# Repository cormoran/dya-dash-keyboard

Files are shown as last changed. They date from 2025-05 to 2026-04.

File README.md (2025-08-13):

#  DYA Dash Split Keyboard

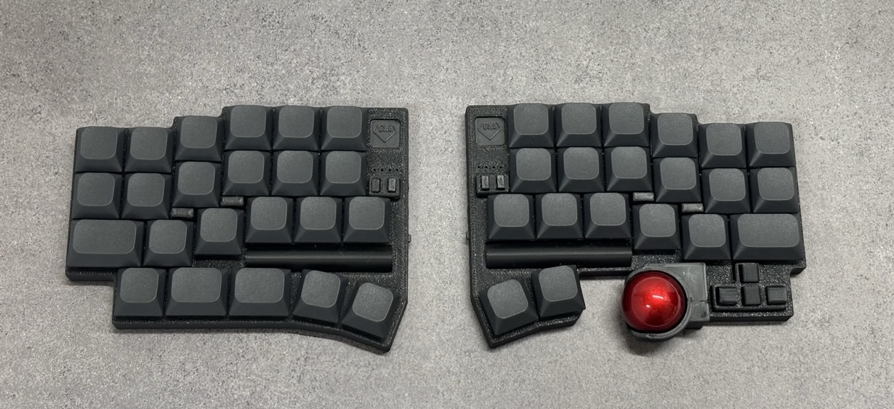
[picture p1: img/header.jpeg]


## Features

- Controller: XIAO NRF52840
- Firmware: ZMK
- Switch: Kailh Choc v2, hotswappable (2pin)
- AAA battery (1.2V NiMH or 1.5V)
- Touch sensor buttons ([See movie how it works](https://x.com/cormoran707/status/1916127921720463540))
- PMW3610 low power trackball sensor
- LED x 4 x 2 for BLE profile, battery level indication ([See movie how it works](https://youtu.be/y6X2OnoMX-M))
- Hardware capability for below features (Not tested yet)
  - Dual trackball support
  - Wired connection

## Build Guide

- [V2.0 ビルドガイド](./hardware/dya-dash/build-guide/v2/BuildGuide.md)
- [V1.0 (試作) ビルドガイド](./hardware/dya-dash/build-guide/v1/BuildGuide.md)

## Firmware

Firmware is available in https://github.com/cormoran/zmk-keyboard-dya-dash.

You can download pre-built binaries in [the release page](https://github.com/cormoran/zmk-keyboard-dya-dash/releases).

The firmware supports keymapping update with [ZMK studio](https://zmk.studio/).

## Gallery

### Schematic

Left side schematic

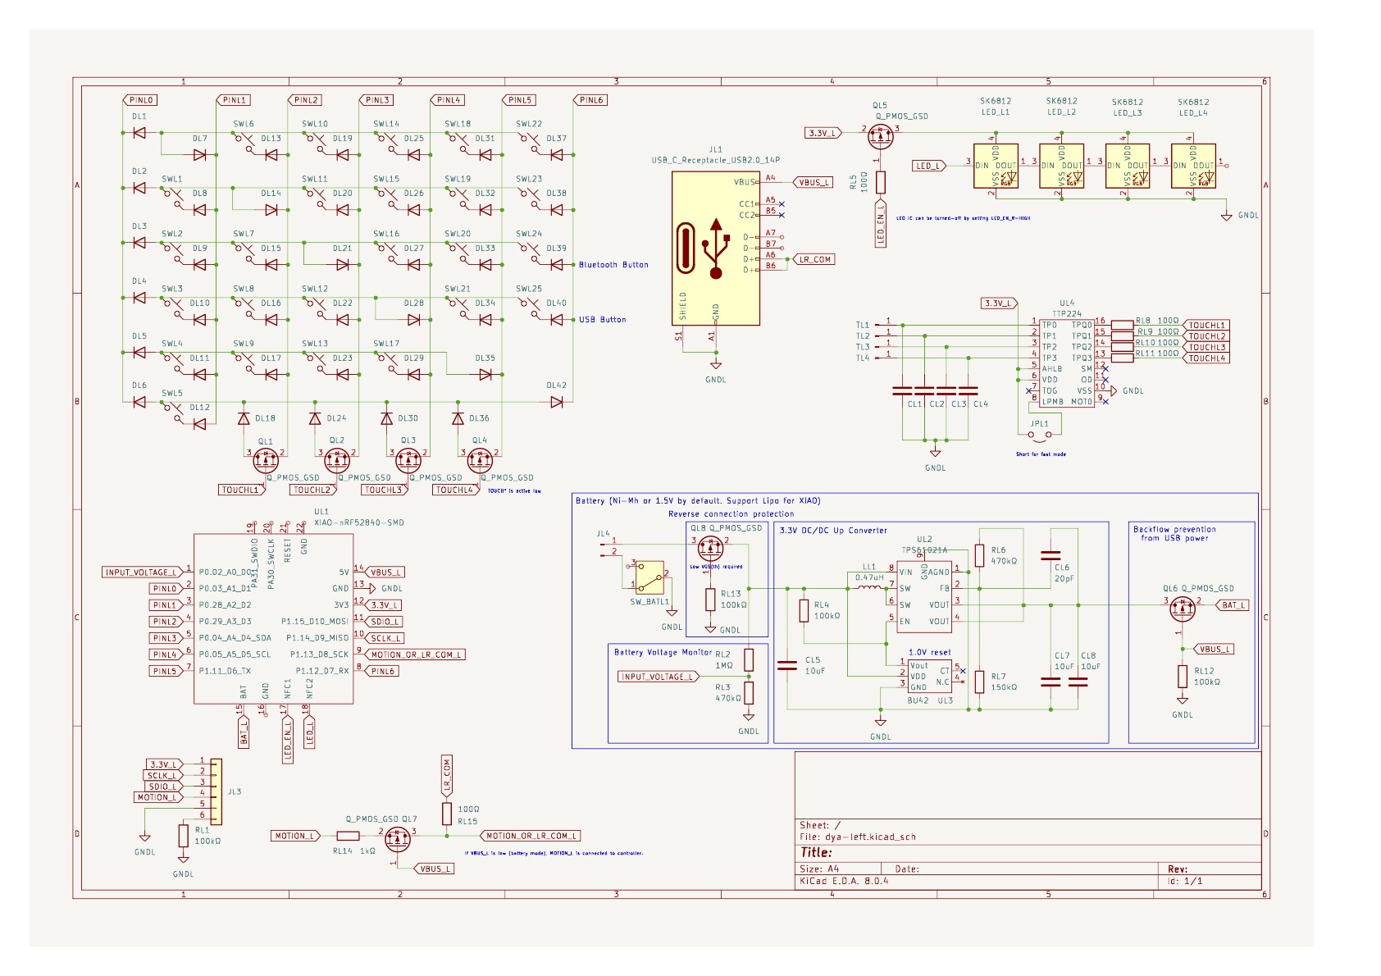
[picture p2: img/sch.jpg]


### Double trackball supported

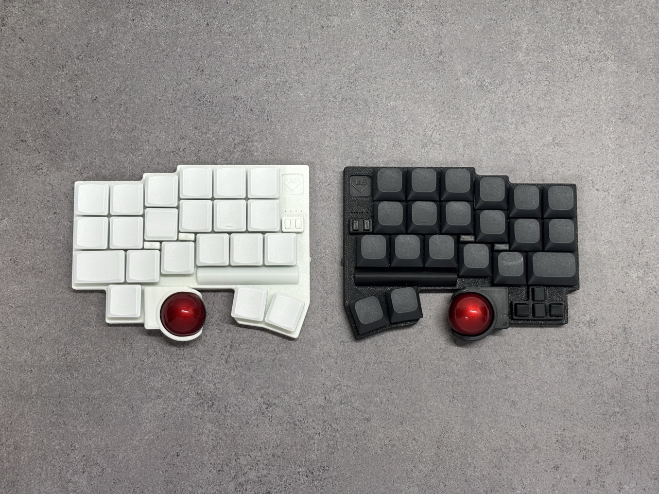
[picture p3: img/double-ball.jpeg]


### Colors

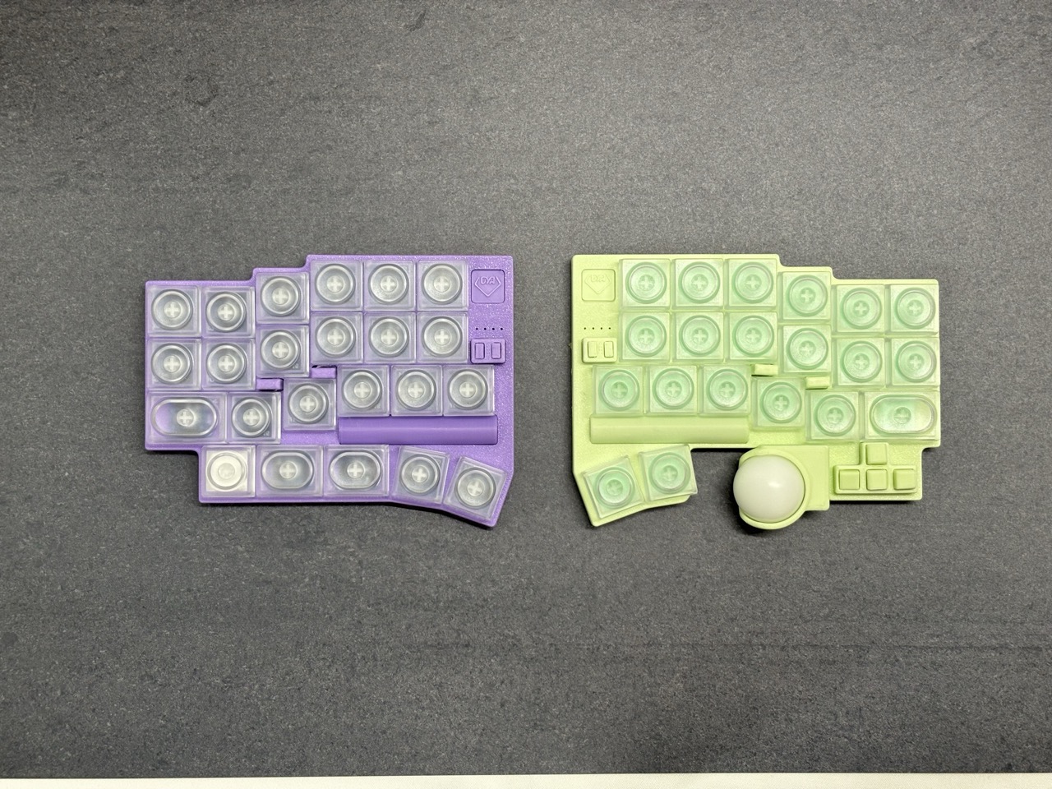
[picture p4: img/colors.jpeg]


### Bottom

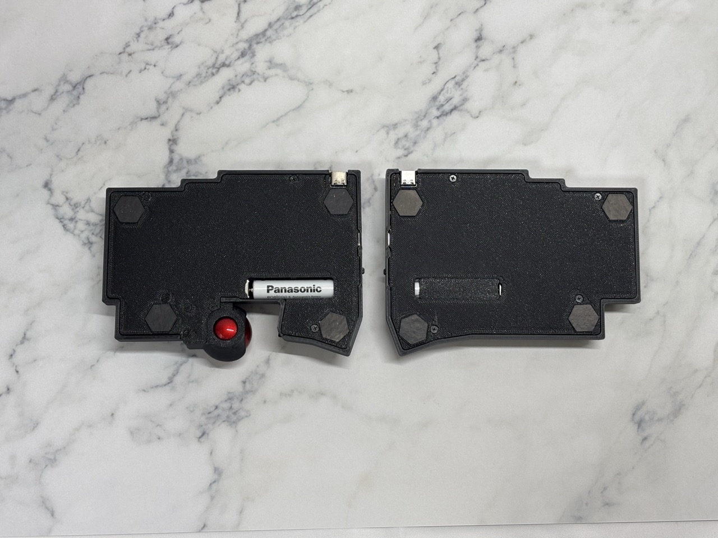
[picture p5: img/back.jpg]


### LED indicators

4x2 LEDs indicates battery level, connected BLE/USB profiles and active layers depending on the setting.
The schematic and firmware driver is optimized for battery usage. LED modules consume power only when required.

> [!NOTE]
> The picture is old version's one

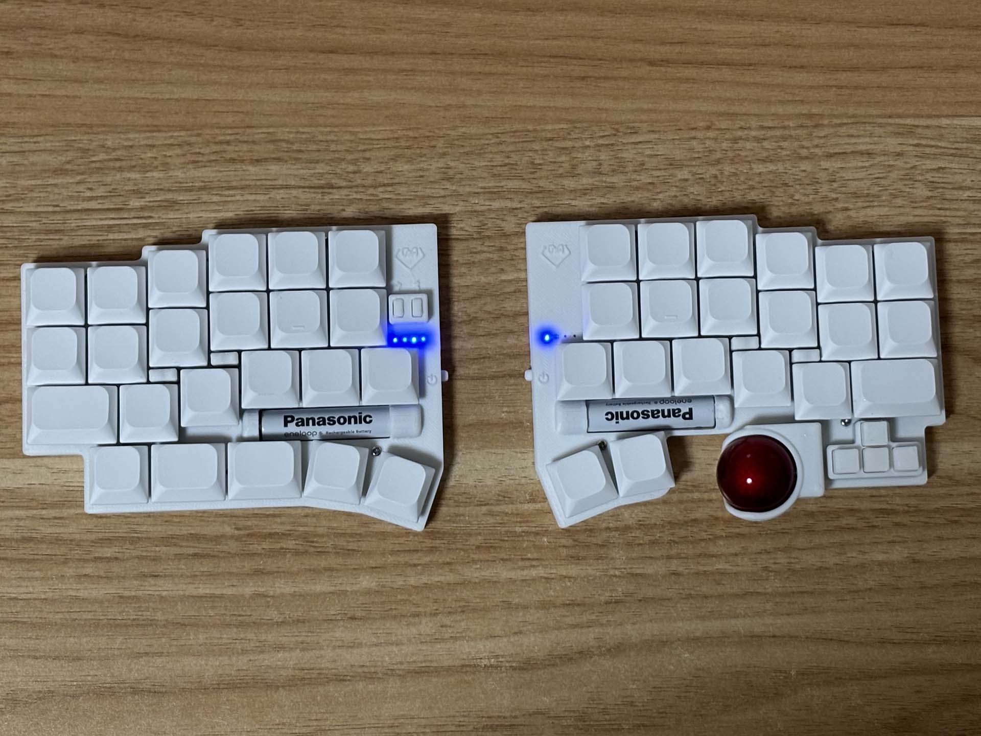
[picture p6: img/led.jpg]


## Shop

Now on sale in https://cormoran707.booth.pm/

## License

- Firmware (./firmware): MIT. See detail in each git submodule.
- DYA logo  (./img/dya.svg): All rights reserved.
- Other keyboard pictures under ./img: CC BY
- Hardware
  - kicad library (./hardware/kicad_library/\*) and sch (\*.kicad_sch): MIT
  - PCB (\*.kicad_pcb): CC BY-NC
  - Case data (\*.stl): CC BY

完全なコピー品が販売された場合に対応できるように PCB 設計を流用して販売することは禁止していますが、回路設計を真似たり似たような設計のキーボードを作ることを牽制したりする意図はありません。

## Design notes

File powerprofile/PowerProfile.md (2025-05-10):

# DYA Dash Power Profiling

- Tool: https://www.nordicsemi.jp/tools/ppk2/
- Battery: [Panasonic eneloop AAA(単４)](https://panasonic.jp/battery/feature/eneloop.html) 1.2V 800mAh boosted to 3.3V

## Setup

- Normal status: LED module can be ON if LED is used. Otherwise OFF. BLE is ON.
- Idle status: LED module is OFF, BLE is ON.
- Deep sleep: all power off except for GPIO interrupt and PMW3610.

No key press. No trackball movement in below data.
Power consumption increases more when key pressed or trackball is moving.
Profiling analysis for daily usage is coming soon...

## Peripheral

Idle status consumes 1.05mA in avg.

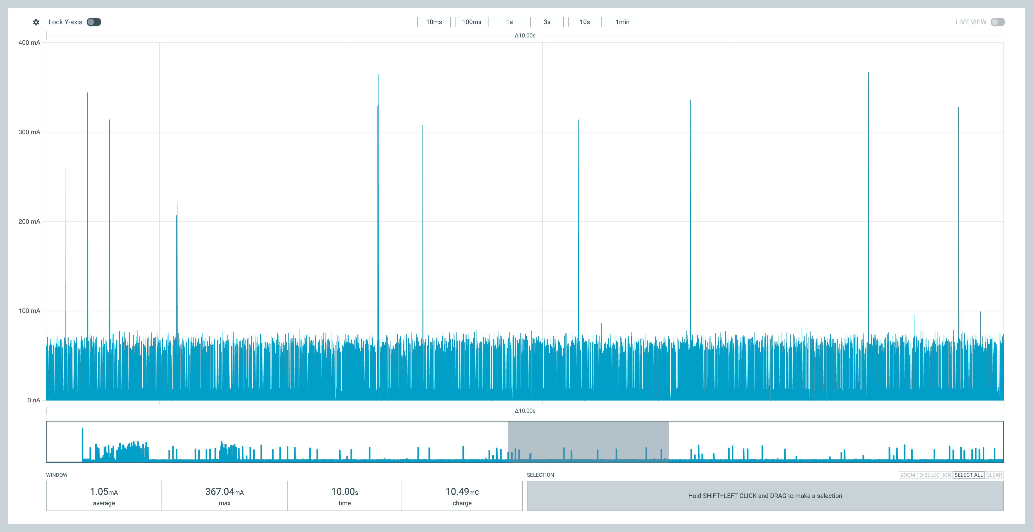
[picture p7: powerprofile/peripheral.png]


## Central

Normal status with LED module OFF consumes 3.81mA in avg.

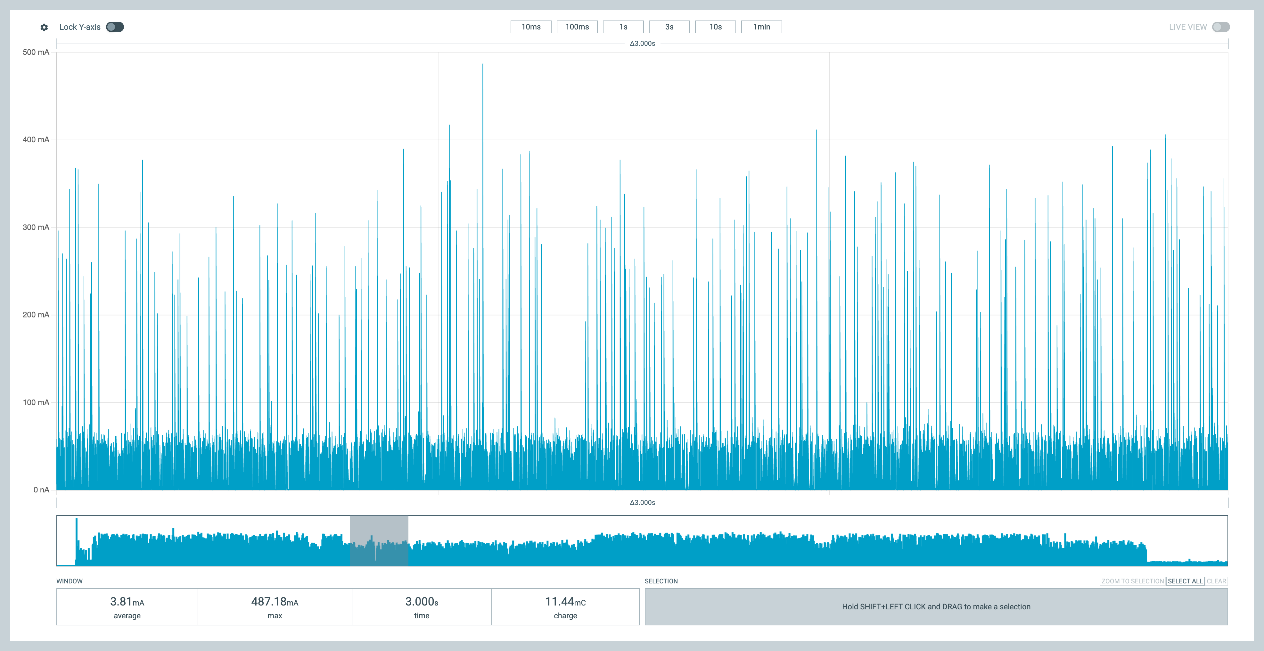
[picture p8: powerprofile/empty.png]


Normal status with LED module ON (RGB=black(0,0,0)) consumes 8.40mA in avg.
The increase is likely due to RGB LED module's embedded chip.

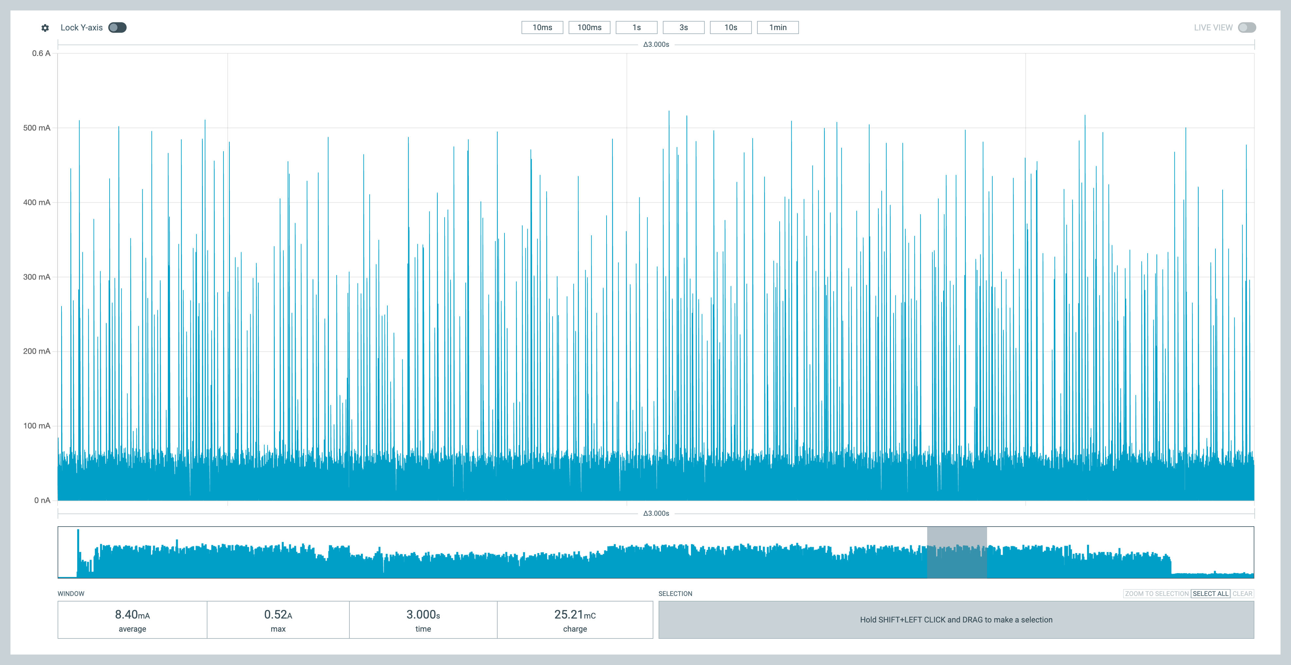
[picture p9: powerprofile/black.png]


Normal status with Red LED ON (Brightness is adjusted to very small) consumes 15.07mA.

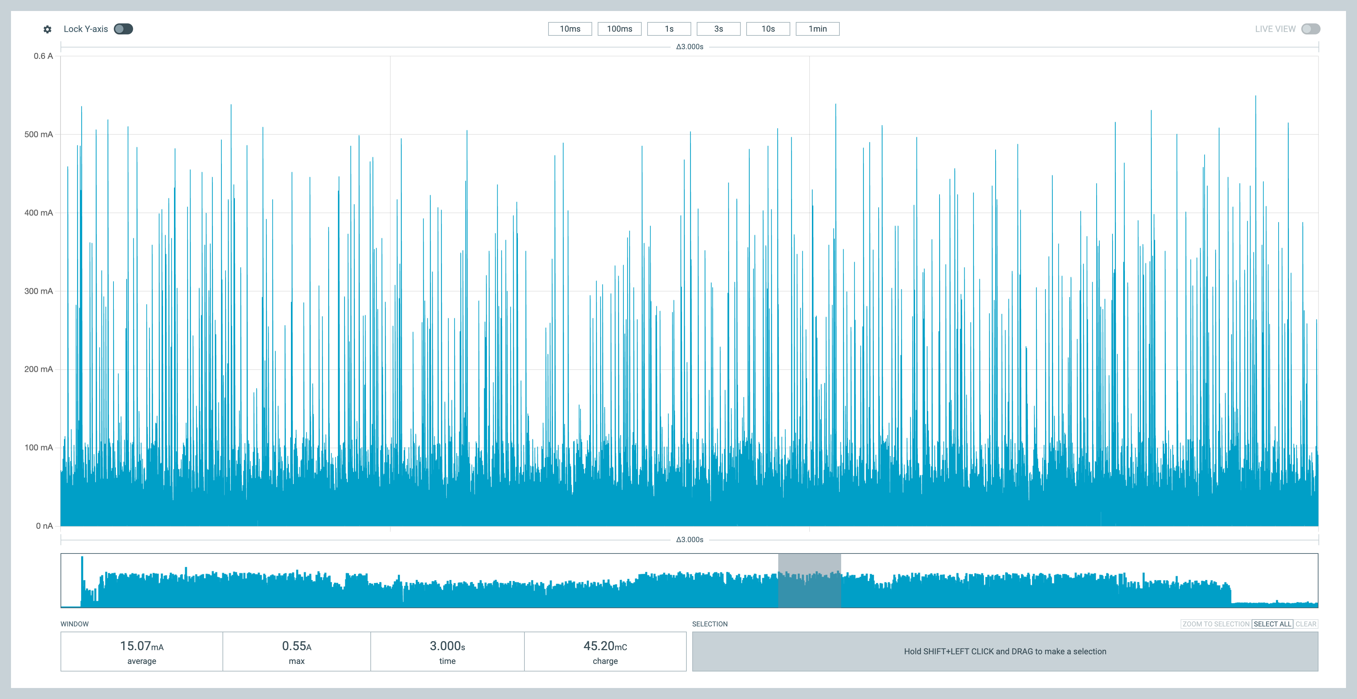
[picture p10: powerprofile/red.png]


Deep sleep mode consumes 270uA.

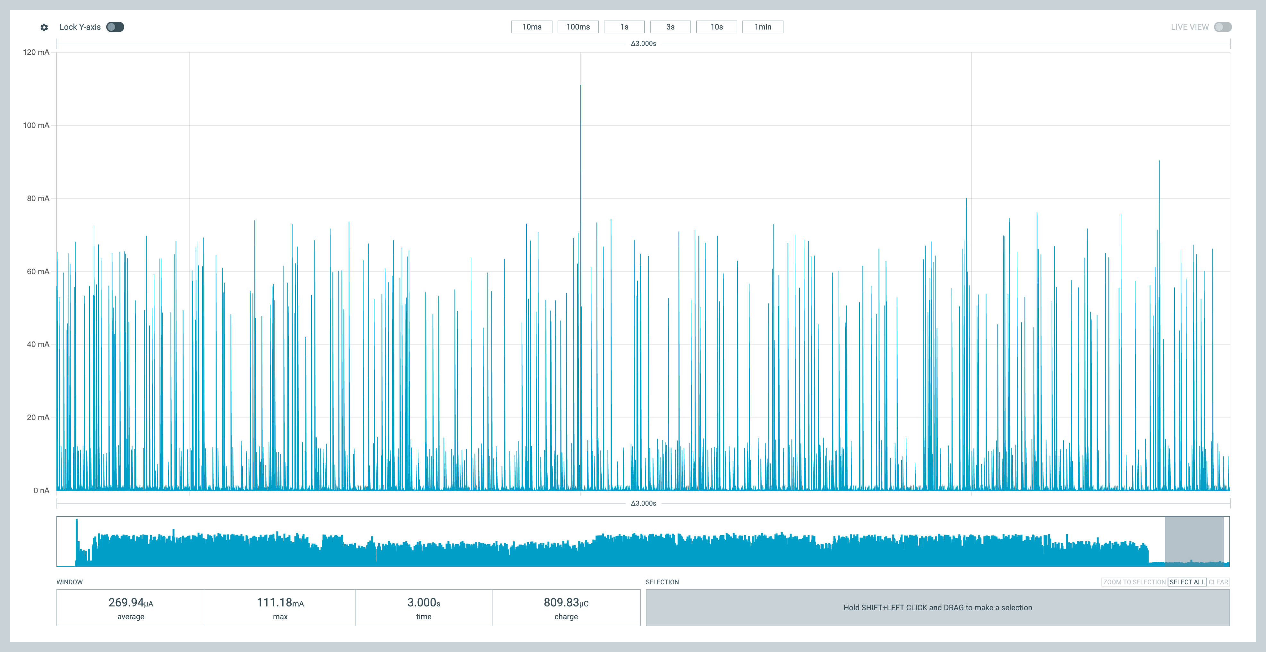
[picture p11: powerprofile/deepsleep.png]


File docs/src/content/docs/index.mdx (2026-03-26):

---
title: DYA Dash
template: splash
hero:
  title: |
    DYA Logo
    DYA Dash
  tagline: 電池で動く分割型トラックボール付きキーボード
  image:
    file: ../../assets/header.jpeg
    alt: DYA Dash キーボード
  actions:
    - text: ビルドガイド(V3)
      link: /dya-dash-keyboard/build-guide/v3/
      icon: right-arrow
      variant: primary
    - text: 設計データ
      link: https://github.com/cormoran/dya-dash-keyboard
      icon: github
      variant: secondary
    - text: ビルドキットを購入
      link: https://cormoran707.booth.pm/items/6913095
      icon: information
      variant: minimal
---

import { Card, CardGrid } from "@astrojs/starlight/components";

## 特徴

<CardGrid>
  <Card title="無線左右分割キーボード">
    自由な手の位置でタイピングできます。

    裏側にはマグネットが付いており、持ち運びを考えた設計になっています。

  </Card>
  <Card title="25mm トラックボール内蔵">
    マウスを持ち替えることなく、カーソル操作が可能です。

    外出先でもトラックボールを使った快適な操作ができます。

  </Card>
  <Card title="タッチセンサー搭載">
    トラックボールのスクロールモード切り替えなどに使えるタッチセンサーを左右に4つ(V2 までは2つ)ずつ搭載しています。
  </Card>
  <Card title="電池駆動" >
    左右はそれぞれ単４電池１本ずつで動作します。

    リチウムポリマーバッテリーと比べて発火の心配が低く、安心して使用できます。

  </Card>
  <Card title="配列">
    Column Staggered 配列の美しさと使い慣れた Row Staggered 配列の特徴を兼ね備えています。

    Column Staggered 配列が合わない方でも違和感が少なく使えるように設計されています。

  </Card>
  <Card title="自由なカスタマイズ">
    ZMKファームウェアを使っておりソースコードも公開しているので、キーマップやマクロ、細かな振る舞いを自由にカスタマイズできます。
  </Card>
</CardGrid>

## 写真

import doubleBall from "../../assets/double-ball.jpeg";
import colors from "../../assets/colors.jpeg";
import back from "../../assets/back.jpg";
import led from "../../assets/led.jpg";

<CardGrid>

<Card>
  
</Card>

<Card>
  
</Card>

<Card>
  
</Card>

<Card>
  
</Card>

</CardGrid>

## バージョン情報

V3, rev3 という表記の揺れがありますが、V と rev は両方同じものを指しています。紛らわしくてすみません。

- **V3** (2026/03) - 現在の最新版。マイコンを XIAO nRF52840 Plus 変更、内部構造を大幅に変更。後方互換性なし。
- **V2** (2025/06) - 正式販売版（V1.1 と命名しても良かった）
- **V1** (2025/05) - 試作版

## サポート

- **販売・サポート**: [Booth](https://cormoran707.booth.pm)
- **技術情報・ソースコード**: [GitHub](https://github.com/cormoran/dya-dash-keyboard)
- **最新情報**: X [@cormoran707](https://twitter.com/cormoran707)

---

_このドキュメントサイトは半分 AI に作ってもらいました。_

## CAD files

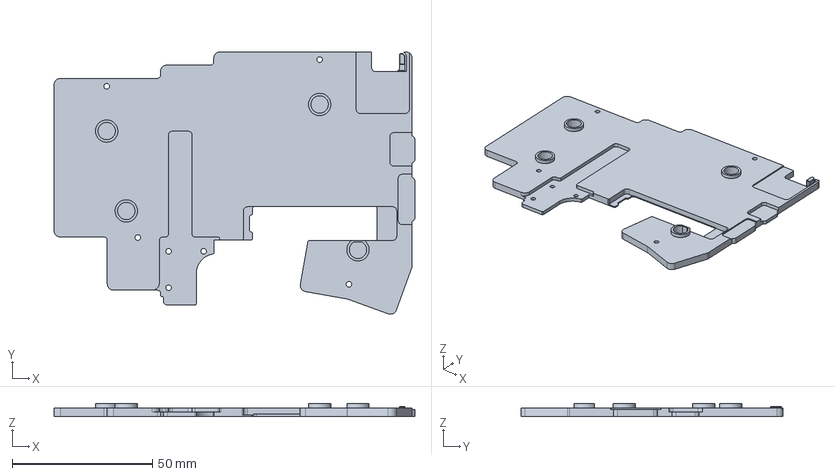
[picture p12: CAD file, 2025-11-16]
hardware/dya-dash/case/V2.1/DyaDashBottomCaseLeftTrackball.step
128.8 x 93.7 x 4.50 mm

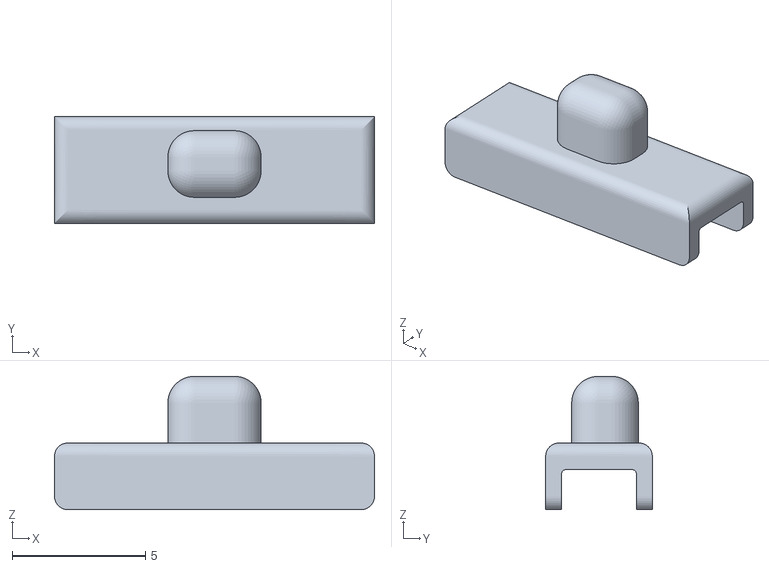
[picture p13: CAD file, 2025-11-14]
hardware/dya-dash/case/V2.1/BatterySwitch.stl
12.0 x 4.00 x 5.00

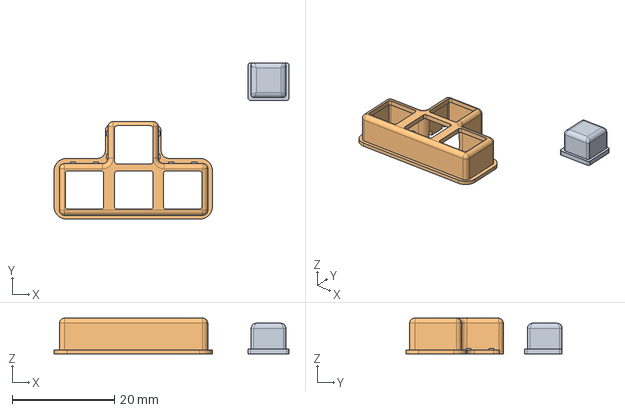
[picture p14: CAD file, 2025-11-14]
hardware/dya-dash/case/V2.1/ArrowButton.step
46.0 x 30.6 x 7.00 mm

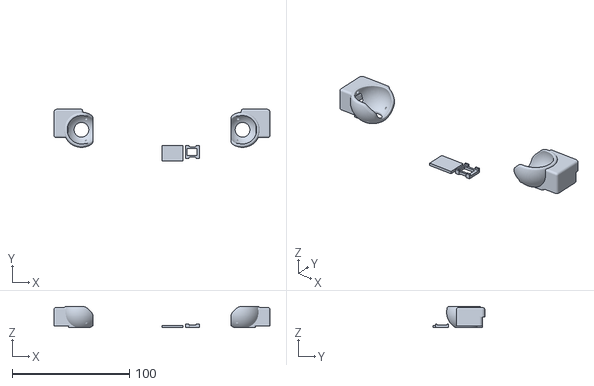
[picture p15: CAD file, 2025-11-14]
hardware/dya-dash/case/V2.1/Trackball.stl
184.0 x 43.9 x 18.0

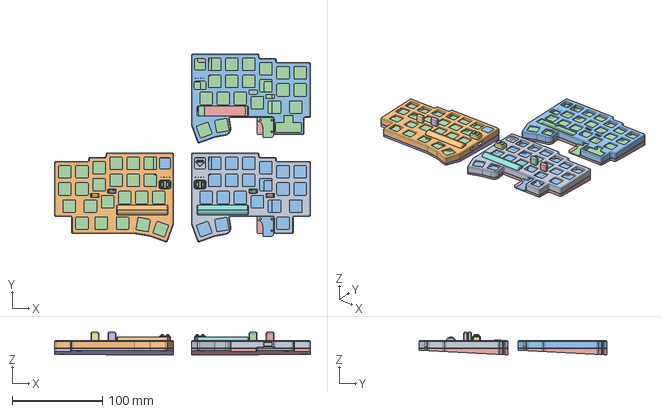
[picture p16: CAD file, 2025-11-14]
hardware/dya-dash/case/V2.1/DyaDash.step
284.4 x 208.9 x 25.3 mm

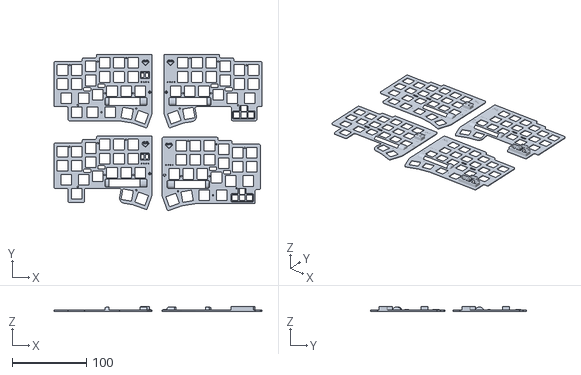
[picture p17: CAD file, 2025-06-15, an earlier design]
hardware/dya-dash/case/V1/top-3dp.stl
280.0 x 210.4 x 7.00

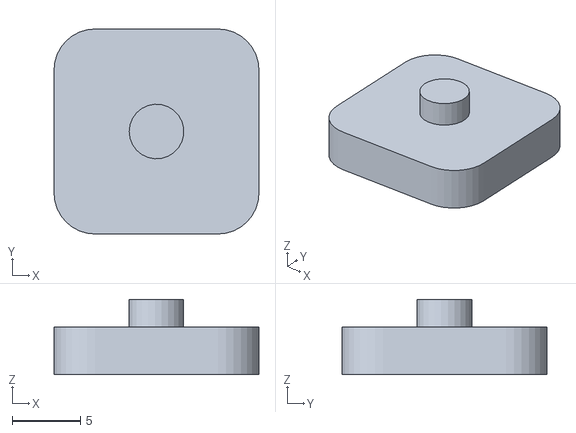
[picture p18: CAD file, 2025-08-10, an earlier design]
hardware/dya-dash/case/V2/Parts_Zig.stl
15.0 x 15.0 x 5.50

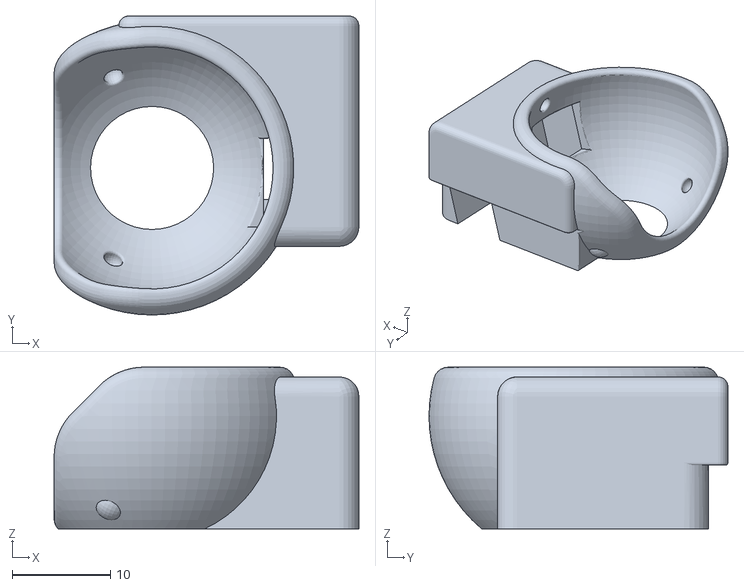
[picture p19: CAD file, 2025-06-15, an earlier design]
hardware/dya-dash/case/V1/trackball-right.stl
31.1 x 30.5 x 16.5

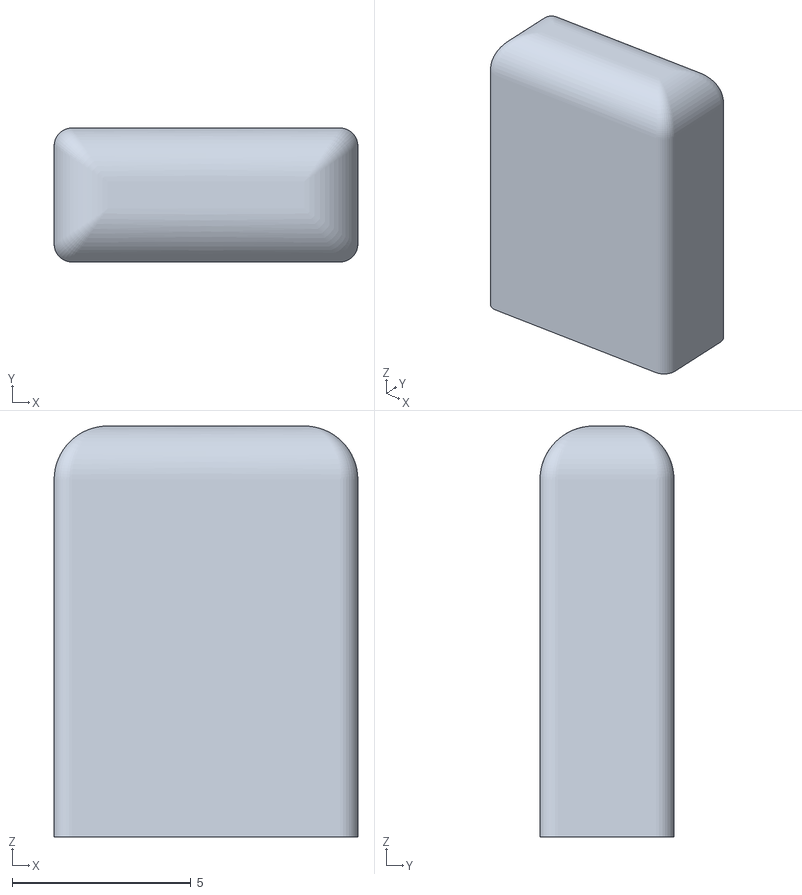
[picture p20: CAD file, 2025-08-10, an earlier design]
hardware/dya-dash/case/V2/Parts_TouchButton.stl
8.50 x 3.75 x 11.5

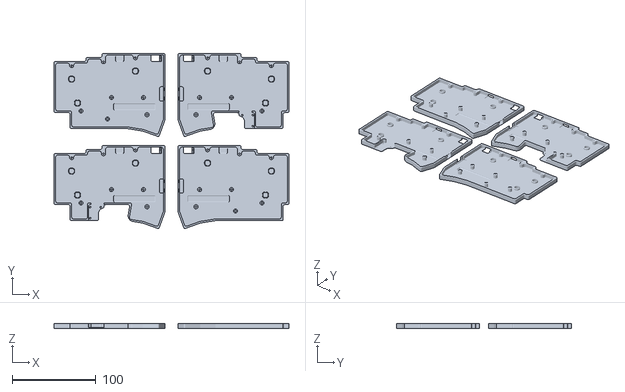
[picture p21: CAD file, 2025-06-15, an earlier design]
hardware/dya-dash/case/V1/bottom.stl
280.0 x 208.5 x 6.00

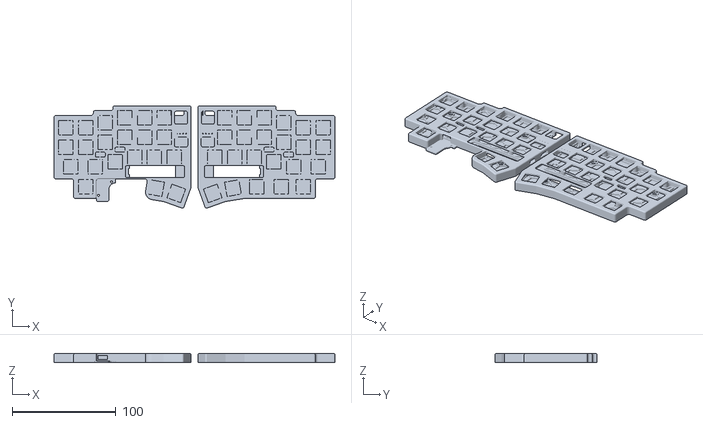
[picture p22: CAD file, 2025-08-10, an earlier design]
hardware/dya-dash/case/V2/Case_LeftTrackball_NoArrow.stl
271.3 x 98.9 x 8.50

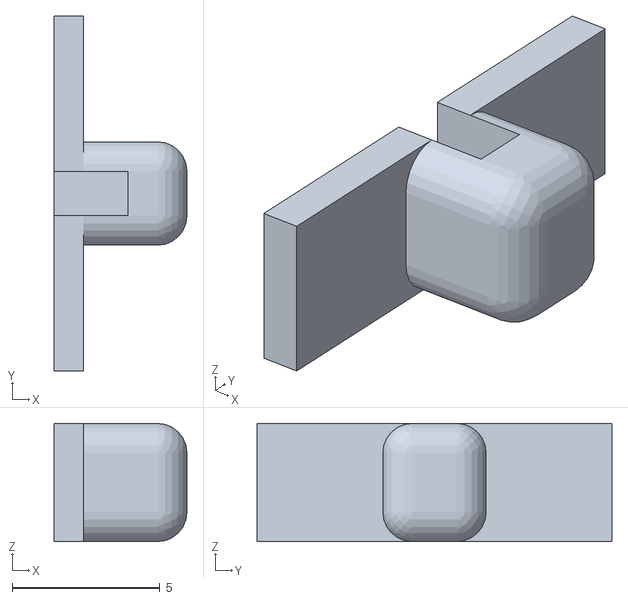
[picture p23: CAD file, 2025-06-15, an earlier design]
hardware/dya-dash/case/V1/battery-button.stl
4.50 x 12.0 x 4.00

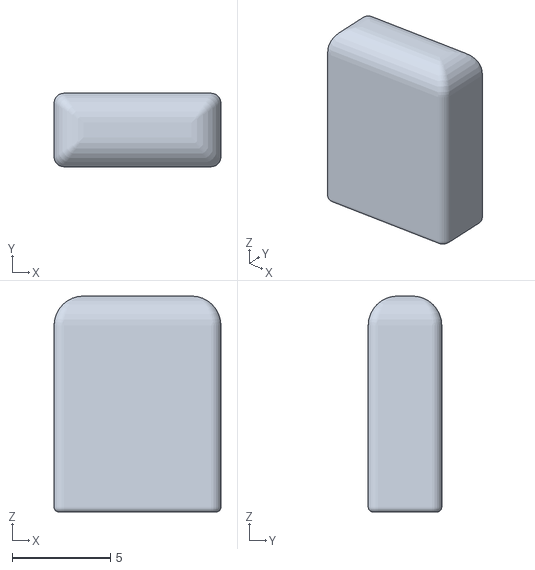
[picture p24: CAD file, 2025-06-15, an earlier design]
hardware/dya-dash/case/V1/touch-button.stl
8.50 x 3.75 x 11.0

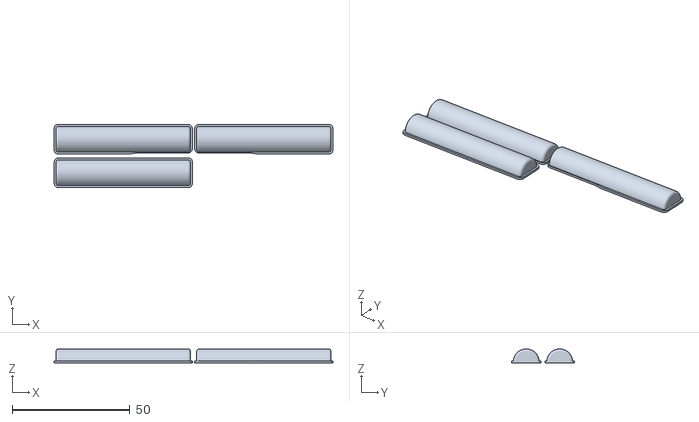
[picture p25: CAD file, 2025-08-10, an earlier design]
hardware/dya-dash/case/V2/Parts_BatteryTopCovers.stl
118.4 x 26.9 x 6.00

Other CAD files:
hardware/dya-dash/case/V2/Parts_Arrow.stl
hardware/dya-dash/case/V1/trackball-left.stl
hardware/dya-dash/case/V2/Parts_PowerSwitch.stl
hardware/dya-dash/case/V1/arrow-button.stl
hardware/dya-dash/case/V2/Case_DualTrackball_NoArrow.stl
hardware/dya-dash/case/V2/Case_RightTrackball_NoArrow.stl
hardware/dya-dash/case/V2/Case_RightTrackball_WithArrow.stl
hardware/dya-dash/case/V2/Parts_BatteryBottomCover.stl
hardware/dya-dash/case/V2/Parts_Emblem_dya-dash-for-jlcpcb-emblem v2.stl
hardware/dya-dash/case/V2/Parts_SettingButton.stl
hardware/dya-dash/case/V2/Parts_SettingCover.stl
hardware/dya-dash/case/V2/TrackballCase_Adjuster.stl
hardware/dya-dash/case/V2/TrackballCase_Left.stl
hardware/dya-dash/case/V2/TrackballCase_Right.stl

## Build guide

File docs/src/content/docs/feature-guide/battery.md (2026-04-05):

---
title: バッテリー残量表示
sidebar:
  order: 5
---

:::note

こちらのページの情報は V2, V3 共通です。画像は V2 のものですが内容は同じです。

:::

電源を入れた際に左右のバッテリー残量が LED に表示されます。

バッテリー残量は、４つの LED x 3 色で 12 段階表示されます。

- ４つの LED: 左から 25%ずつに対応
- 色: 残量が多い側から緑 → 黄 → 赤で変化

例えば下の図で、左手の緑緑緑は以下のように読みます

- ４つ目が点灯していないので -25%で 75%以下
- ３つ目が緑なので、50%から 75%の間で残量が多い方（３分割した一番多い区間にある）

右手の緑緑黄状態は以下のように読みます

- ４つ目が点灯していないので -25%で 75%以下
- ３つ目が黄色なので、50%から 75%の間でちょうど真ん中あたり（３分割した真ん中の区間にある）

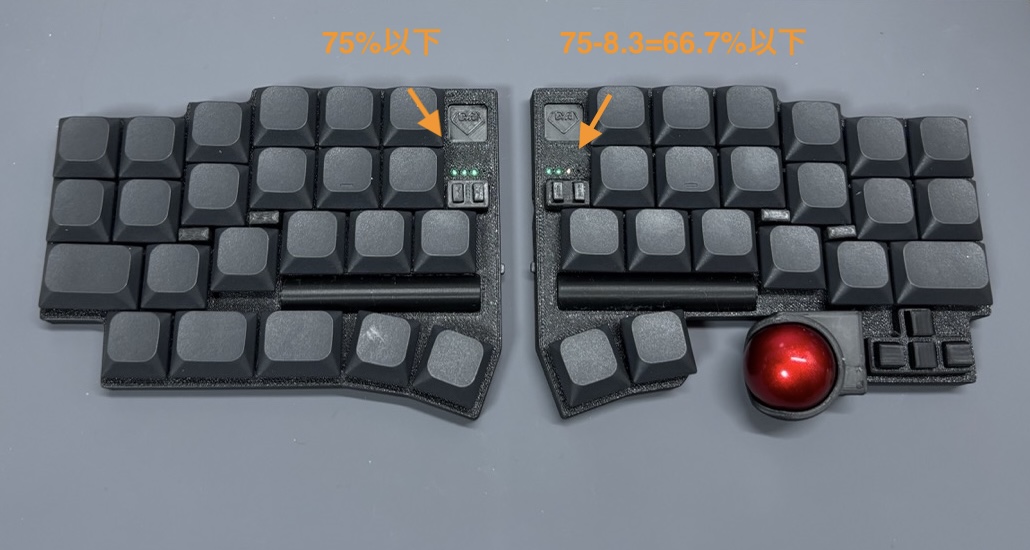
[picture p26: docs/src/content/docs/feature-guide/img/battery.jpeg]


:::note

残量表示はニッケル水素電池の電圧曲線に従って実装していますが、回路による電圧降下もあるため、実態に則しているかはまだあまり詳しく調べられていません。

全然違う気がした場合は教えてください。

:::

## 残量を確認する方法

電源を切らずに残量を確認するためには、左手左下+t を押します。
しばらくの間 LED が電池残量を表示します。

その他、残量がすくなくなったら定期的に LED をアラート点灯させる機能もついています。

## 電池持ちの分析

以下の記事でより詳しい Power profile 結果を解説しています。回路は V1 のものを使用したので V2 では少しだけ状況が変わっている可能性があります。

- [XIAO nrf52840 と ZMK を使ったキーボードのスリープ時消費電力](https://note.com/cormoran/n/n72a9d815ed55)
- [XIAO nrf52840 と ZMK を使ったトラックボールキーボード使用時の消費電力](https://note.com/cormoran/n/n7cd3f64d9a13)

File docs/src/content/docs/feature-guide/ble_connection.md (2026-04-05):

---
title: 接続先の切り替え
sidebar:
  order: 3
---

:::note

V2, V3 でデフォルトのキーマップが違います。説明は V3 向けに書き足しましたが、画像は V2 のもののままになっています。

:::

DYA Dash は BLE 無線接続と USB 有線接続の両方に対応しています。

## 無線接続

- V2: 左手の設定ボタン右で４つの無線接続先を切り替えられ、右手の LED に接続状態が表示されます。
- V3: 左手の設定ボタンで４つの無線接続先を切り替えられます
  - 左手設定ボタン左: 現在の接続先番号-1に接続 (4->3->2->1->4->...)
  - 左手設定ボタン右: 現在の接続先番号+1に接続 (1->2->3->4->1->...)

右手の４つの LED は左側から順に接続先 1, 2, 3, 4 に対応します。

右手の LED の色:

- 黄色: ペアリング待機中
- 青色: 接続済み
- 赤色: ペアリング済みの接続先に接続試行中

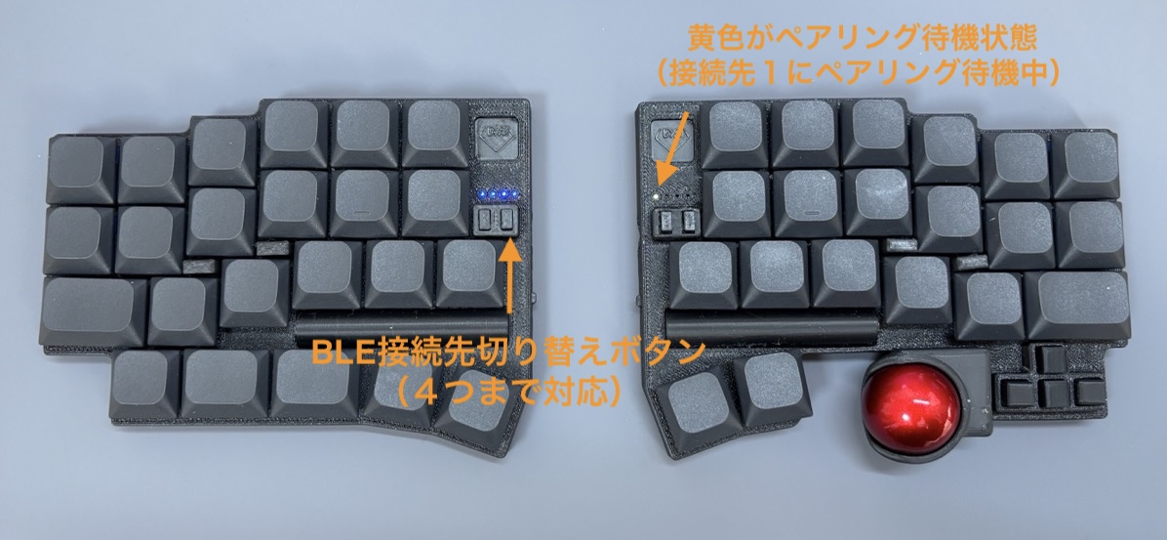
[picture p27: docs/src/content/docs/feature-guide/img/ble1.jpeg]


### 新しくペアリングする方法

BLE 接続先切り替えボタンを押すと、接続先の選択が１ → ２ → ３ → ４ → １というようにサイクルしていきます。

選択した接続先がペアリングされていない場合に自動的にペアリングモード(LED 黄色)になって、PC やスマートフォンの Bluetooth ペアリング設定からペアリングができます。

### ペアリングを変更・解除する方法

ペアリング先を変更したい場合は一度解除して新しくペアリングをします。

ペアリングの解除は以下の手順で行えます。

1. 左手設定ボタン(右)で解除したい接続先を選択
2. 現在選択している接続先とのペアリングを解除
   - V2: 左手左下のキー + 左手設定ボタン右
   - V3: 左手の設定ボタンどちらかを５秒以上長押し
3. 解除した接続先の PC の Bluetooth 設定からペアリングを解除
   - これをしないとその PC からは再度ペアリングができません。

2, 3 の順序はどちらでも良いですが、再ペアリングする場合はキーボードと PC の両方でペアリング解除されている必要がある点に注意してください。

### 接続先を確認する方法

電池で動いている場合、消費電力を削減するため右手の LED は一定時間後に自動で消えるようになっています。

以下のどれかの方法で LED を通じて現在の接続先を確認できます。

- 左手左下+g: 一定時間 LED が点灯して 右側の LED にペアリング状態を表示します
- 電源を入れ直す: 電源を入れ直すとバッテリー残量表示後に接続先が表示されます
- USB 給電: 右手に USB で給電すると LED が常点灯状態になって接続先が表示されます

## USB 接続

右手を PC と USB 接続した状態で以下のボタンを押すと USB/BLE 優先モードを切り替えられます。

- V2: 左手の設定ボタン左
- V3: 左手の設定ボタン２つを同時押し

USB 接続が優先されているときは右手のいくつかの LED が緑に光ります。

以下の状態は BLE 接続が優先されて、入力が BLE に出力される状態です。

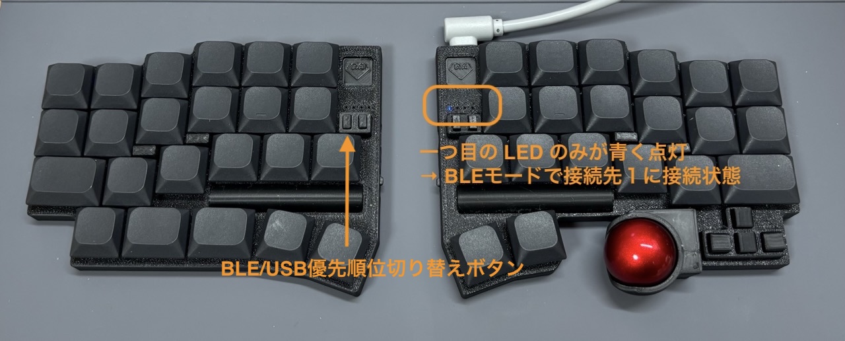
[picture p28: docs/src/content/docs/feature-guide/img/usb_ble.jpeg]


以下の状態は USB 接続が優先されて、入力が USB に出力される状態です。

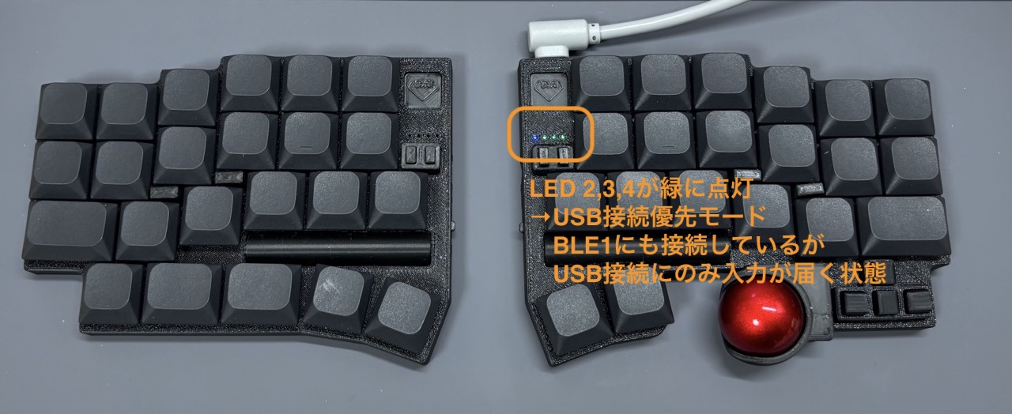
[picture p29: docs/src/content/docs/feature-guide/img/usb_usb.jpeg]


BLE 接続が解除された時に USB 接続状態だった場合、優先モードに関わらず入力は USB に出力されるようになります。

## 豆知識

ZMK の仕様で USB 接続時でも BLE 接続を完全に切断することはできません。ZMK は常に選択された BLE 接続先に接続を試みるようになっています。

さらに、通常は BLE 接続先を複数設定した場合、接続先を切り替えてもそれまでの BLE 接続が維持されるのですが、DYA Dash では接続先切り替え時に元の接続先との接続を切断するようにカスタマイズしています。

このカスタマイズで BLE 接続の安定性が向上していますが、接続先を頻繁に切り替える場合は再接続に少し時間がかかる欠点もあります。

カスタマイズは macro で実現しているので、デフォルトの設定が気に入らない場合は各自で変更してください。

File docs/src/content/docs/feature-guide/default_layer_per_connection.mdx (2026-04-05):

---
title: 接続先ごとにキーマップを変える
description: DYA Dash のデフォルトキーマップの解説
sidebar:
  order: 4
---

:::note

V2, V3 でデフォルトのキーマップが少し違いますが以下の内容は両方で有効です。

:::

Windows PC と Mac や iPad など複数の OS とペアリングしている場合、OS ごとに必要なキーマップが違っていて困ります。

DYA Dash には、接続先（BLE1, 2, 3, 4, USB）ごとにデフォルトレイヤーを切り替える機能が実装されています。

:::note

この機能は接続先の PC を識別してるわけではありません。例えば、USB を他の PC に差し替えるような場合は接続先ごとの切り替えはできません。

:::

左手左下キー + 左手設定ボタン左を押すたびに、現在選択されている接続先のデフォルトレイヤーが 1 → 2 → 3 → 4 ... と切り替わります。

ファームウェアで設定された最大値まで上がると 1 に戻ります。

切り替え中はアクティブなレイヤーが左右の LED に表示されるので、どのレイヤーがデフォルトに設置されたかが容易にわかるようになっています。

- レイヤー１はベースレイヤーで常にアクティブになるので、左の一つ目の LED は常に点灯します
- レイヤー８は ConfigLayer で、左手左下キーを押している間アクティブになるので、右の四つ目の LED はこの操作中常に点灯します。
- LED の色はレイヤーごとに OS のイメージに合いそうな色を選んでファームウェアで設定しています。
  - Layer2: Windows 空色
  - Layer3: Mac 赤色
  - Layer4: iOS 白色
  - Layer5: Linux オレンジ
- 上のマッピングはあくまでおすすめとして設定してだけなので、どのレイヤーをどの OS 向けに割り当てるかは自由です。

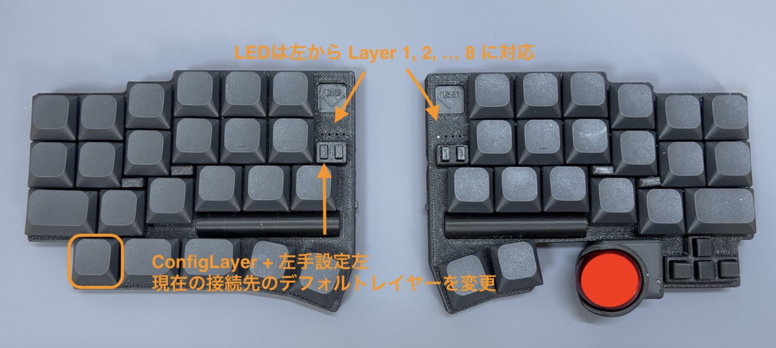
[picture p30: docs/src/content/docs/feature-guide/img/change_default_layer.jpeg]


import { YouTube } from "astro-embed";

<YouTube id="PggxfXZUtnA" posterQuality="high" />

## アクティブなレイヤーの確認

左手左下+左手 b を押すと、現在アクティブなレイヤーが左右の LED に表示されます。

LED は左手左から順にレイヤー１、２、３、４ ... と レイヤー８まで表示に対応しています。

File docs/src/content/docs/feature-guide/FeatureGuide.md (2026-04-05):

---
title: Feature Guide
description: DYA Dash features
sidebar:
  order: 0
---

DYA Dash を使ったりソフトウェアを改造したりする上で知っておくと良さそうな内容を走り書きしたページです。

:::note

このページは現在 V2 向けに書かれています。

:::

## 左右の役割

- 右手側のキーボードが親機として動きます。PC と有線接続する場合は右側の XIAO に USB ケーブルを接続してください。
- 左手側のキーボードは子機として右手のキーボードと通信しています。左手の XAIO に USB ケーブルを接続した場合は電源供給のみが行われます。
- キーボードには　 XAIO の USB ポートに加えて左右接続用の USB ポートがありますが、有線での左右接続にはまだ未対応です。今のところ電源供給（XIAO の USB ポートから入力された電源をもう片方のキーボードにバイパスする）用途でのみ使用できます。

## デフォルトのキー配列

[デフォルトキーマップ](/dya-dash-keyboard/feature-guide/default_keymap) に移動しました

## ファームウェアのビルド方法

以下のレポジトリにコードがあります。README の説明を読んでください。

https://github.com/cormoran/zmk-keyboard-dya-dash

キーマップの変更は [キーマップのカスタマイズ](/dya-dash-keyboard/feature-guide/customize_keymap) を見てください。

## 電池持ちなど

以下の記事でより詳しい Power profile 結果を解説しています。回路は V1 のものを使用したので V2 では少しだけ状況が変わっている可能性があります。

- [XIAO nrf52840 と ZMK を使ったキーボードのスリープ時消費電力](https://note.com/cormoran/n/n72a9d815ed55)
- [XIAO nrf52840 と ZMK を使ったトラックボールキーボード使用時の消費電力](https://note.com/cormoran/n/n7cd3f64d9a13)

電池残量については [バッテリー残量表示](/dya-dash-keyboard/feature-guide/battery/)をご覧ください。

### 電源回路の補足

DAY Dash の電源回路では電池の電圧を 3.3V まで昇圧しています。電池の電圧が 1V を下回ると昇圧回路がオフになるように設計していますが、電池電圧の測定などの部分で微弱な電流が流れ続けます。電流が流れ続けると過放電の状態になるので、動かなくなるまで使い切るのではなく、電池残量が減ったら電池交換することをお勧めします。

また、電源回路には USB の電源が電池の方向に流れないようにする逆流防止回路を組み込んでいます。そのため USB 接続している時に電池の電源スイッチをオンにしても大丈夫なはずです。
一応逆流防止がうまく動いてそうなことは確認できていますが、作者は電子回路のプロではないのでうまく動かないケースがあるのではないかと少し心配しています。
なお、実装している逆流防止回路は XIAO の USB 電源回路と合わさって初めてうまく動くような設計になっています。他のマイコン（e.g. RP2040-Zero）で同じような回路を組んでもうまく動かないと思うので真似したい人は注意してください。

V2 回路では、電池を間違って逆に接続してしまった時の保護回路を追加しました。

### LED の輝度

基板に付いている４つの LED を全力（RGB=255,255,255）で点灯させると電池に 1A 以上の電流が流れました。
（昇圧後の部分に流れている電流はもっと少ない気がしますが）回路の配線パターンは大電流を流すことをあまり考えていないため、LED を全力で点灯させていると発熱したり、最悪配線パターンが焼き切れる可能性があります。
デフォルトのソフトウェアでは最大輝度を制限していますが、ソフトウェアを改造する人は LED の輝度はほどほどにしてください。（光らせすぎると目もくらみますし...）

### バッテリー残量の予測

[バッテリー残量表示](/dya-dash-keyboard/feature-guide/battery/)をご覧ください。

バッテリー残量はニッケル水素電池の電圧パターンを chat GPT に教えてもらって雑に区分線形関数近似で実現しています。
アルカリ乾電池などを常用する場合は、以下の値を変えてビルドするともっともらしい残量表示になります。

https://github.com/cormoran/dya-dash-keyboard/blob/27277f3221aaf06a4fc788ebab543c700398413d/firmware/zmk-module/zmk-keyboard-dya-dash/boards/shields/dya_dash/dya_das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

## 裏面マグネット

持ち運び時に便利なように左右のキーボードはマグネットで合わせられるようになっています。

## タッチセンサー

### 感度

タッチセンサーの感度は最大の状態になっています。もし感度が高すぎる場合は、基板にコンデンサを取り付けることで調整することが可能です。
調整するつもりでコンデンサーをつけない状態にしておいたのですが、そのままでなんか良さそうなので未調整の状態です。

### 余りのポート (V2のみ)

両方の基板に、親指付近と中指上付近にタッチセンサーの余っている２ポートにつながるパッドがあります。

動作未検証（少し無理して配線を伸ばしているので静電容量検知がうまくいかないかも）ですが、動きそうなら改造して遊んでもらえるのではないかと思います。

:::note

V3 では DYA2 と同じ仕組みでキーキャップの裏側に取り付けられるタッチパッドを導入したためあまりのポートはなくなりました。

V2 でもパッドから配線を伸ばしてうまくキーキャップの裏側に取り付けられるタッチパッドを固定できれば同様にタッチパッドを追加できるかもしれません。

:::

## 左右の有線接続

### V3

V3 では左右の有線接続が実装済みです。PC と USB 有線通信をしている時に下側の左右の USB ポートどうしを接続することで、左右の BLE 接続が解除されて自動的に有線通信に切り替わります。

### V2

トラックボールセンサーのモーション入力とキーボードの左右有線通信を共用するような回路設計をしているのでうまくプログラムを書けば有線通信が実装できます。

- V1 基板では抵抗値の選定ミスで有線通信ができなさそうな状態です。
- V2 基板では多分できる気がする状態に修正しましたが、まだ動作未確認でできるかどうかわからない状態です。

2026/04 現在、実装予定はありませんが引き続き実装に興味はあるので実装される可能性は残っています。

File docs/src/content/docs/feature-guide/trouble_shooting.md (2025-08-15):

---
title: トラブルシューティング
description: 想定トラブルとその対応方法を解説します
sidebar:
  order: 100
---

想定されるトラブルやこれまでに問い合わせがあったトラブルへの対応策をまとめたページです。

## PC とのペアリングができなくなった

- PC 側でペアリング設定が残っている場合は再ペアリングできません。PC 側の bluetooth 設定から DYA Dash が削除されているか確認してください。
- DYA Dash 側で接続先１〜４のどれかに対象の PC とのペアリング設定が残っている場合はその PC と新規ペアリングができません。DYA Dash 側で接続先情報を削除してください。
  - 例: ある PC を接続先１としてペアリングして使っていたが PC 側でペアリングを解除した
    - DYA Dash 側では接続先１の情報がまだ残っているので、接続先２としてその PC とペアリングしようとしても失敗します。
    - DYA Dash 左手の設定右ボタンで接続先１を選択して、Config layer + 左手の設定右 を押すと接続先１の情報が消えてペアリングできるようになります。

どうしてもよくわからなくなった場合は、下の "キーボードに保存された設定をリセットする" のセクションを試してみてください。

## LED が点灯しなくなった

少し前のバージョンで、Config layer に LED の ON/OFF、輝度調整のコマンドを仕込んでいました。（例えば v1 の [こちらのキーマップ](https://github.com/cormoran/dya-dash-keyboard/blob/main/hardware/dya-dash/build-guide/v1/img/dya_dash_config_keymap.svg)）

使用中に誤って LED を OFF or 輝度を下げるコマンドを実行してしまった可能性があります。

LED ON or 輝度を上げるコマンドを実行するだけで治りますが、説明が面倒なので下の "キーボードに保存された設定をリセットする" のセクションに従って一度設定をリセットしてください。

なお、最新のファームウェアでは誤操作を防ぐために該当のキーマップを消しています。

## キーボードに保存された設定をリセットする

キーボードには、左右の接続先情報や BLE ペアリング先情報、デフォルトレイヤーの設定などさまざまな設定が記録されています。
何らかの不具合で設定が壊れてしまった場合は、リセット用ファームウェアを書き込むことで解決できる場合があります。

リセット用ファームウェアは、[リリースサイト](https://github.com/cormoran/zmk-keyboard-dya-dash/releases) で以下のような名前のファイルとして公開しています。xxxxx は right or left.

`zmk_dya_dash_xxxxxx_reset.uf2`

一度これらのファームウェアを書き込んでキーボードの電源を入れ直すと、キーボードに保存されたすべての設定が起動時にリセットされます。

**その後、通常のファームウェア（組み立て時に書き込んだものの最新バージョン）を書き込んでください。** (これを忘れると電源を入れ直すたびに設定が消えます)

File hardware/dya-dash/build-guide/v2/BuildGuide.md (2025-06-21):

#  DYA Dash v2.0 ビルドガイド

https://cormoran707.booth.pm/items/6913095 で配布中のキットのビルドガイドです。

https://cormoran.github.io/dya-dash-keyboard/build-guide/v2/ に移動しました

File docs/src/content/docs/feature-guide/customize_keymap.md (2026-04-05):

---
title: キーマップのカスタマイズ
description: DYA Dash のキーマップカスタマイズ方法の解説
sidebar:
  order: 2
---

:::note

一部 V2 のみの内容がありますが、V3 向けに更新済みのページです。

:::

DYA Dash のキーマップを変更する方法を解説したページです。
自由度と難易度の違う３つの方法があります。

- **DYA Studio, ZMK Studio**: いちばん簡単にカスタマイズできる方法です。プログラミングなし、Github レポジトリなしでできますが、複雑なカスタマイズはできません。
  - DYA Studio は筆者が公開している web アプリです。トラックボールの設定調整、ロータリーエンコーダーのキーマップ編集や無線での接続対応など ZMK Studio より多くの機能に対応しています。
  - ZMK Studio は ZMK 公式のキーマップカスタマイズツールです。最新機能が使える可能性がありますが、基本的には DYA Studio で同等以上の機能が提供されています。
- **keymap editor**: Github レポジトリを作る必要がありますが、プログラミングなしで ZMK Studio よりも複雑なカスタマイズができます。
- **プログラミング**: プログラミングの知識が必要ですが自由自在にカスタマイズができます。

## DYA Studio を使ったカスタマイズ

ファームウェアを書き換えずに簡単なキーマッピングの変更ができます。

https://studio.dya.cormoran.works/ からアクセスできます。

V2, V3 共に 2026/04/02 に公開したファームウェア以降で DYA Studio 全機能が利用できます。

古いファームウェアではキーマップ編集のみが利用できます。

### USB 接続でアクセスする方法

WebSerial に対応したブラウザで利用できます。モバイルOSでは利用できません。

1. PC とキーボード右手の外側の USB ポートを接続
1. https://studio.dya.cormoran.works/ にアクセスして USB マークの接続ボタンを選択
1. DYA Dash (V3) を選択して接続
1. 左手左下+左手 shift で &studio unlock を実行

※2026/04/06 現在一部の機能は左右を有線接続した状態では正常に動作しません。左右は無線接続にした状態でご利用ください。必要な実装していないだけなので今後対応予定です。

### 無線接続でアクセスする方法

Web Bluetooth に対応したブラウザで利用できます。iOS の場合は Bluefy というブラウザアプリから接続できます。Android は未検証です。

1. キーボードの USB ケーブルを外すか、無線接続優先モードに変更
2. Fn+Caps (Fn:右下の一つ上, Caps: 左下)で &studio unlock を実行
3. これを先にやらないと次のステップでデバイスが見つかりません
4. https://studio.dya.cormoran.works/ にアクセスして BLE マークの接続ボタンを選択
5. DYA Dash (V3) を選択して接続
   - iOS の場合は現在周りにあるすべての BLE デバイスが表示されます。たくさんの無線機器に囲まれて暮らしている方はがんばって DYA Dash を探してください。（今後できれば改善予定）

### DYA Studio の詳細な使い方

別途 note の記事を準備しています。それまでは雰囲気で使ってください。

### 参考: ZMK Studio を使ったカスタマイズ

ファームウェアを書き換えずに簡単なキーマッピングの変更ができます。

以下の２種類の方法があります。

- ブラウザ上で動く公式サイト https://zmk.studio/ (USB 接続時のみ対応)
- PC アプリ https://zmk.studio/download (無線接続時も対応)

ブラウザ上で動くサイトの使い方を解説します。

1. 右手キーボードの XIAO の USB ポートを PC と接続
2. 右手の LED が 3 つ以上緑に点灯することを確認。(USB 優先モード)
   - 光らない場合は BLE 優先モードになっているので、左手の設定ボタン左を押してください。
   - BLE 接続がされている場合、対応する LED だけは青く光ります
3. https://zmk.studio/ を開く
4. サイトで USB を選択して出てくるポップアップで DYA Dash KB を選択
5. キーボードの左手左下キー+ 左 shift で studio unlock コマンドを実行
   - 初期ファームウェアでは常に unlock 状態でしたが、セキュリティ上の懸念があるらしいのでロック状態に変更しました
   - 2025/07/26 (ファームウェア v2.3): 両側トラックボールでは左下右隣のキーが存在しないため、左手左下キー+左 shift に変更しました

あとはいい感じにがんばって編集して保存してください。

## keymap editor を使ったカスタマイズ

ファームウェアのソースコードを自動で書き換えてくれるノーコードツール https://nickcoutsos.github.io/keymap-editor/ を使ったカスタマイズ方法です。
ZMK Studio ではできないマクロなどの高度なカスタマイズができます。

### 設定レポジトリを Github に準備する

1. https://github.com/ のアカウントを作ります。
2. https://github.com/cormoran/zmk-keyboard-dya-dash をテンプレートとして設定レポジトリを作ります。

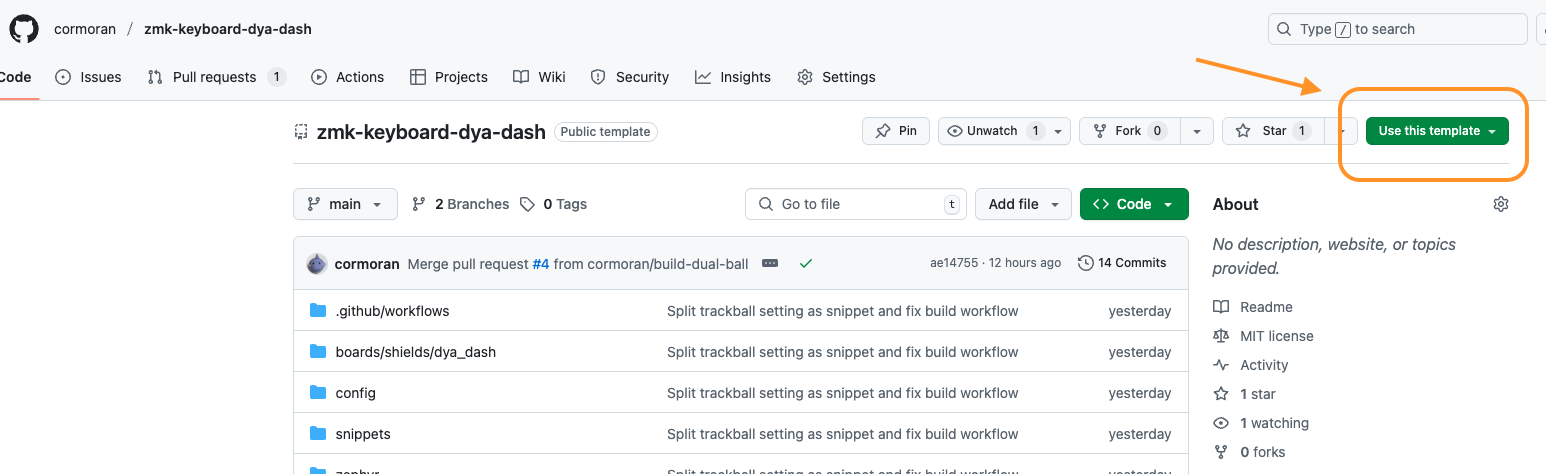
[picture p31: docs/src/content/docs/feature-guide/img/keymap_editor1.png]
   

3. 自動的にファームウェアのビルドが始まることを確認します。
   - 作成されたレポジトリの "Actions" タブをクリックすると "Initial commit" という workflow が動いていると思います。
   - ビルドが終わるとその workflow の Summary ページの Artifacts に zip 圧縮されたファームウェア一式をダウンロードできるリンクが出現します。

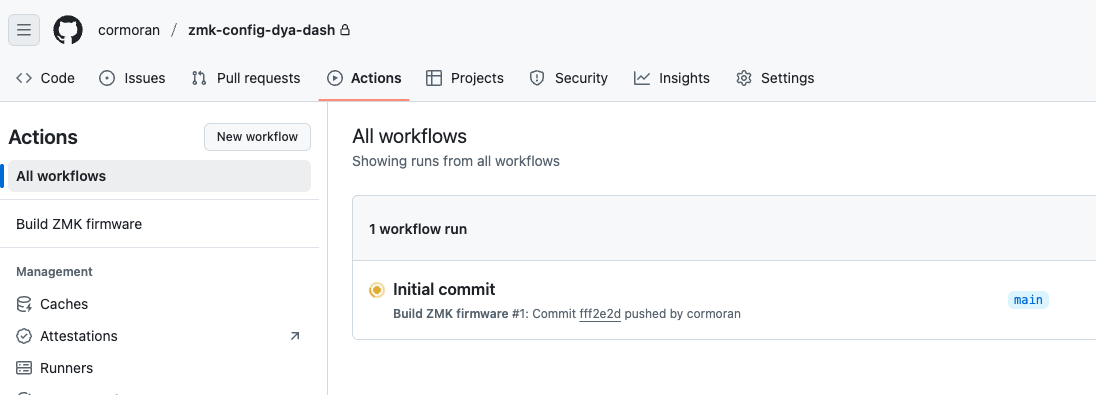
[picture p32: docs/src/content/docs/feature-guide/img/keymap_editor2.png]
   
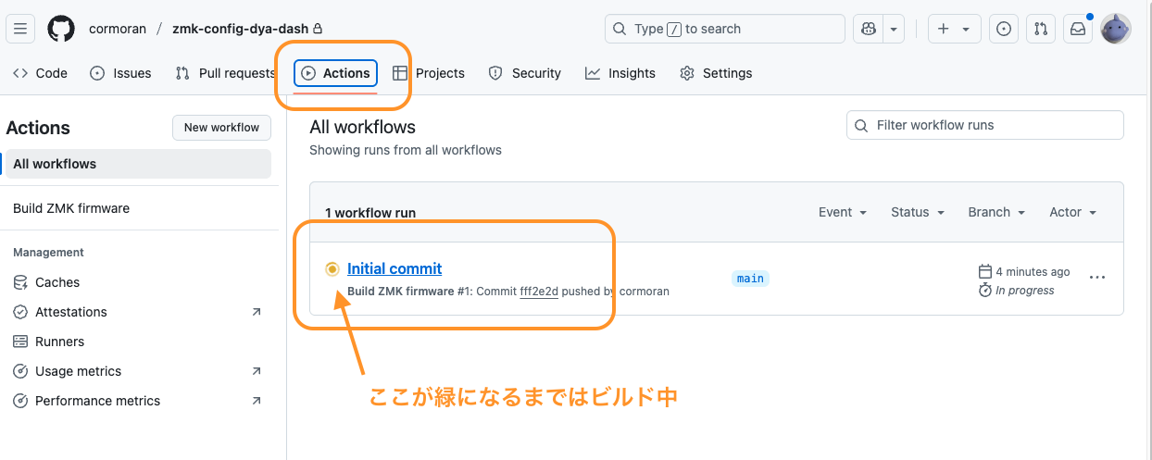
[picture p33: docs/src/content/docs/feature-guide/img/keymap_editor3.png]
   
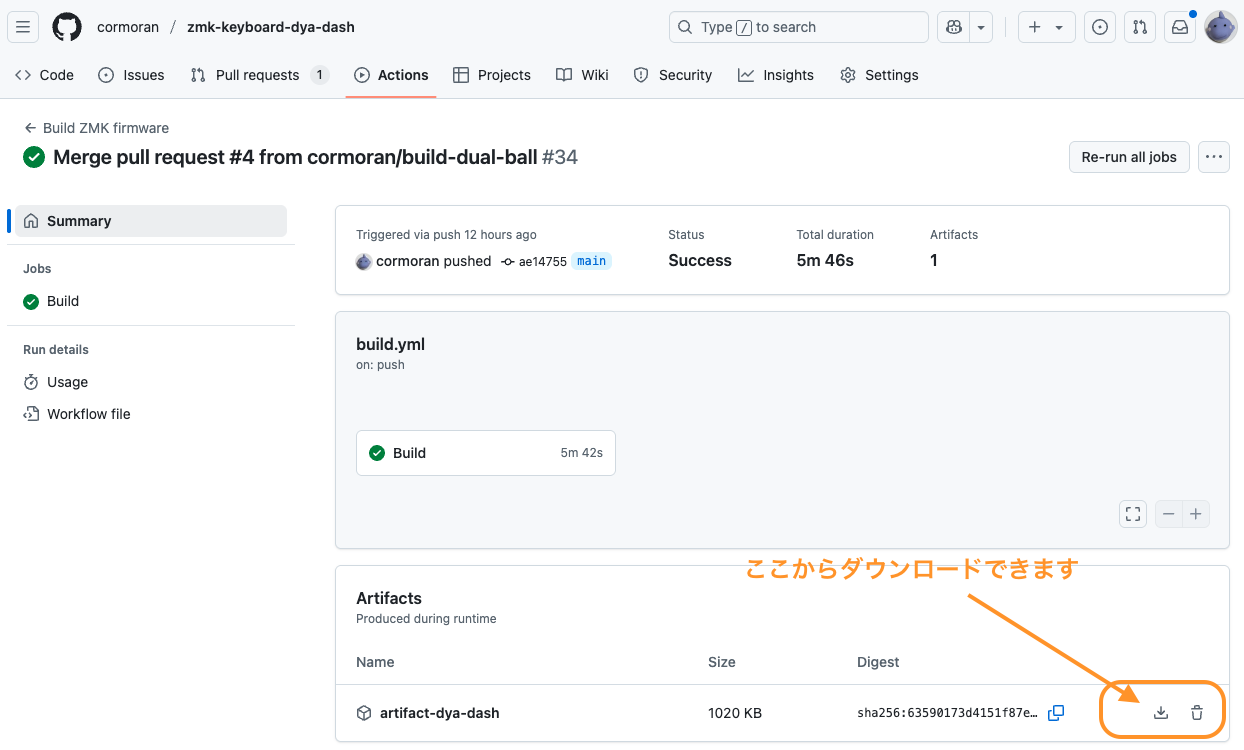
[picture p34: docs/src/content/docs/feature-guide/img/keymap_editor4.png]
   

### keymap editor で設定を編集

1.  https://nickcoutsos.github.io/keymap-editor/ を開いて、github アカウントと連携します。

    | GitHub を選択                 | Login with GitHub             |
    | ----------------------------- | ----------------------------- |
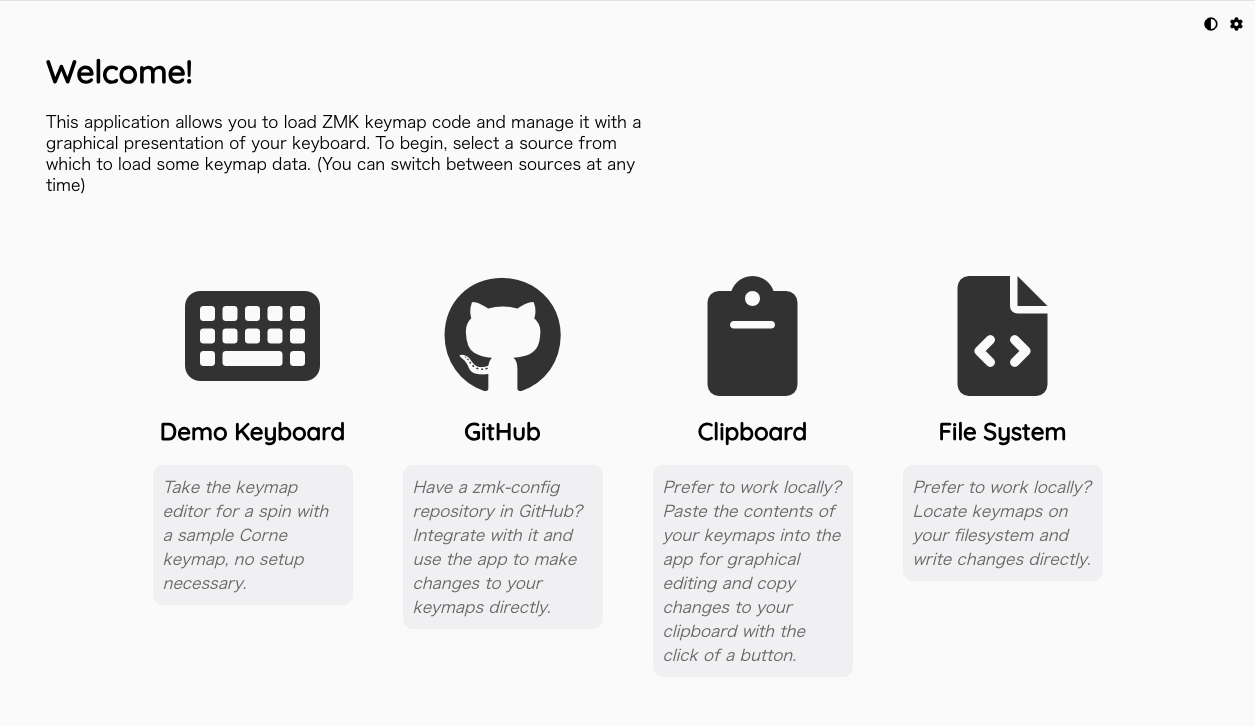
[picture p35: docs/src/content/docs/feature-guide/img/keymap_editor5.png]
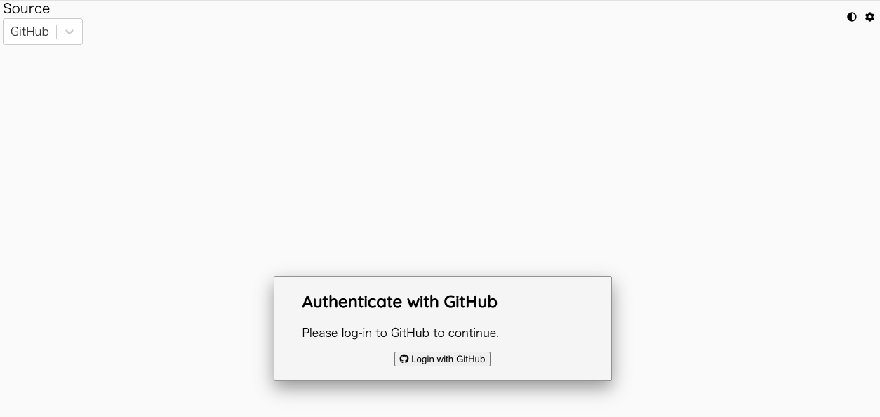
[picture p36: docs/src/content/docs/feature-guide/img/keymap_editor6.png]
    |  |  |

    | Add Repository                | All repository か、上で作成したレポジトリを個別に選ぶ |
    | ----------------------------- | ----------------------------------------------------- |
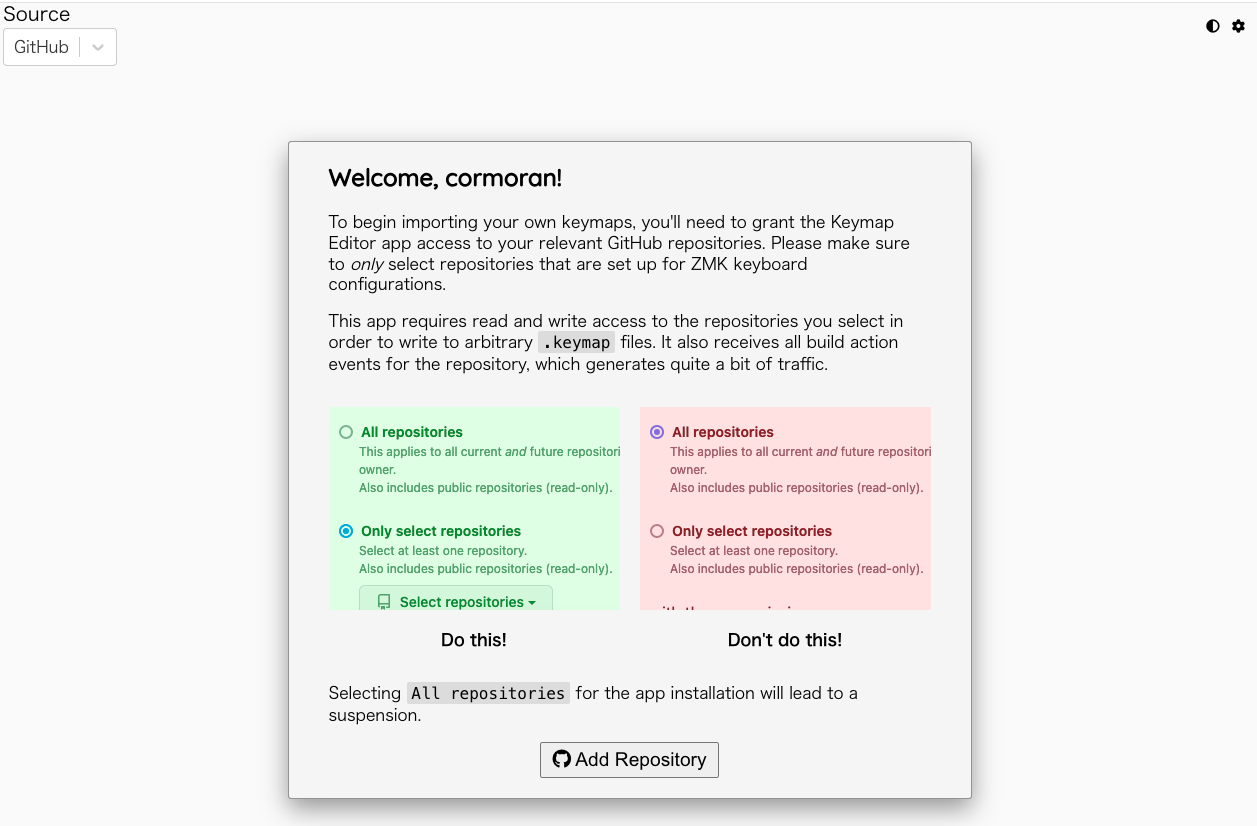
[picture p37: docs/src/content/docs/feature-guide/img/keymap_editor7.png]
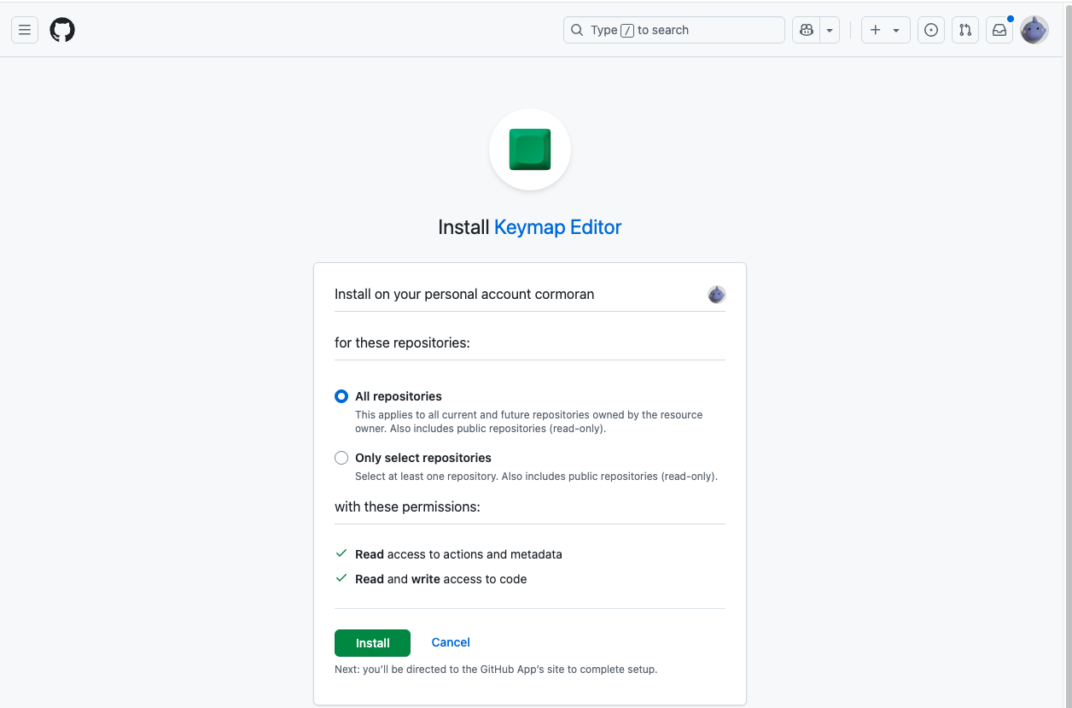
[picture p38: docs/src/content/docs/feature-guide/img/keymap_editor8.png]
    |  |                          |

2.  keymap editor で 2 で作ったレポジトリを選択して各種設置をカスタマイズして Save します
    - カスタマイズの方法などはネットで調べてください。https://sensai-gadget.com/keymap-editor-usage/ などは情報が多そうです。

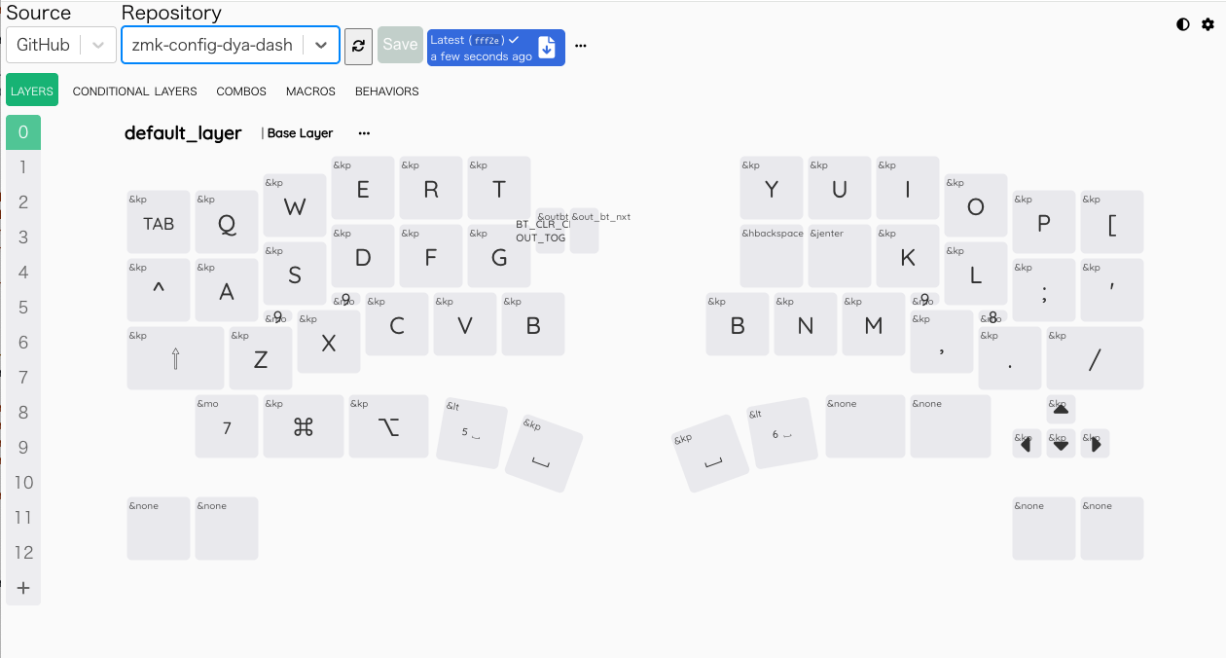
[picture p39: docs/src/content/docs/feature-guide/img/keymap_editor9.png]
    

3.  github のレポジトリに戻ると新しい変更が増えていてファームウェアのビルドが始まっています
4.  ビルドが完了したら Actions の Summary からファームウェアの zip をダウンロードして、キーボードにファームウェアを書き込みます。

### 右側の設定ボタンのカスタマイズ (V2)

右手の設定ボタンは Combo 機能でカスタマイズします。
下の写真のような矢印キーの組み合わせで Combo を登録すると動きます。
レイヤーごとに別の機能を設定するのが少し面倒ですがご了承ください。

なお、矢印キーを同時押しした時もこの Combo が動いてしまいます。矢印キー同時押しをしたい場合は、設定ボタンが使えなくなりますが Combo を消すことで対応できます。

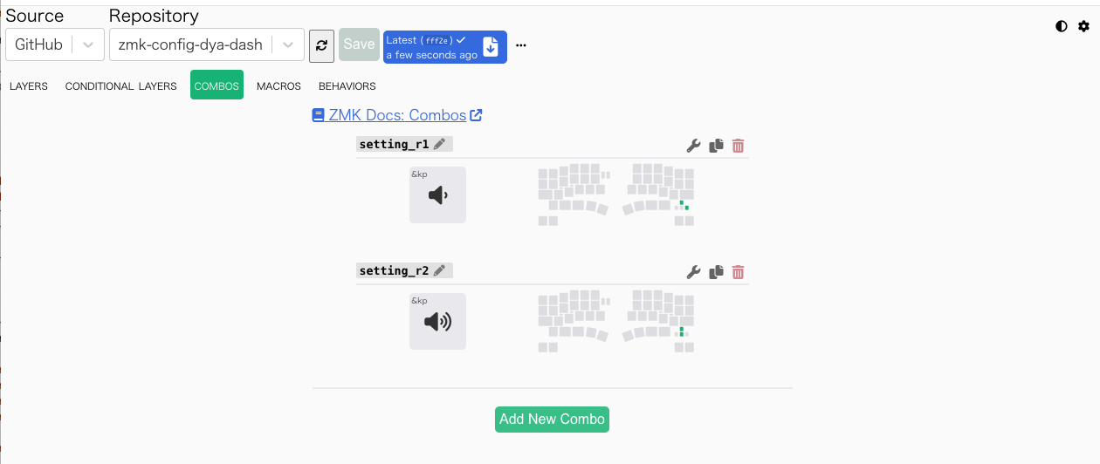
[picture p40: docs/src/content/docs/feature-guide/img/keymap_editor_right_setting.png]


### 矢印キーなしモデルの右側右下キーのカスタマイズ (V2)

左矢印（←）部分のキーマッピングを変更してもらうと矢印キーなしモデルの右側右下のキーをカスタマイズできます。
少し紛らわしいですがご容赦ください。

## プログラミングによるカスタマイズ

keymap editor を使ったカスタマイズの "設定レポジトリを Github に準備する" に従ってレポジトリ作ります。
あとはレポジトリの readme などを見ながらがんばってください。

main ブランチに push するとビルドが始まるほか、ビルドツールをインストールすればローカルでビルドもできるようになっています。

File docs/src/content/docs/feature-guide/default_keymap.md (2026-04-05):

---
title: デフォルトキーマップ
description: DYA Dash のデフォルトキーマップの解説
sidebar:
  order: 1
---

:::note

V2 向けに書かれた記事です。ドキュメントの修正がコードの更新に追いついていない場合があります。

最新のソースコードに基づくキーマップは [zmk-config のレポジトリ](https://github.com/cormoran/zmk-keyboard-dya-dash) の Readme に画像が上がっています。V3 のキーマップもここに上がっています。

- 2025/08/14 firmware v2.4 でキーマップを大幅に更新しました。
- 2026/04/02 DYA Studio に対応する際に幾つかのキーマップを追加/変更しました。以下のドキュメントには未反映です。

:::

デフォルトでは下の写真のようなキー配列になっています。

- 左手親指内側のキーを押した状態で Left SPACE layer が有効になり、数字キーや数字キーのシフト状態のキーが入力できます。
- 左手の２つの設定ボタン（T,G の右側のボタン）には、左が USB/BLE の優先切り替え、右が BLE 接続先の切り替えを割り当てています。
  - USB/BLE 切り替えでは 右手を PC と USB 接続している時に、BLE 接続を優先するか USB 接続を優先するかが切り替わります。
  - 詳しくはこちらの動画を見てください。https://youtu.be/y6X2OnoMX-M
- 右側の設定ボタン（**画像には表示されていない**）には、volume down, up が割り当てられています。
  - これらのボタンは、回路では矢印キー２つの同時押しとして実現されています
  - ZMK では combo という機能で同時押しを検出して別の動作を割り当てています。
- タッチセンサーには Trackball scroll/Pointer が割り当てられています。
  - トラックボールを触るか、外側（L, S 下）センサーに触っている間トラックボール用のレイヤー（右クリック、左クリック...ができるレイヤー）に自動で切り替わります。
  - 内側（K, D 下） のセンサーに触れている間トラックボールがスクロールモードになります。
  - トラックボール・スクロールレイヤーについては下のセクションで説明しています。



## Config layer

左手の左下のキーを押している間 config layer に入ります。

ここには普段あまり使わない設定関連のキーを割り当てます。

- 左手左上、右手右上に `&boot_loader` が割り当てられています。
  - USB 接続状態でこのキーを押すことで XIAO をファームウェア書き込みモードにすることができます。
  - なお、キーボード裏側のリセットボタンをダブルクリックすることでもファームウェア書き込みモードに移行できます。
- 左側の設定ボタン左に `&dfnxt` が割り当てられており、このボタンで現在の接続先のデフォルトレイヤーを切り替えられます。
  - **元は左側右ボタンに設定されていましたが、BLE clear を割り当てるために移動させました**
  - こちらの動画を見ると少しわかるかもしれません https://youtu.be/PggxfXZUtnA
  - やりたいことはこちらの記事 https://zenn.dev/shakupan/articles/261ce435251607 で紹介されていることと同じです。
  - DYA Dash では専用の ZMK ライブラリ https://github.com/cormoran/zmk-feature-default-layer を使って実現しています。
- 左側の設定ボタン右は、現在選択されている BLE 接続先とのペアリングを削除する機能が割り当てられています。
  - ペアリング削除時は PC 側でもペアリングを削除してください。削除しないと再ペアリングが失敗します。
- 左手 Shift には、ZMK Studio を使うための unlock が割り当てられています。
  - ZMK Studio 使用時にはこのキーでキーマップ変更を一時的に許可する必要があります。
- 左手内側の T, G, B には LED アニメーションが設定されています。
  - T: バッテリー残量表示
  - G: BLE 接続先表示
  - B: アクティブレイヤー表示



### Trackball pointer/scroll layer

- トラックボールを動かすと、自動的に Trackball Automouse layer が有効になります。
- トラックボールを止めると一定時間後にデフォルトレイヤーに戻ります。
- Trackball pointer layer が有効になっている間、右側のキーがマウスの右クリックや左クリックとして使えるようになります。
  - **おすすめは人差し指を M キーにおいて左クリック、中指を K キーにおいて右クリックです。**
- K, D の下のタッチセンサーに触れると、触れている間 Trackball Scroll layer が有効になります
  - この状態でトラックボールを触ると、上下左右スクロールができます。
- L, S の下のタッチセンサーに触れると、触れている間 Trackball Manual layer が有効になり、トラックボール用のキーマップが維持されます。
  - ダブルクリックをする時や、長時間トラックボールのみを使う時に非常に便利です。
  - 専用の manual layer を導入することで automouse layer の自動無効化を回避しています。



### OS ごとのデフォルトレイヤー

接続先ごとにデフォルトレイヤーを保存する機能のために、メジャーな OS ごとにデフォルト配列を設定するためのレイヤーを用意しています。
Windows, Mac で Win/Cmd を切り替える、Mac では親指内側の Cmd で英かなモード変更をできるようにするなど、作者が必要な最低限度のデフォルト設定がされています。
作者は普段 Mac を使っているので Windows での設定は現状適当です。

自動で OS 検出はできませんが、接続先ごとにデフォルトレイヤーを切り替える機能 (Config layer 参照)で一度手動で設定すればそれ以降は自動でデフォルトレイヤーがいい感じに切り替わることを期待しています。

詳しくは [接続先ごとにキーマップを変える](/dya-dash-keyboard/feature-guide/default_layer_per_connection) を見てください



### Reserved レイヤー

ZMK Studio でカスタマイズできるように３つ追加のレイヤーを定義してあります。

## ZMK Studio

キーボードの右側を USB で PC と接続し、**USB 接続モードにした**状態で https://zmk.studio/ を開くと、プログラミングなしでキー配列をカスタマイズできます。

※左手の設定ボタン（左）を押すと BLE 接続モード、USB 接続モードが交互に切り替わります。USB 接続モードの場合、右手の LED が緑に光ります。

~~ZMK に詳しい人向け：DYA Dash ではデフォルトで ZMK Studio によるキーマップ変更ができるように設定しており、unlock コマンドの実行は不要です）~~ 変更しました

詳しくは、[キーマップのカスタマイズ](/dya-dash-keyboard/feature-guide/customize_keymap)を見てください。

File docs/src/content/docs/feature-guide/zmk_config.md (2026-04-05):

---
title: ZMK Config を変更する
description: ZMK Config の変更方法
sidebar:
  order: 6
---

キーマップなどの設定ファイル https://github.com/cormoran/zmk-keyboard-dya-dash の解説ページです。
トラックボールを触った時に自動的にマウスレイヤーに切り替わる設定や、トラックボールの感度などの調整方法を解説しています。

## 編集すべきファイル

- [config/dya_dash.keymap](https://github.com/cormoran/zmk-keyboard-dya-dash/blob/main/config/dya_dash.keymap)(v2), [config/dya_dash_v3.keymap](https://github.com/cormoran/zmk-keyboard-dya-dash/blob/main/config/dya_dash_v3.keymap) (v3)に設定を調整したいと思われる項目が集まっています。基本的にはこのファイルを編集すれば十分です
- [boards/shields/dya_dash](https://github.com/cormoran/zmk-keyboard-dya-dash/tree/main/boards/shields/dya_dash)(v2), [boards/shields/dya_dash_v3](https://github.com/cormoran/zmk-keyboard-dya-dash/tree/main/boards/shields/dya_dash_v3)(v3) ディレクトリ以下にさまざまな設定ファイル/定義ファイルが入っています。より高度な設定をする場合はこちらの編集が必要かもしれません

## 変更例

:::note

V2 の古いファームウェア向けの内容です。DYA Studio 対応したバージョンからは設定が大きく変わっており、以下で解説している内容はすべて DYA Studio でファームウェア書き換えなしに設定が変更できます。

:::

### トラックボール関連の設定を変える

[config/dya_dash.keymap](https://github.com/cormoran/zmk-keyboard-dya-dash/blob/main/config/dya_dash.keymap) の以下の部分がトラックボール関連の設定です。
ZMK の [Input Processor](https://zmk.dev/docs/keymaps/input-processors) という機能の設定が書かれています。

```
# 右側トラックボールの設定
&trackball_listener {
    input-processors = <
    // TRACKBALL_L layer is activated when trackball is used.
    // After 500ms of trackball inactivity, the layer is deactivated.
    &zip_temp_layer TRACKBALL_L 500
    // Example: Adjust sensitivity of trackball multiply by 1 and divide by 60.
    // &zip_xy_scaler 1 60
    >;
};

&trackball_scroller {
    layers = <SCROLL_L>;
    // Example: adjust sensitivity of scroll multiply by 1 and divide by 60.
    // input-processors = <&zip_xy_scaler 1 60 &zip_xy_to_scroll_mapper>;
};
# 左側トラックボールの設定
&trackball_listener_l {input-processors = <&zip_temp_layer TRACKBALL_L 500>; };

&trackball_scroller_l {layers = <SCROLL_L>; };

&zip_temp_layer {excluded-positions = <19 20 21 22 32 33 41 52 53 54 55 56 57 58 59>; };

&trackball_r {cpi = <600>; };
&trackball_l {cpi = <600>; };
```

#### オートマウスレイヤーを無効にする

`&zip_temp_layer TRACKBALL_L 500` の部分を削除することでトラックボールを触った時に自動的にマウスレイヤーに切り替わる設定を無効にできます。

```diff
&trackball_listener {
   input-processors = <
--    // TRACKBALL_L layer is activated when trackball is used.
--    // After 500ms of trackball inactivity, the layer is deactivated.
--    &zip_temp_layer TRACKBALL_L 500
   // Example: Adjust sensitivity of trackball multiply by 1 and divide by 60.
   // &zip_xy_scaler 1 60
   >;
```

代わりに、 `keymap` でマウスレイヤーに移動するキーマップ (`&mo TRACKBALL_L` など)を追加する必要があるかもしれません。
デフォルトのキーマップでは外側のタッチセンサーに触れている間マウスレイヤーが有効になるようになっています。

#### トラックボールの感度を調整する

センサーの CPI を設定するか、ZMK の input processor で変化の倍率を調整する２つの方法があります

センサーの CPI は以下のような修正で変更できます
CPI を高くすることで少しの操作でより移動量を増やすことができます。
CPI は 200 刻みで 200~3200 の間で設定できます。

```diff
-- &trackball_r {cpi = <600>; };
++ &trackball_r {cpi = <800>; };
&trackball_l {cpi = <600>; };
```

ZMK の input processor を使う場合は以下のように `zip_xy_scaler` を設定します。
以下の例ではセンサーの入力を xy に 1/60 にして y に 2/60 にしています。

```diff
&trackball_listener {
    input-processors = <
    // TRACKBALL_L layer is activated when trackball is used.
    // After 500ms of trackball inactivity, the layer is deactivated.
    &zip_temp_layer TRACKBALL_L 500
++    // Example: Adjust sensitivity of trackball multiply by 1 and divide by 60.
++    &zip_xy_scaler 1 60
++    // Change sensitivity for y direction * 2 / 60 (=/30)
++    &zip_y_scaler 2 60
    >;
};
```

#### トラックボールのスクロールの感度を調整する

スクロール時の動作は `trackball_scroller` という部分で input processor の設定を上書きできるようになっています。
例えば以下の設定ではスクロール時には入力を 1/60 にします。

```diff
&trackball_scroller {
    layers = <SCROLL_L>;
++    // Example: adjust sensitivity of scroll multiply by 1 and divide by 60.
++  input-processors = <
++    &zip_xy_scaler 1 60
++    &zip_xy_to_scroll_mapper
++  >;
};
```

### スリープに入るまでの時間を調整する

[dya_dash_left.conf](https://github.com/cormoran/zmk-keyboard-dya-dash/blob/main/boards/shields/dya_dash/dya_dash_left.conf), [dya_dash_right.conf](https://github.com/cormoran/zmk-keyboard-dya-dash/blob/main/boards/shields/dya_dash/dya_dash_right.conf) に書かれている以下の項目を変更するとスリープに入るまでの時間を調整できます。

```diff
# Deep sleep (BLE オフにして電力消費を最小限にする)
-- # 5min
-- CONFIG_ZMK_IDLE_SLEEP_TIMEOUT=300000
++ # 30min
++ CONFIG_ZMK_IDLE_SLEEP_TIMEOUT=1800000
# idle (BLE は接続を継続するが、LED など電力を多く消費するデバイスをオフにする)
-- #3s
-- CONFIG_ZMK_IDLE_TIMEOUT=30000
++ #1min
++ CONFIG_ZMK_IDLE_TIMEOUT=60000
```

左側（Peripheral) は消費電力が少ないので deep sleep に入るまでの時間を延ばしておくと使いやすいと思います。

## その他

質問が来たら随時追加していきますのでお気軽に X の DM や Booth のメッセージからお問い合わせください。

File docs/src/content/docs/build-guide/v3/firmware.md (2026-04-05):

---
title: ファームウェアの書き込み
description: XIAO nRF52840 Plus へのファームウェアインストール
sidebar:
  order: 2
---

はんだ付けを始める前に、2 つの XIAO nRF52840 plus にファームウェアを書き込みます。

## 必要なもの

- XIAO nRF52840 Plus × 2 個
- USB ケーブル（Type-C、データ通信対応）
- PC

## ファームウェアファイルのダウンロード

1. ファームウェアレポジトリの[GitHub リリースページ](https://github.com/cormoran/zmk-keyboard-dya-dash/releases)を開きます
2. v3 向けの最新版のファイルをダウンロードします `zmk_dya_dash_v3_(right|left)_(module).uf2` というフォーマットになっています。
   - 名前に left を含むものは右手側に書き込むファームです
   - 名前に right を含むものは右手側に書き込むファームです
   - 例えば右トラックボール、左スイッチモジュールの場合以下のように選択します
     - 右手は `zmk_dya_dash_v3_right_trackball.uf2`
     - 左手は `zmk_dya_dash_v3_left_switch.uf2`

## 書き込み手順

### 1 つ目の XIAO（左手用）

1. **XIAO を PC に接続**
   - 1 つ目の XIAO nRF52840 Plus を USB ケーブルで PC と接続します

2. **書き込みモードに入る**
   - XIAO のリセットボタンを素早く 2 回押します
   - 詳しくはインターネットを調べ手ください。例えば[このサイト](https://qiita.com/KentaHarada/items/3e1612116ec45462a837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)など

3. **ファームウェアをコピー**
   - PC に「XIAO-SENSE」という名前の USB メモリのようなデバイスが表示されます
   - 上で指定の左用のファームウェア(名前に left を含むもの)をドラッグ&ドロップでコピーします

4. **書き込み完了**
   - 「XIAO-SENSE」が自動で切断されます

### 2 つ目の XIAO（右手用）

同僚の手順で右手用のファイルを書き込みます。

どちらの XIAO に左右どちらのファームウェアを書き込んだか覚えておいてください

### 左右がわからなくなった場合

もし左右がわからなくなった場合でも、XIAO 取り付けた後再度正しいファームウェアを書き込むことができます。

左右を逆に取り付けても回路は壊れませんが、キーが逆転したりトラックボールが動かなかったりします。

## 組み立て完成後に再度ファームウェアを書き込む

### 1. リセットボタンを押す方法

DYA ロゴマークの部分を押し込むと XIAO のリセットスイッチが押されるようになっています。XIAO を PC に接続した状態で DYA ロゴマークを２回素早く押し込むことで上で説明した手順と同じように書き込みができます。

### 2. ブートローダーのキーマップを実行する方法

`&bootloader` キーマップが割り当てられたキーを押すことでリセットボタンを２回押した時と同様に書き込みモードに移行するようになっています。

デフォルトでは Config layer の 右上, 左上 のキーに割り当てられています。書き込みたい方の XIAO を PC と有線接続した状態で、左に書き込みたい場合は左(or 右)下+左上、右に書き込みたい場合は右(or 左)下+右上 キーを押すと書き込みモードに移行します。

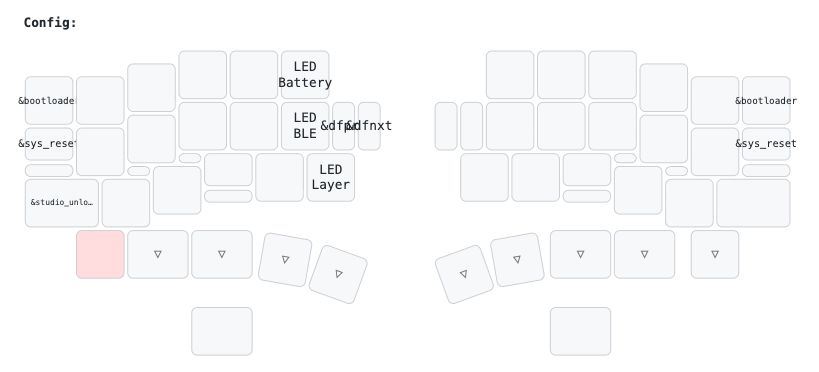
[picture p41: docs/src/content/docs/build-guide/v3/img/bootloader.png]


## トラブルシューティング

### XIAO が認識されない場合

- USB ケーブルがデータ通信対応かご確認ください
- 異なる USB ポートを試してみてください
- XIAO のリセットボタンをもっと素早く 2 回押してください

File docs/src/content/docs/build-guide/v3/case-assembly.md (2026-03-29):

---
title: ケースの組み立て
description: ケースの組み立てから最終的な完成まで
sidebar:
  order: 4
---

## 注意点

- **FFC ケーブルの取り扱い**：表と裏に注意し、丁寧に扱ってください。
  - 強く曲げると断線する可能性があります。
- **ネジの締め方**：3D プリントケースのネジ穴は潰れやすいため、強く締めすぎないでください
- 力を入れない：3D プリント品は積層方向に力が加わると剥がれやすいです

## 1. 基板の切り離し

回路基板をマウスバイト（小さく並べた開けられた穴）に沿って切り離します。少し注意して折り曲げると綺麗に折れると思います。
折りづらい場合はペンチなどを添えて折ってください。回路の配線を傷つけないように注意してください。

以下の４つに分かれます。

- 左手基板
- 右手基板
- 左手親指スイッチモジュール
- 右手親指スイッチモジュール

切り離し多部分にバリが出ている場合は整えます。

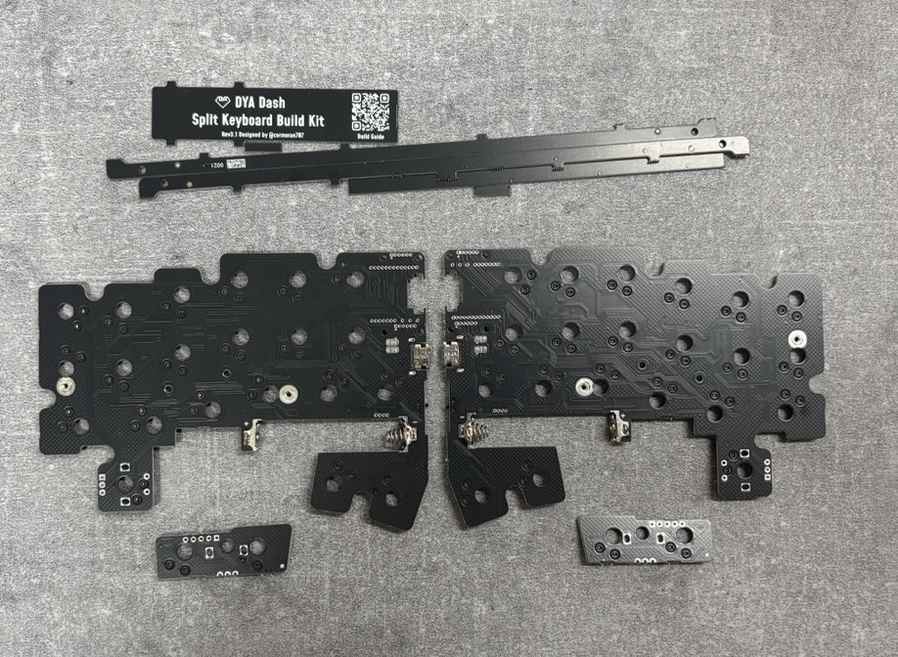
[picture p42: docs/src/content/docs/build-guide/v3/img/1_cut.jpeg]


## 2. XIAO の取り付け

1. 図のようにコンスルーの片側２ピンと XIAO の電源周りに対応する３ピンを取り外します。
   - コンスルーには向きがあります。
   - ピンが引っかかっている窓の部分が画像に合うように取り外してください
   - **なお、この２ピンは人差し指部分をロータリーエンコーダーにする際には必要になります。**
   - 将来、人差し指部分をロータリーエンコーダーにしたい場合は取り外した２ピンを保存しておくか、取り外さずにそのまま基板に取り付けてください。
     - そのまま基板に取り付けた場合はキースイッチと干渉するため、キースイッチの樹脂部分を一部切り取る必要があります。

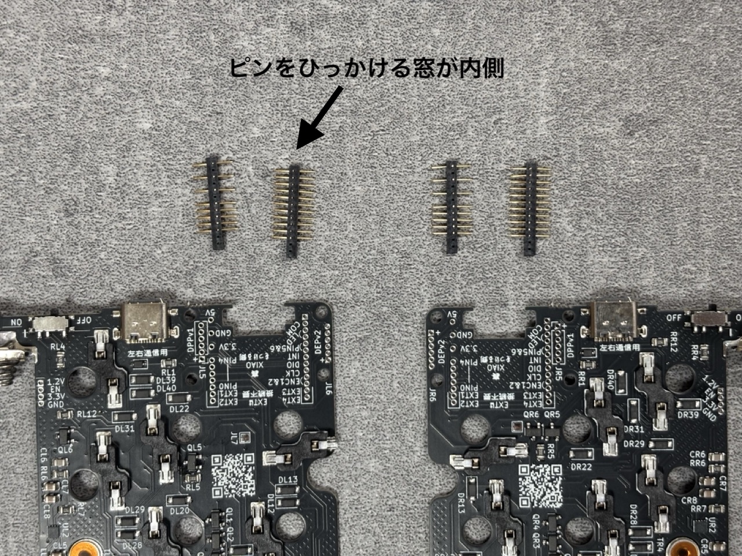
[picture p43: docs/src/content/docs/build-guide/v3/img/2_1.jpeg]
   

1. 左右の基板に画像のようにコンスルーを取り付けます。向きがあるので画像に合うように注意してください。
   - 硬い場合はコンスルーを揉む（ピン部分を指で何度か潰す）と入りやすくなります。
   - 無理に押し込むとコンスルーの樹脂部分が破壊されることがあるので注意してください。
   - ピンを上から平らな硬いもので抑えながら挿すとうまくいきやすいです。

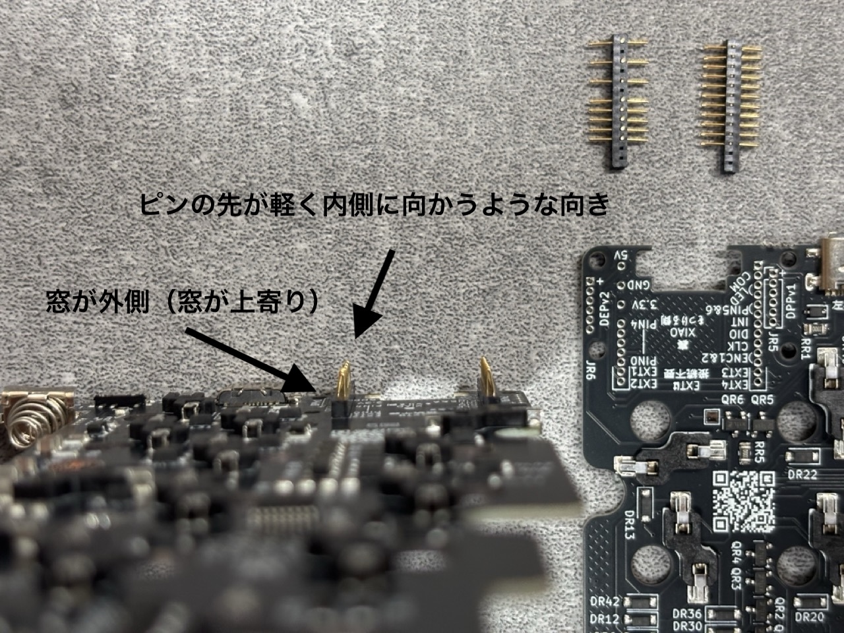
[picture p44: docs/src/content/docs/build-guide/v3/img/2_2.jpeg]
   

1. 画像のように XIAO をはめ込みます

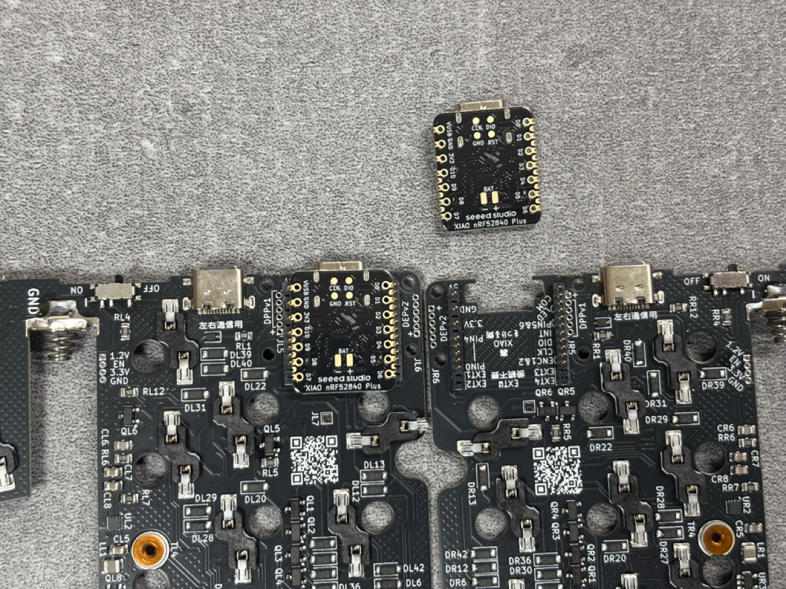
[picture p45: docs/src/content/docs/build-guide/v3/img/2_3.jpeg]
   

1. XIAO カバーを取り付けて M2 5mm の低頭ネジで固定します。
   - XIAO カバーには左右があります。逆に取り付けると基板のダイオードと干渉するので、干渉しないことを確認した上でねじ止めしてください。
   - カバーは コンスルーと XIAO との接続を安定させるために少しきつく作ってあります。取り付け時には軽く押し込む必要があります。

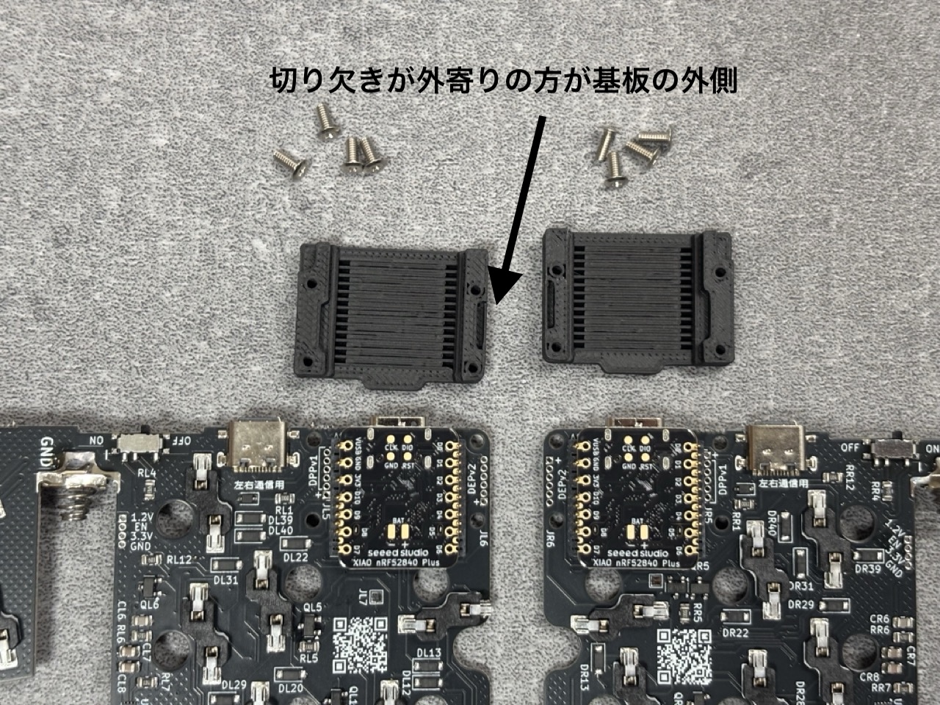
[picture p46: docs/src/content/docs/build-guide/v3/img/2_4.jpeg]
   

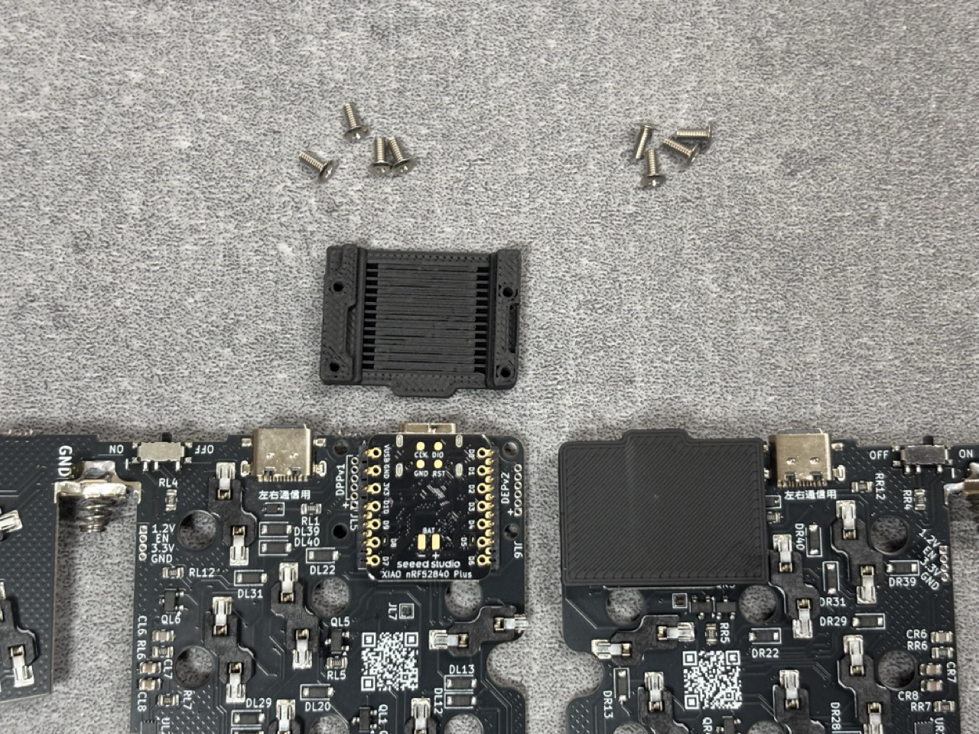
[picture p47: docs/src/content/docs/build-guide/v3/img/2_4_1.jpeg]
   

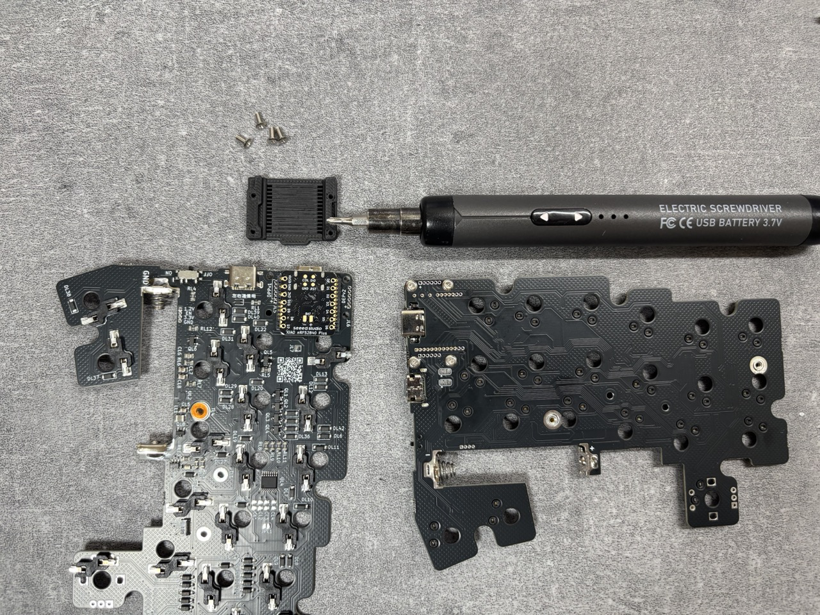
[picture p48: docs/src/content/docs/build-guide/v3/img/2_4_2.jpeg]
   

## 2.1 （Option）小指ロータリーエンコーダーの半田付け

小指部分のキーをロータリーエンコーダーにする場合はロータリーエンコーダーを半田付けしてください。

左右両方でも、どちらか片方だけでも動作します。

一度取り付けると取り外しはハンダの除去が必要になるので、最初はキースイッチで組み立ててみることをお勧めします。

なお、完成後に半田付けする場合は一度ケースから基板を取り外して半田付けすることを強くお勧めします。
ケースはPLA製のため熱で簡単に溶けたり縮んだりします。

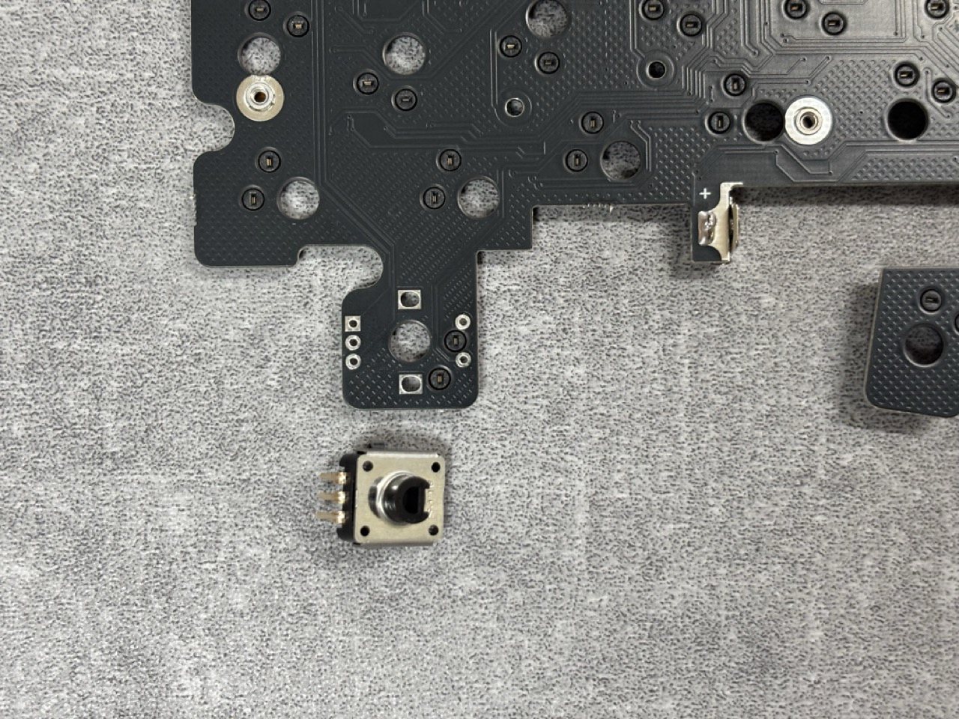
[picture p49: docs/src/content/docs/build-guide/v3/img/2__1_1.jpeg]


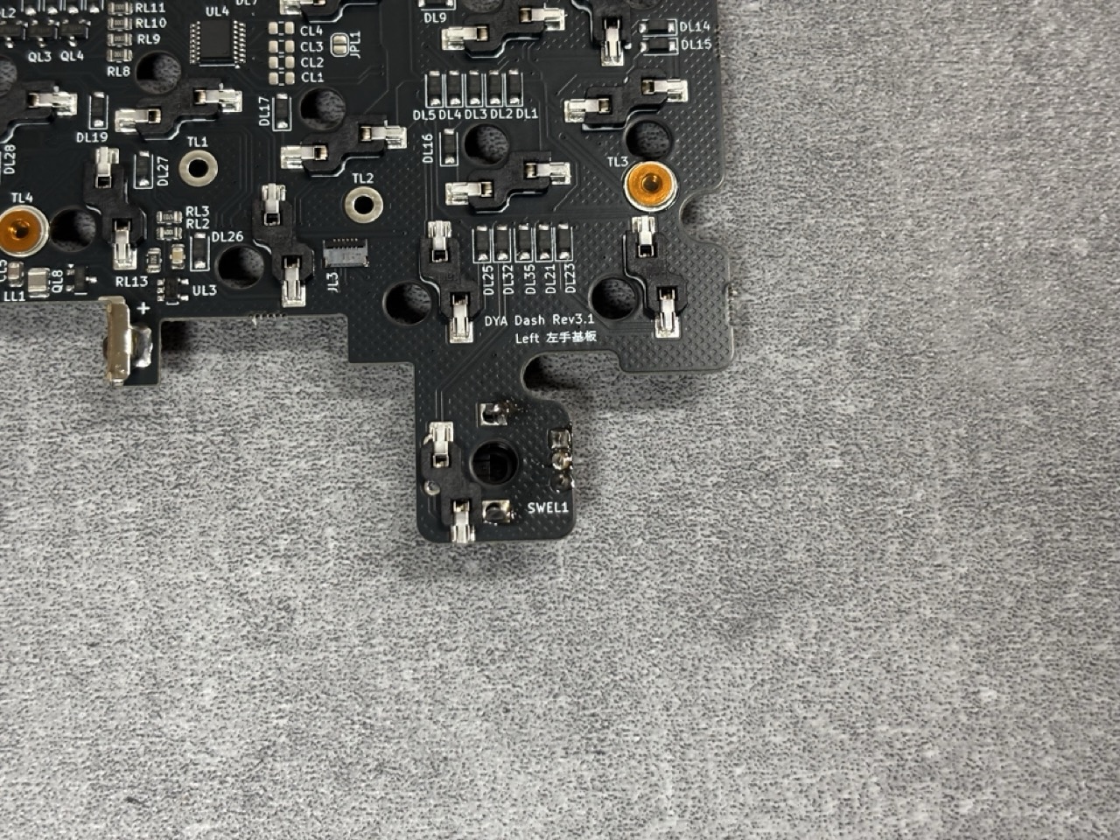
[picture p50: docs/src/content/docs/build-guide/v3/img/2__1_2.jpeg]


## 3. 人差し指モジュール（設定ボタン）の取り付け

1. 残り１つのコンスルーをちょうど真ん中で 6pin 6pin に分けます。ニッパーで切り取ってください。
   - コンスルーは１３品あるので、ちょうど真ん中のピンの部分を切ることで１ピン減って 6pin 6pin になります

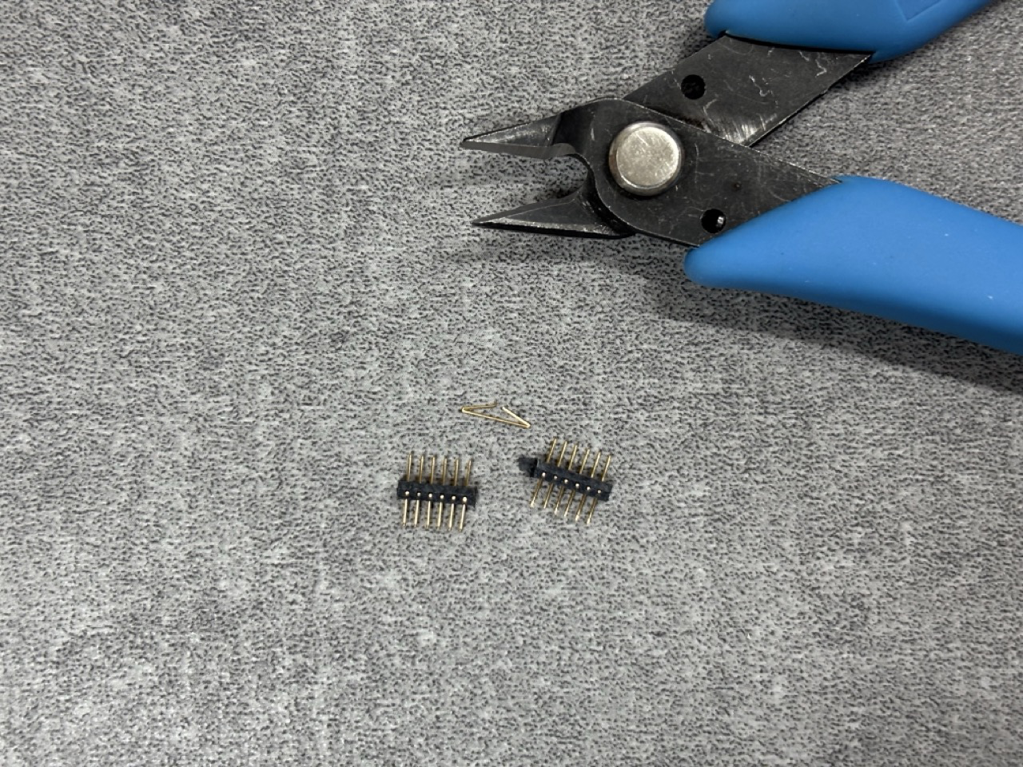
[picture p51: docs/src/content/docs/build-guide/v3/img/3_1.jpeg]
   

1. コンスルーを基板に取り付けます。画像のように向きに注意してください

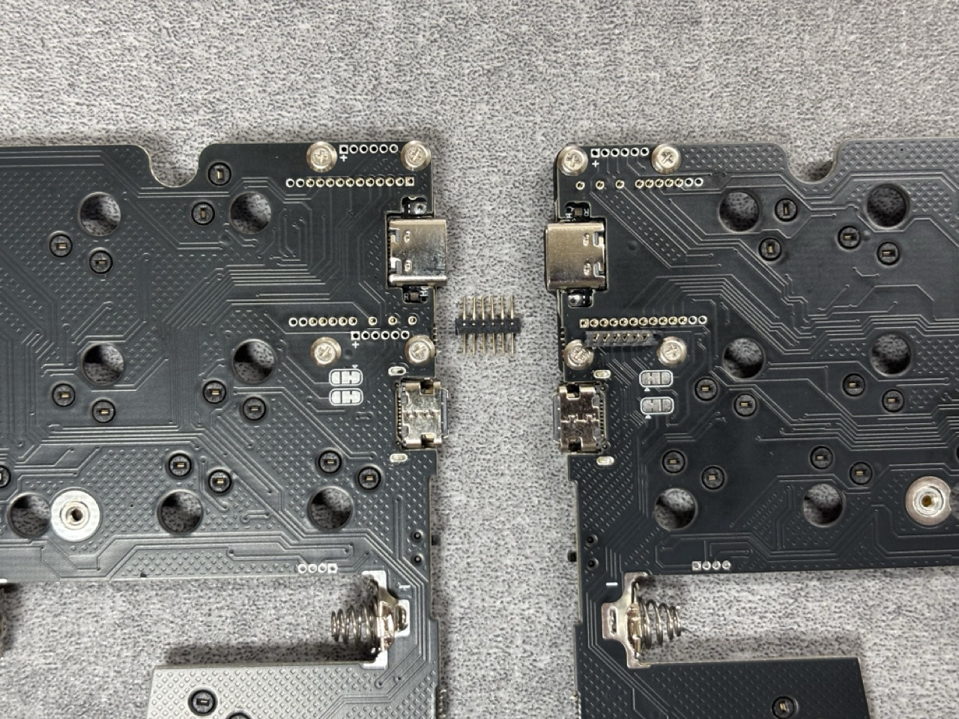
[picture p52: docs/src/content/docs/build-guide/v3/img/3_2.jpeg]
   

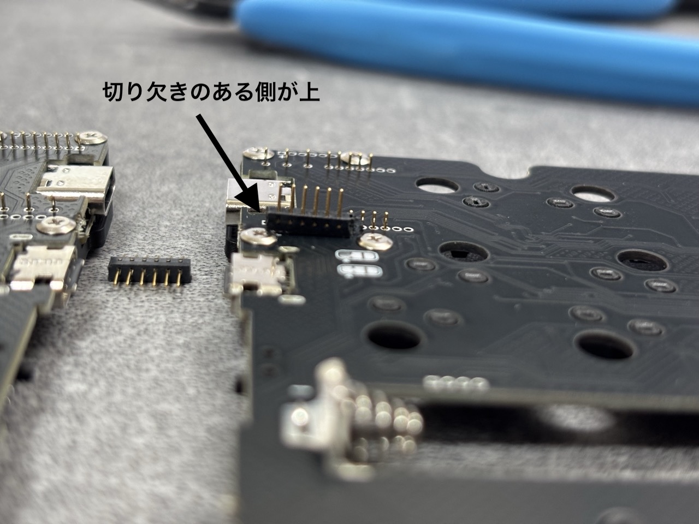
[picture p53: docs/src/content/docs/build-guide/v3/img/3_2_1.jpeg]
   

1. XIAO のリセットボタンを押すための平らなパーツを切り欠きに合うように取り付けます
   - パーツを押し込んだ時にリセットボタンが押されることを確認してください。

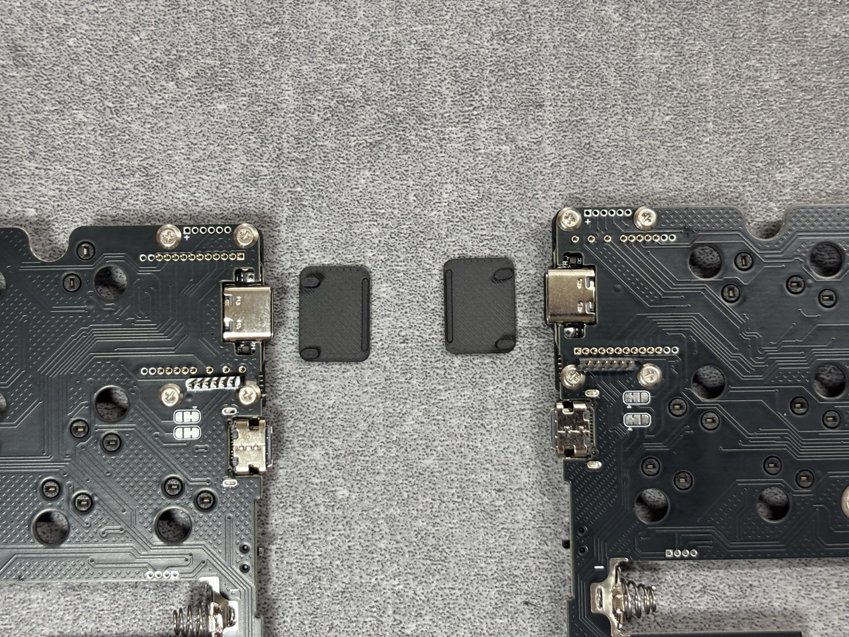
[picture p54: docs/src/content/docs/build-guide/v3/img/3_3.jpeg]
   

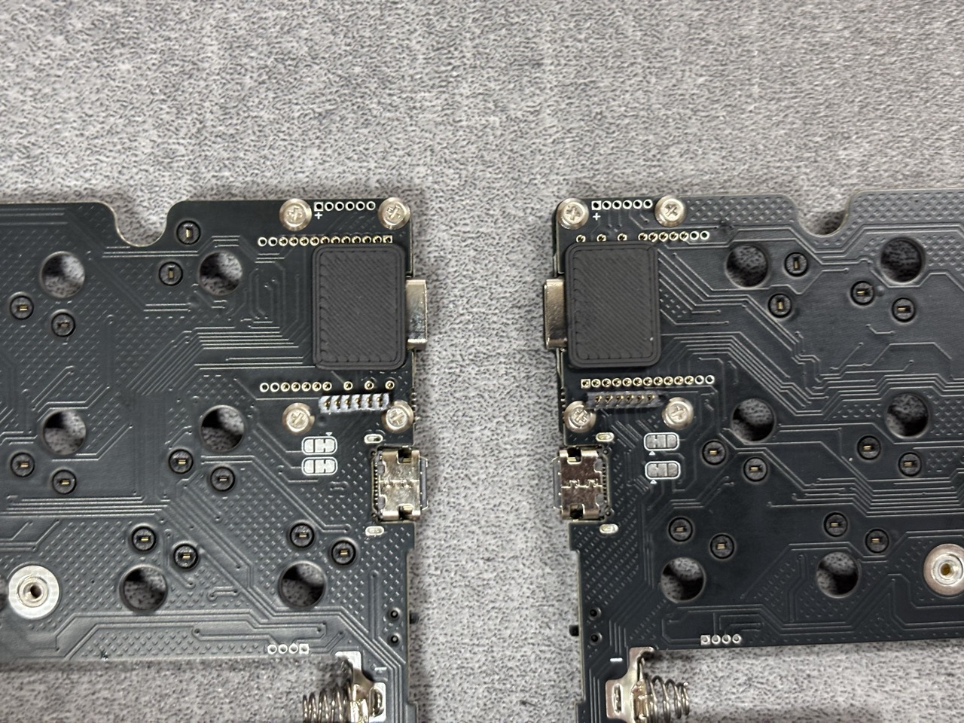
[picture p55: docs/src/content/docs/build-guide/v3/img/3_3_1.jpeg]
   

1. 人差し指モジュールを支えるパーツを取り付けます
   - このパーツはボタンを支えるほか、モジュールと USB 端子がショートするのを防ぐためにも重要です。

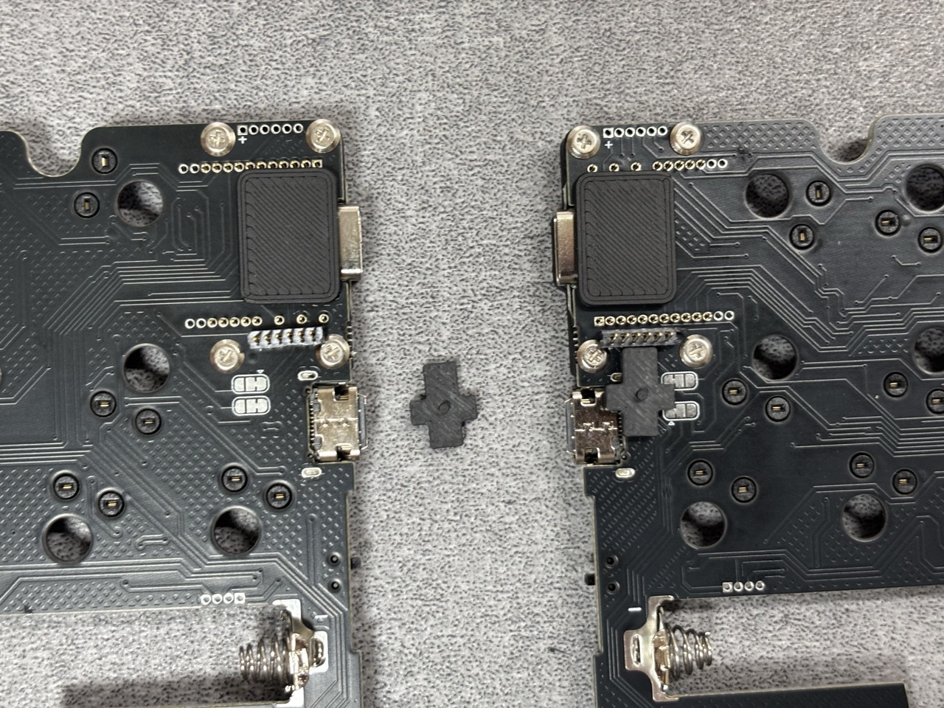
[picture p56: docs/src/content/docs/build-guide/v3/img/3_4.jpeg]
   

1. 人差し指設定ボタンモジュールをコンスルーに取り付けます
   - 裏側でUSB 端子とスイッチの端子が接触していないか確認してください。

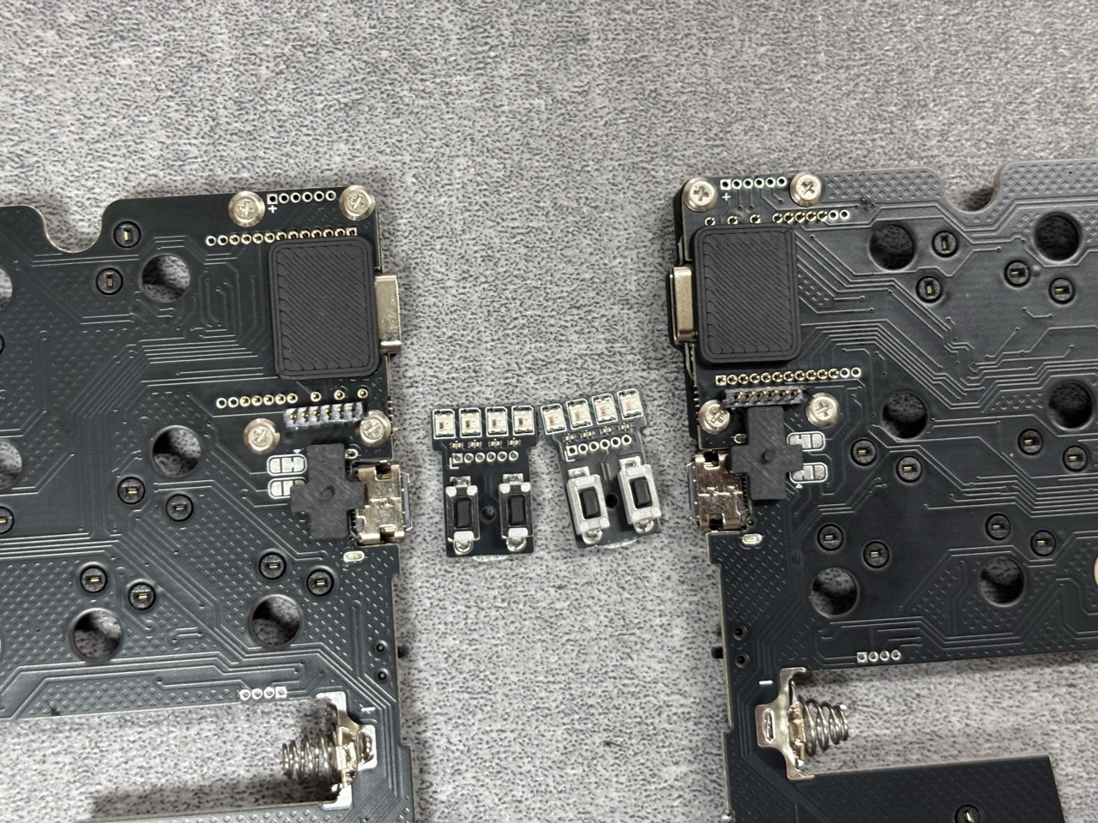
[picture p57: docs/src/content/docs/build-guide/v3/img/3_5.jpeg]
   

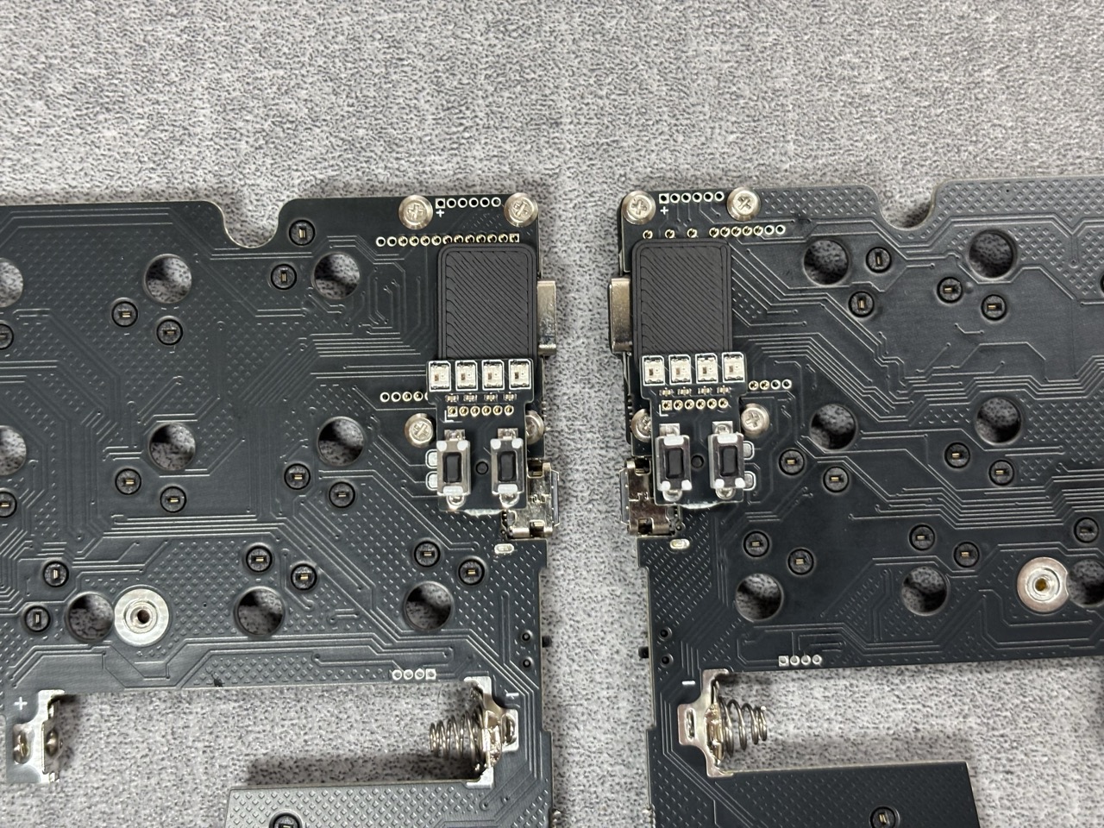
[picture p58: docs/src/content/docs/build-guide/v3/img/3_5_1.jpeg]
   

## 3.1 （オプション、別売りモジュール）人差し指モジュール（エンコーダー）の取り付け

設定ボタンの代わりにエンコーダーを取り付けることもできます。

あとで書きます。結構難しく複雑です。

## 4. トップケースにパーツを取り付け

1. トップケースに電源スイッチカバー、設定ボタンカバー、エンブレムを取り付けます
   - 設定ボタンカバーは左右で少し異なっており、向きがあります。左右の壁が短い方がスイッチ側になるように取り付けます
   - 設定ボタンカバーは薄く壊れやすいので力を加えすぎないように注意して取り付けてください

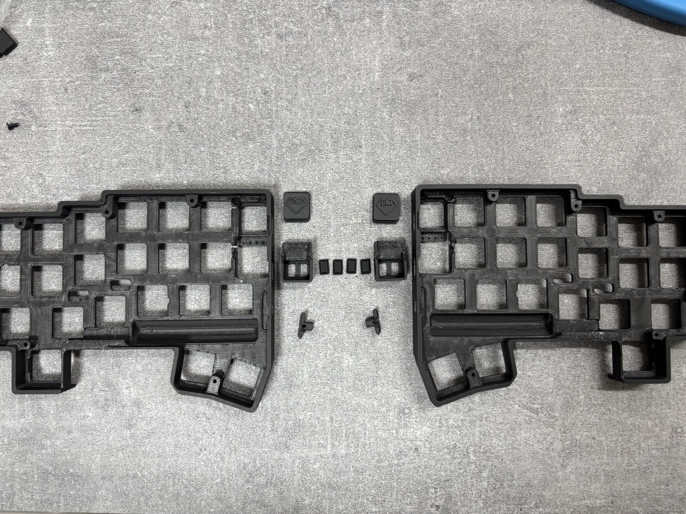
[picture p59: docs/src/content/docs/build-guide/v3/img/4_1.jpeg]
   
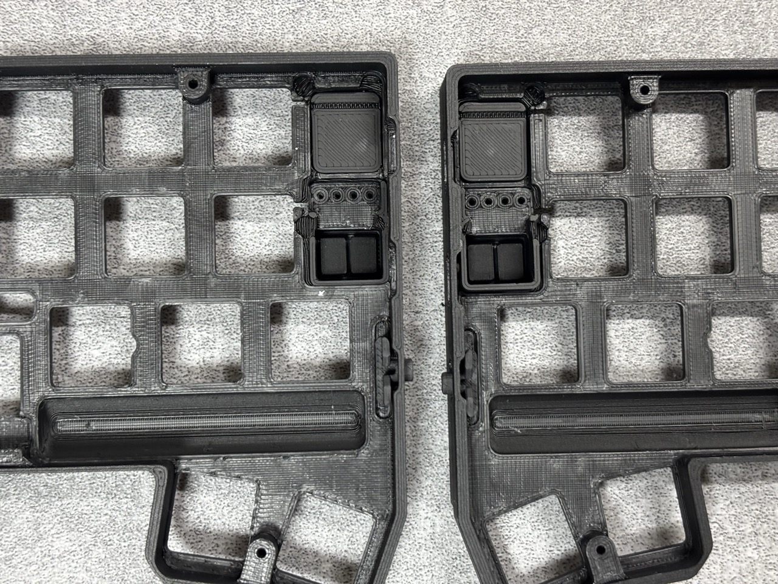
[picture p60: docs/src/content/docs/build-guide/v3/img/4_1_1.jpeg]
   
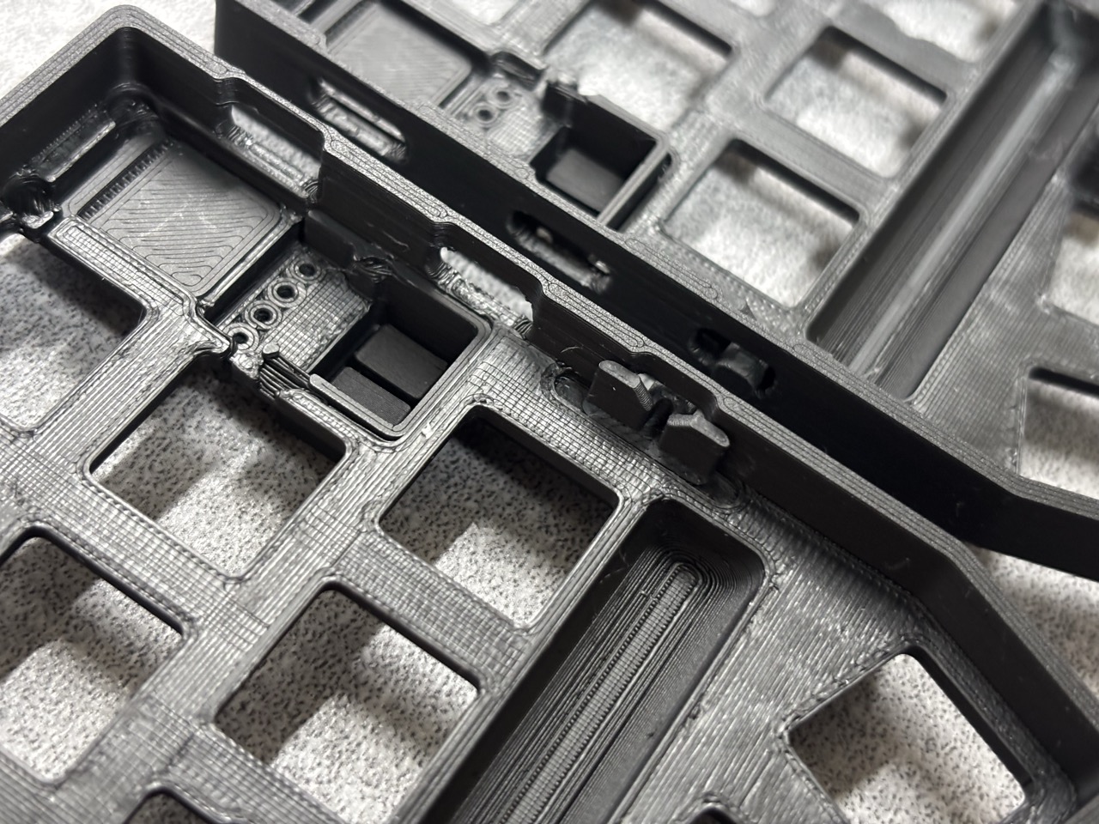
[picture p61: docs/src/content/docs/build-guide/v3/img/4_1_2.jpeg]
   

1. 回路基板をトップケースにはめ込みます。以下の点に気をつけながら注意深くはめ込んでください。はめ込んだらキースイッチを２箇所程度取り付けて基板を仮固定します。
   - XIAO のリセットボタンを押すパーツがずれないように注意
     - 現在の設計では特に左手が難しくなっています。ずれた状態で無理やり押し込むとリセットボタンを押す部分が取れてしまう場合があるので力を加えずにはめ込んでください。もしリセットボタンのスイッチが折れた場合でも、キースイッチにマッピングされているブートキーを使ってファームウェア書き込みができるので開発者以外は、実用上大きな問題はありません。
   - 電源スイッチの突起がスイッチカバーの凹みに合うように注意 **合わないまま押し込むと電源スイッチが壊れます**
   - 設定ボタンモジュールが設定ボタンカバーにうまくはまっているか注意 ずれた状態で押し込むとカバーが壊れます。
   - ある程度位置があったら、設定ボタンカバーを逆側から抑えながらはめ込むと少し安全です

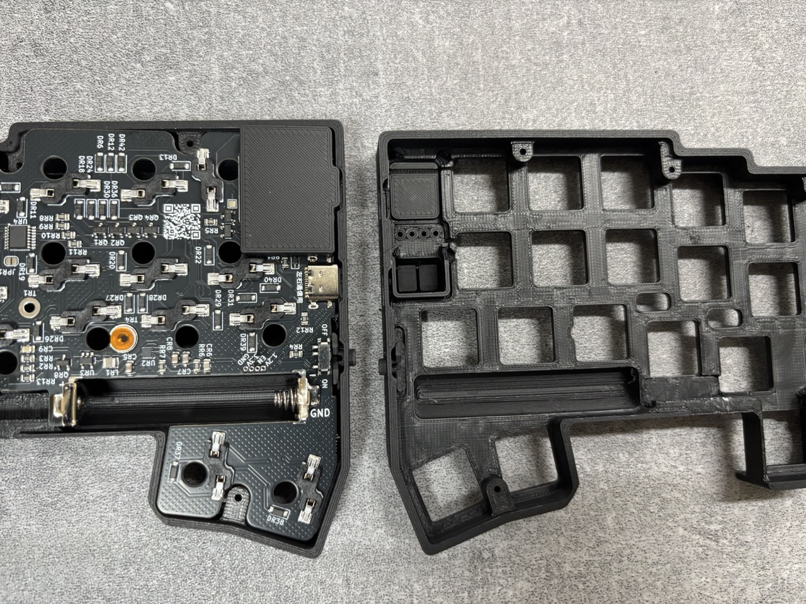
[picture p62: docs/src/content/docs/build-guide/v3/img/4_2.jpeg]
   
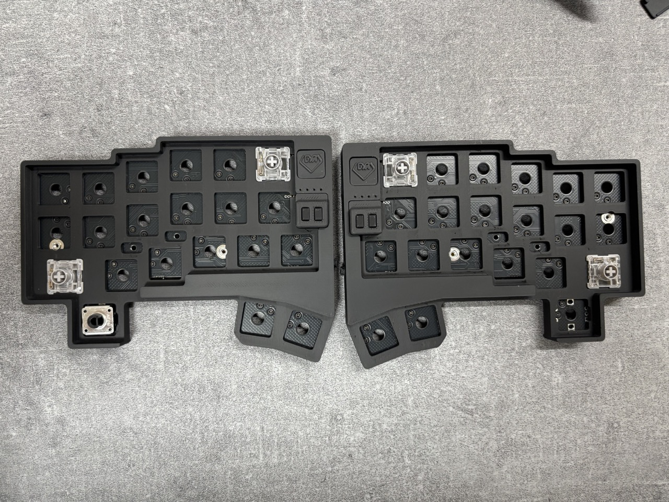
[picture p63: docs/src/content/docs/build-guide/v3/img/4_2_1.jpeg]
   

1. タッチセンサーカバーを M2 の長いねじで基板にねじ止めします。左右それぞれ２つずつ取り付けます
   - 少し硬い場合があるようです。径の合うドライバーを使用して、少しネジを押さえ込みながら取り付ける必要があるかもしれません。

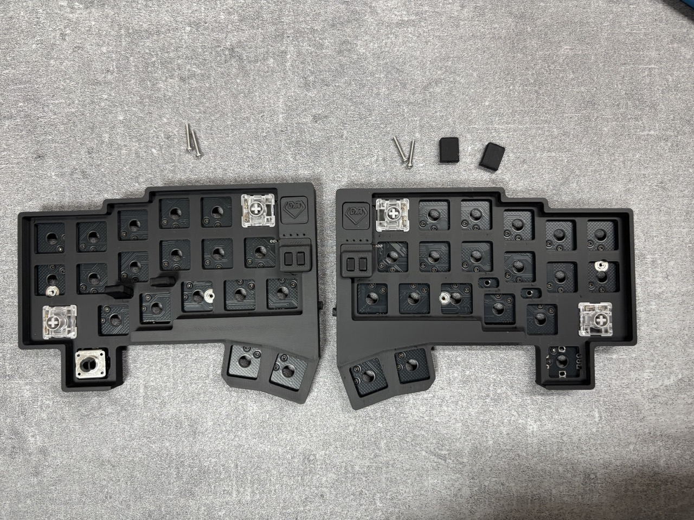
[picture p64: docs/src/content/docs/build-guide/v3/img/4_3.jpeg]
   

## 5. キーキャップ裏タッチセンサーとキースイッチの取り付け

タッチセンサーの取り付けは飛ばして完成後に行うこともできます。

1. タッチセンサー端子に両面テープをつけて、対応するキーキャップの裏側に貼り付けます。
   - **この時タッチセンサー端子のねじ止め部分が基板のネジ穴の向きと合うように貼り付けてください**

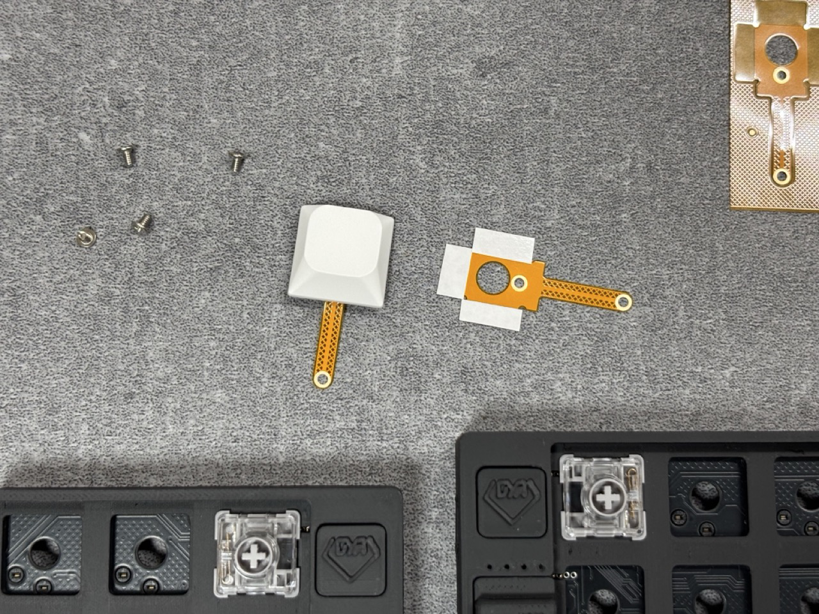
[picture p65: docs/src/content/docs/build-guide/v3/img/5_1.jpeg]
   

1. タッチセンサー端子を M2 3mm のねじで基板にねじ止めします。

   

次にすべてのキースイッチを取り付けてください。位置によってソケットの向きが違うので、向きが合うように確認しながら取り付けます。

タッチセンサーのついた部分もそのまま取り付けます。DYA2 同様タッチセンサー端子が端に挟まれたような状態になります。

なお、**最初のステップでコンスルーの２ピンを取り外さなかった場合**は上部内側の２つのスイッチがコンスルーと干渉します。
その場合はスイッチの樹脂部分をニッパーなどで破壊して干渉しないようにして取り付けてください。

キースイッチを取り付ける際はソケットを基板の裏側から押さえつけながら取り付けてください。無理に押し込むとソケットが基板のパターンごと剥がれてしまうことがあります。

    

次にキーキャップを取り付けます

    

## 6. 親指モジュールの組み立てと取り付け

お好きなモジュールを組み立ててください。
以下では片側の例だけを書いていますが、 FFC ケーブルの取り回しが変わる以外は左右で同じです。

### 6.1 スイッチモジュールの場合



1. スイッチモジュール基板の FFC ケーブル端子に FFC ケーブルを取り付けます
   - 黒い部分を立てた状態で取り付け、横に倒してロックしてください。

   

1. スイッチモジュールケースに基板を押し込みます　
   - 外れづらいように少し引っ掛かるようになっています。
   - 押し込むと入ります

   

1. キースイッチを取り付けます

   

1. FFC ケーブルの反対側をトップケースの穴を通して本体基板の FFC ケーブル端子に取り付けます

   

   

### 6.2 トラックボールモジュールの場合



1. センサー回路についている茶色い保護フィルム２つをはがします



1. レンズを取り付けます



1. レンズの足の部分を切り取ります。ハンダゴテで熱して熱着しても良いです。



1. [v2 のガイド](https://cormoran.github.io/dya-dash-keyboard/build-guide/v2/case-assembly/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) を参考に使用するトラックボールの種類に応じたアジャスターを取り付けてトラックボールホルダーに回路を差し込みます。

   基本的にはv2と同じですが、v3 では FFC ケーブル端子の位置を変えることで FFC ケーブル樹脂部分を無理に曲げる必要がなくなっています。



最後に、FFC ケーブルの反対側をトップケースの穴を通して本体基板の FFC ケーブル端子に取り付けます



### 6.3 （別売りモジュール）ロータリーエンコーダーモジュールの場合

半田付けが必要です。

TODO: あとでがんばって書きます！！

- 回路はリバーシブルで左右兼用です。
- 抵抗はファームウェアを間違えた時に回路が破損するのを防ぐ目的です。
- 330Ω 程度のものを取り付けてください。間違えない自信がある場合はハンダでジャンパ（0Ω）しても良いです。
- 裏側のタクトスイッチは SKRAAWE010 で動作確認済みですが、高さを調整すれば他の表面実装タクトスイッチも使用可能です。
- 6pin 0.5mm pitch FFC コネクタか、付属の 5pin FPC で本体回路と接続してください。
  - 6pin 0.5mm pitch FFC コネクタの半田付けは非常につらいので非推奨です
- 付属の薄いプレートをタクトスイッチの下に差し混んで使用してください

## 7. ボトムプレートの取り付け

1. ボトムプレートにネオジム磁石を接着剤で取り付けます。
   - この時、左右のボトムプレートどうしがくっつくような向きで磁石を取り付けてください。
   - 片方を取り付けた後プレートを裏側同士合わせた状態でもう片方を取り付けるとうまくいきます。

   

   

1. ボトムプレートをトッププレートに取り付け、 M2 4mm の黒いネジでトッププレート、親指モジュールとねじ止めします。
   - 強くねじを締めすぎないでください。

   

1. 滑り止めゴムを左右それぞれ４箇所に取り付けます
   - 滑り止めゴムは表面のシールも剥がしてください。
   - 最初、ゴムは滑り止め効果が非常に高くなっています。そのままだと左右をくっつけた際に剥がれてしまうので、指などでゴムを少し汚して表面の滑り止め力を弱めるとちょうど良く使用できます。

   

1. スイッチがオフ（上側にスライド）の状態で電池を取り付け、電池カバーをはめ込みます。

   

## 完成！



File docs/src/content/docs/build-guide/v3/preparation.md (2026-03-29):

---
title: 事前準備
description: 必要な部品と工具の確認
sidebar:
  order: 1
---

組み立てを始める前に、必要な部品と工具を確認します。

## キット同梱部品の確認

3D プリント製パーツは非常に小さく種類もたくさんあります。
組み立て前に全てのパーツが入っているか確認お願いします。

パーツが足りなさそうな時はできるだけ早く対応するので購入したプラットフォームのメッセージ機能で連絡ください。

:::caution

・トラックボールケースは２つ付属していますが、トラックボールセンサーは１セットのみ同梱されています。
両側トラックボールにする場合は追加でセンサー基板とICを購入する必要があります。

・エンコーダー関連部品は小指用のノブのみが同梱されています。エンコーダー(EC12E2440301)や親指モジュール用部品、人差し指モジュール用部品は別売りです。

:::



| カテゴリ | 内容 | 画像 |
| --- | --- | --- |
| 基板&ケース | <ul><li>半田付け済み回路基板(厚み 1.2mm, 親指スイッチモジュールx2 つき)</li><li>トップケース左右</li><li>ボトムケース左右</li><ul> |  |
| トラックボールケース | <ul><li>トラックボールケース左右</li><li>セラミックボール x6（3つづつ取り付け済み）</li><li>センサー位置調整版２種類x2</li></ul> |  |
| 3Dプリント部品 | <ul><li>小指エンコーダーノブx2</li><li>リセットスイッチエンブレムx2</li><li>電池カバーx2(磁石取り付け済み)</li><li>XIAO 固定カバーx2</li><li>親指モジュールキースイッチケース左右</li><li>リセットスイッチ用プレート左右</li><li>人差し指モジュール支持パーツx2</li><li>人差し指モジュール設定ボタンケース</li><li>設定ボタンカバーx4</li><li>タッチセンサーカバーx4</li><li>ネオジム磁石x8</li><li>電源スイッチカバーx2</li></ul> |  |
| ねじ | <ul><li>XIAOカバー固定用低頭ネジ M2 5mm x8</li><li>ケース固定用 M2 4mm x16（黒）</li><li>タッチセンサー固定用 M2 12mm x4</li></ul> |  |
| FFC ケーブル | <ul><li>6pin FFC ケーブル x2</li></ul> |  |
| 電子部品 | <ul><li>1.27mm ピッチ 13pin コンスルー(2mm) **x5**</li><li>人差し指モジュール設定ボタン回路x2</li><li>PMW3610回路(PMW3610取付済み)x1</li><li>PMW3610用レンズx1</li></ul> | 以下の画像のコンスルーの数は間違っています！  |
| キャップ裏タッチセンサー | <ul><li>タッチセンサー端子 x4</li><li>M2 3mm ねじ x4</li></ul> |  |
| ゴム足 | <ul><li>薄いゴム足 x8</li></ul> |  |

## 別途購入が必要な部品

キット以外に、以下の部品をご自身で準備していただく必要があります。

1. XIAO nrf52840 **plus** x2
   - 姉妹品の plus ではない XIAO nrf52840は使用できません。
1. Kailh Choc v2 ロープロファイルキースイッチ 46 個
   - Kailh Lofree Low-profile POM 系のピンが２ピンのものが使えます
   - ３ピンのものはピンを切れば使えるかも？持ってないのでわかりません
   - トッププレートの厚みは 1.6mm です
   - サイレント系のスイッチ推奨
1. ロープロファイル向けキーキャップ一式
   - 1U 40 個
   - 1.5U 2 個
   - 1.25U 4 個（親指スイッチモジュールで左右それぞれ２個）
   - [YMDK 116](https://ja.aliexpress.com/item/1005006981216357.html) と [THT low profile](https://talpkeyboard.net/items/66795277401c310b1f80e83f)(1.25U は存在しない)が使えることは確認しています
1. 25mm トラックボール用ボール
   - 色によって感度に違いが出ます。以下の情報は rev2 での検証結果です。トラックボールケースの設計はほぼ同じなので rev3 でも同様と思われます。
   - [エレコムの赤いボール](https://www.amazon.co.jp/%E3%82%A8%E3%83%AC%E3%82%B3%E3%83%A0-%E3%83%88%E3%83%A9%E3%83%83%E3%82%AF%E3%83%9C%E3%83%BC%E3%83%AB%E7%94%A8%E4%BA%A4%E6%8F%9B%E3%83%9C%E3%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)がおすすめです。
   - [ペリックスの深い赤](https://www.amazon.co.jp/Perixx-%E3%83%9A%E3%83%AA%E3%83%83%E3%82%AF%E3%82%B9-PERIPRO-305GRD-%E4%BA%A4%E6%8F%9B%E7%94%A8%E3%83%88%E3%83%A9%E3%83%83%E3%82%AF%E3%83%9C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) や染色された POM 球でも動作確認できていますが、アジャスターを取り替える必要があります。
   - フロストアクリル球（紫）でも動作しました
1. 単４電池 x2
   - ファームウェアのバッテリー残量表示はニッケル水素電池向けに調整されています
   - アルカリ乾電池等も使えるはずですが、残量表示が実際の残量と対応しないと思います。今後ファームウェアアップデートで対応できるようにするつもりです。
1. USB ケーブル
   - データ通信に対応した Type C ケーブル（PC 接続用、ファームウェア書き込み用）
   - データ通信に対応した Type C to C ケーブル（左右接続用、左右を有線で通信する場合のみ）
1. タッチセンサーをキーキャップに固定するための適当な両面テープ
1. 磁石をケースに固定するための適当な接着剤
   - 作者は接着剤無しで使用していますが、組み立て時に磁石がホルダーから外れてしまうと回路がショートする可能性があります。
   - 接着剤でケースに固定してしまう方が安全です。
1. (**小指部分にエンコーダーをつける場合**) EC12 互換のロープロファイルロータリーエンコーダ（例 EC12E2440301)最大2つ
1. (**両側トラックボールにする場合**) サイズの限界を攻めたPMW3610 ブレークアウトボードと PMW3610, レンズ１セット
   - キットに同梱されているのは１セットのみで、両側トラックボールにする場合は追加で購入が必要です。
   - https://cormoran707.booth.pm/items/8031841
1. (**親指部分にロータリーエンコーダーをつける場合**)親指ロータリーエンコーダーモジュール
1. (**人差し指部分にロータリーエンコーダーをつける場合**)人差し指ロータリーエンコーダーモジュール

## 必要な工具

- ニッパー
- ピンセット or 先の細いペンチのようなもの
  - 表面実装のスイッチを取り付けるときに必要です。
- プラスドライバー（0 番と 1 番サイズ）
  - **一部固い場合があるので動精密ドライバーの使用を推奨します**
    - 参考に、作者は[こちらの電動精密ドライバー](https://www.amazon.co.jp/dp/B0F1T7MWZJ)を使用しています
  - 商品には複数種類の M2 ネジが付属しています
  - 少しネジ穴の大きい方（e.g. タッチセンサー用ネジ）には 1 番サイズが適合します
  - ネジ穴の小さい方には 0 番サイズが必要です
  - ケースネジは配布時期によって対応するドライバーのサイズが違う場合があります。 タッチセンサー用ネジ以外は 0 番サイズの場合が多いです

**推奨**

- はんだ、はんだごて
  - 基本的には半田付け不要ですが、ロータリーエンコーダーを取り付ける場合は半田付けが必要です。
    また、スイッチソケットのハンダ不良があった際にはご自分で直していただけると助かります。
  - 温度調整機能付きのハンダゴテがおすすめです
  - [C 型のコテ先](https://lang-ship.com/blog/work/900m/#toc19)をおすすめしておきます
- はんだ吸い取り線
  - 失敗した時のリカバリーに非常に役立ちます。

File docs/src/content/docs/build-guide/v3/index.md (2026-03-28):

---
title: 組み立ての流れ
description: DYA Dash v3の組み立てガイドです
sidebar:
  order: 0
---

このページは [Booth](https://cormoran707.booth.pm/items/8132198) で配布中の DYA Dash v3 (=rev3) 向けの組み立てガイドです。

はんだ付けの必要な v2 (=rev2) 向けのガイドは [こちら](/dya-dash-keyboard/build-guide/v2) をご覧ください。

:::caution
v3 は v2 から内部構造が大きく変わっています。v3 向けのファームウェアは v2 とは互換性がないので注意してください。
また、v3 は XIAO plus のみ対応です。v2 は通常の XIAO のみ対応です。
:::

## 更新履歴

| 日付 | 内容 |
| --- | --- |
| 2026/03/26 | V3 のビルドガイドを公開 |

## 組み立ての流れ

1. **[事前準備](/dya-dash-keyboard/build-guide/v3/preparation)** - 必要な部品と工具の確認
2. **[ファームウェア](/dya-dash-keyboard/build-guide/v3/firmware)** - XIAO へのファームウェア書き込み
3. **[ケース組み立て](/dya-dash-keyboard/build-guide/v3/case-assembly)** - ケースの組み立てと完成

## 完成イメージ

ビルドガイドでは以下の例を解説します。

- 左小指にロータリーエンコーダー（エンコーダー別途購入 & 半田付け必要）
- 左親指スイッチモジュール
- 右親指トラックボールモジュール



## 困ったときは

- 部品が不足している場合は、購入プラットフォームのメッセージ機能でお早めにご連絡ください
  - キーケットで購入した場合も booth のメッセージ機能でご連絡ください
- 組み立てに失敗した場合や、なぜかうまく動かない場合も可能な限りサポートしますのでお気軽にご相談ください。

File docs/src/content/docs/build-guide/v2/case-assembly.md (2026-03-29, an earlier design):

---
title: ケースの組み立て
description: ケースの組み立てから最終的な完成まで
sidebar:
  order: 4
---

基板の組み立てが完了したら、ケースを組み立てて完成させます。

## 注意点

- **FFC ケーブルの取り扱い**：表と裏に注意し、丁寧に扱ってください。
  - 強く曲げると断線する可能性があります。
  - 特に、両端の青い部分を、青い部分が内側になるように（動線部分が伸ばされるような曲げ方）曲げてしまうととても簡単に断線するようです。
  - 予備を同梱していますが、予備も含めて FFC ケーブルが断線してしまったと思われる場合はサポートしますのでご連絡お願いします。
- **ネジの締め方**：3D プリントケースのネジ穴は潰れやすいため、強く締めすぎないでください
- **左右の組み立て順**: トラックボールが付いている側は難易度が高いため、トラックボールの付いていない側から組み立てることをお勧めします。

## 左側（トラックボールなし）の組み立て

### 1. トップケースと基板の組み立て

**用意する部品**

- トップケース
- 電池トップカバー（お届け時はトップケースに取り付け済み）
- エンブレムプレート
- 設定スイッチカバー
- 設定スイッチ × 2
- 電源スイッチカバー（下の写真に写っていません）
- キースイッチ片手分（下の写真に写っていません）
- （おまけとして同梱されている場合）白い PE スイッチパッド（下の写真に写っていません）

必要パーツ

**組み立て手順**

1. トップケースに各種パーツをはめ込む

   1. トップケースを裏返します
   1. 電池トップカバー、エンブレムプレート、設定スイッチカバー、設定スイッチ ×2 を写真のようにはめ込みます
      - 設定スイッチを設定スイッチカバーに取り付ける際、3D プリント時のバリが原因でスムーズにはまらない場合があります
      - スムーズにはまらない場合や、スイッチの上下動作がしづらい場合は、設定スイッチカバーのバリをニッパーで整えてください

1. （おまけとして同梱されている場合 & 敷きたい場合）トップケースに PE スイッチパッドをしく

   - PE スイッチパッドはおまけとして同梱されている場合と同梱されていない場合があります。
   - PE スイッチパッドは矢印キーなしモデルの形状でカットされています。 - トラックボールをつける側では不要な部分を切り取って敷いてください。 - 矢印キーありモデルの右では矢印に当たるところも切り取って敷いてください。
   - スイッチパッドを敷くと打鍵音が大きくなる印象があるので、静音スイッチを使用する場合は敷かない方が良いかもしれません。

1. 基板に電源スイッチカバーをつける

   - 電源スイッチカバーを回路基板の電源スイッチにはめ込みます
   - **電源スイッチカバーの突起部分が基板の裏側寄りになる向きではめてください**
   - 電源スイッチカバーの側面は非常に薄く、組み立て時に裂けて外れてしまうことがあります。が、側面は機能上必要ではなく、外れてしまっても機能/組み立て後の見た目ともに問題なく動作します

1. 基板のをトップケースにはめ込む

   - 真上からはめ込もうとすると電源スイッチカバー部分が干渉するので、電源スイッチカバー部分からトップケースにはめ込みます

1. 設定スイッチの動作確認

   - 基板をトップケースにしっかり押し付けた状態で設定スイッチがスムーズに動作するか確認します
   - スイッチが常に押された状態になったり、押したまま戻らない場合は、設定スイッチを外して設定スイッチカバーのバリを整えてください

1. キースイッチをつける
   - まず四隅をつけて仮止めすると良いです。
   - **ピンがうまく刺さっていない状態で無理に押し込むと、ホットスワップスイッチが基板パターンごと剥がれたり、キースイッチのピンが曲がって修復不可能になります**
   - 基板裏側のホットスワップスイッチを指で押さえながらキースイッチをはめ込む方が安心です
   - 全てのキースイッチを取り付けます(下の写真は面倒になって途中でやめてしまっています。)

パーツ取り付け

以下のスイッチパッドは同梱されている場合とされていない場合があります。
スイッチパッド

電源スイッチカバー取り付け1 電源スイッチカバー取り付け2 基板はめ込み

設定スイッチ動作確認 仮止め スイッチ取り付け

### 2. タッチセンサーの取り付け

**用意する部品**

- M2 12mm ネジ × 2 本（これがタッチセンサーです）
- タッチセンサーカバー × 2

**取り付け手順**

1. 写真のように基板の裏からネジを出して、センサーカバーねじ止めします
2. ネジ自体がタッチセンサーとなるので、ネジは基板と導通するよう最後まで締めてください
   - **注意**：強く締めすぎると基板パターンが破損する可能性があるため、適度な力で締めてください

タッチセンサー1 タッチセンサー2 タッチセンサー3 タッチセンサー4

### 3. ボトムケースの組み立て

**用意する部品**

- ボトムケース
- ネオジム磁石 × 4 個
- M2 ネジ（黒ケース：4mm、その他：5mm）× 4 本
- 滑り止めゴム × 4 個

**取り付け手順**

1. ネオジム磁石をボトムケースの穴にはめる

   - 接着剤で固定することをおすすめします
   - うまく組み立てられれば接着材は不要ですが、組み立て時に磁石が回路基板に張り付いてずれる可能性があるので注意してください。場合によっては回路がショート状態になります。

2. トップケースをはめてネジ止め

   - 裏から４箇所をねじ止めします。
   - 強く締めすぎると穴が簡単に潰れるので適度な力で締めてください。

3. **滑り止めの取り付け**
   - 滑り止めゴムを取り付けます

ボトムケース準備 磁石取り付け はめ込み

ネジ止め1 ネジ止め2 滑り止め

### 4. 電池の取り付け

写真のように電池を電池ボトムカバーにセットして取り付けます。

電池取り付け1 電池取り付け2 電池取り付け3

### 左完成！

お疲れ様でした。

## 右側（トラックボールあり）の組み立て

### 1. トップケースと基板の組み立て

**必要な部品**

矢印キーありモデルでは、左側で使用したものに加えて以下の部品を使います。

- 矢印キーカバー（トップケースに取り付け済み）
- 矢印キー × 4

**組み立て手順**

矢印キーなしモデルの場合は矢印キー関連部分は適宜読み飛ばしてください。

1. **トップカバーに各種パーツを取り付ける**

   - 左側ケースと同様に各パーツをはめ込みます
   - **矢印スイッチの方向**：矢印スイッチには方向があります（1 片のみ突起が欠けている）
   - 上矢印部分は突起が欠けた部分が上側になるよう取り付けます
   - 他の方向は指定はありませんが、パーツの積層方向（模様）が揃うように取り付けると良いでしょう

2. **電源スイッチカバーの取り付け**

   - 左側同様、突起部分が基板の裏側寄りになる向きではめてください

3. **基板をトップケースにはめ込む**

   - 基板を電源スイッチカバー部分からトップケースにはめ込みます
   - 矢印キー部分のゆとりが小さく、うまくはめるのが難しい場合があります
   - 軽く押し込むように入れる必要があるかもしれません
   - うまくはまると基板とトップケースがピッタリくっつく状態になります
   - どうしてもうまくはまらない場合は、矢印キーのはんだ付けを調整してください

4. **設定スイッチの動作確認とキースイッチ取り付け**

   - 基板をトップケースにしっかり押し付けた状態で設定スイッチがスムーズに機能するか確認します
   - 四隅にキースイッチを付けて基板を仮止めします
   - 全てのキースイッチを取り付けます

5. **タッチセンサーの取り付け**

   - 左同様に取り付けます。
   - 下の写真では取り付け忘れています..

右側パーツ1 右側パーツ2 右側組み立て1 右側組み立て2 右側完成

### 2. トラックボールの取り付け

:::danger[FFC ケーブルについて　その１]

FFC ケーブルの取り回しが難しいです。強く曲げると断線する可能性があります。

特に、両端の青い部分を、青い部分が内側になるように曲げてしまう（導線部分が伸ばされるような曲げ方）ととても簡単に断線するようです。

以下の組み立て手順では設計上少し無理に曲げる必要があります。FFC ケーブルが断線してしまったと思われる場合はサポートしますのでご連絡お願いします。

:::

:::danger[FFC ケーブルについて　その２]

配布時期によって、FFC ケーブルの種類が微妙に異なります。
以下のように両端の青い樹脂部分の長さが短いもの（上）が入っている場合と、長いもの（下）が入っている場合があります。
樹脂部分が長いものは、干渉を避けるために下で説明するようにかなり曲げる必要があり、FFC ケーブル破損のリスクが特に高いです。
うまくトラックボールが動作しなかった場合は短いものに交換しますのでご連絡ください。



:::

**必要な部品**

- トラックボールセンサー基板
- FFC ケーブル
- トラックボールケース
- M2 ネジ（黒ケース：4mm、その他：3mm）× 3 本
- テープ

**組み立て手順**

1. **FFC ケーブルの接続**

   - トラックボールセンサーに FFC ケーブルを取り付けます
   - FFC ケーブルコネクタは、黒い部分が立った状態で差し込みます
   - 奥まで差し込んだ後、黒い部分を倒してロックします

| | |
| --- | --- |
| センサーとケーブル1 | センサーとケーブル2 |

2. **（青い樹脂部分が長い FFC ケーブルの場合のみ）FFC ケーブルの取り回し**

   - 上の注意書きで説明した青い樹脂部分が長い FFC ケーブルが同梱されている場合は、画像のように FFC ケーブルを適切に曲げます
   - **青い樹脂部分が短いケーブルの場合はここでは曲げる必要はありません。**
   - ケーブルコネクタを抑えながら曲げないと最悪コネクタが剥がれてしまう可能性があります。

ケーブル取り回し

3. **トラックボールケースに基板を取り付け**

   - バージョン v2.1.1 以降の場合:
     - エレコム/ぺリックス赤玉用と染色 POM 球用のアジャスターが同梱されています。
       センサー設置
     - 下の "エレコム赤玉用の取り付け方法" か "染色 POM 球用の取り付け方法" に従ってください。
     - フロストアクリル球（紫）も"染色 POM 球用の取り付け方法"で動作することを確認しています。
   - バージョン v2.1 以前の場合
     - 下の "バージョン v2.1 以前の場合" に従ってください。
   - エレコム/ぺリックス赤玉用の取り付け方法
     1. 板状の方のパーツを用意します。
        センサー設置
     2. センサーをケースに差し込み、裏側(レンズと逆側)から板状のアジャスターを差し込みます。
        FFC コネクター部分に力がかからないように注意してください。
        センサー設置
        センサー設置
     3. 奥までセンサーとアジャスターを両方奥まで差し込みます。
        アジャスターが出っ張っているとボトムケースと干渉するので奥まで差し込んでください。
        センサー設置
     4. レンズがずれている場合は少し調整します。
        （ケースの窓とレンズの位置は完全には一致せず、少しだけ左右にずれた状態にはなります）
        センサー設置
   - 染色 POM 球用の取り付け方法

     - ゆとりが少ないので難易度が少し高いかもしれないです

     1. センサーのレンズに画像のようにアジャスターはめ込みます
        センサーの左右の厚みとアジャスターの左右の厚みが同じになる向きで設定してください。
        センサー設置
        センサー設置
     2. アジャスターがずれないようにしながらトラックボールケースにセンサーを差し込みます。
        取り付け後にセンサーがずれないようにゆとりがない設計になっています。少し力を入れて差し込む必要があります。
        FFC コネクター部分に力がかからないように注意してください。
        センサー設置
     3. 奥まではめ込みます。奥まで挿さらない場合はアジャスターがずれている可能性があります。
        センサー設置
        センサー設置
        センサー設置
     4. レンズが大きくずれている場合は少し調整します。
        （ケースの窓とレンズの位置は完全には一致せず、少しだけ左右にずれた状態にはなります）
        センサー設置

   - 取り替える場合の外し方

     - ゆとりが小さいため取り外しは少し難しいです
     - レンズを傷つけないように注意しながら、ケースの窓から先の細いペンチ等でレンズの縁部分を押し下げることで取り外すことができます。
       レンズの球部分を傷つけないように注意してください。
       センサー設置

   - バージョン v2.1 以前の場合
     1. トラックボールケースにセンサーをはめ込みます
     2. センサーのレンズ部分がボール側になるような向きで差し込みます
     3. 差し込んだ後、奥まで押し込みます
     4. この時、FFC ケーブルに力を加えると外れたりずれてしまうので注意してください
        センサー設置

4. **ボトムプレートへの固定**

   - ボトムプレートにトラックボールケースをネジ止めします
   - 黒ケース：M2 4mm × 3 本
   - その他のケース：M2 3mm × 3 本

| | | |
| --- | --- | --- |
| センサー設置2 | センサー設置3 | ネジ止め |

5. **FFC ケーブルの固定**

   - テープで FFC ケーブルをボトムプレートに貼り付けます
     - **青い樹脂部分が短いケーブルの場合** ケーブルがトップケースについた基板と干渉しないように、図の方向に少しだけ FFC ケーブルを曲げるよう取り回して固定します。
     - 青い樹脂部分が長いケーブルの場合は前のステップですでに調整済みなのでそのままつけて問題ないはずです。
     - どちらの場合も、真上から見たときに FFC ケーブルの樹脂部分が見えない程度の状態で固定してください。
   - 固定する際は、トラックボール側に少しだけゆとりを持たせます。
   - これにより次の工程で端子に負担がかかったり、端子から抜け落ちることを防げます

| 青い樹脂部分が短いケーブルの場合 | 青い樹脂部分が長いケーブルの場合  |
| --- | --- |
|  | ネジ止め完了 |

6. **磁石の取り付けと極性調整**
   - ボトムプレートにネオジム磁石を取り付けます
   - 組み立て済みの左手を裏返して上から右ボトムプレートを置きます
   - ネオジム磁石の向きを互いに引き合う向きに調整します
   - ここでも接着剤で磁石をケースに固定すると安全です

| | |
| --- | --- |
| ケーブル固定 | 磁石取り付け |

7. **キーボード基板と FFC ケーブルの接続**

   - FFC ケーブルを取り付けやすいようにボトムケースを時計回りに１８０度回転させます
   - 写真のような感じで、FFC ケーブルをキーボード基板に接続します。

| | |
| --- | --- |
| 極性調整 | 位置確認 |
| |

8. **トッププレートのはめ込み**
   - トップケースをボトムケースにはめ込みます
   - **FFC ケーブルが縦を向いてしまって押し潰されないように注意してください。**
   - 軽くはめ込んだ後、トラックボールケース付近のトップケースを少し力を加えてピッタリはまるまで押し込みます
   - 裏からネジ止めして滑り止めを取り付けて完成です
   - 磁石を接着剤でつけていない場合、ボトムケースを左側から外す時に磁石がずれてしまうことがあります。ショートに繋がるので注意してください。

基板接続 最終組み立て

### 右完成！

お疲れさまでした

## 右側（トラックボールなし）

組み立て方は左側（トラックボールなし）とほとんど同じです。右側（トラックボールあり）の矢印キーの部分のだけ追加で参照して組み立ててください。

## 左側（トラックボールあり）

組み立て方は右側（トラックボールあり）とほとんど同じですが、トラックボール部分の FFC ケーブルの取り回しだけ少し違う部分があるので説明します。

1. FFC ケーブルの橋の青い部分を少し切り取る

   - 付属の FFC ケーブルの端の青い樹脂部分が長い場合は、取り回ししやすくするために樹脂部分を少し切り取る必要があります。



2. 以下の画像のようにケーブルを取り回す

| | |
| --- | --- |
|  |  |

| | |
| --- | --- |
|  |  |

3. トラックボールホルダーに以下の画像のようにはめ込みます。

| | |
| --- | --- |
|  |  |

## 完成！

おめでとうございます！DYA Dash v2.0 の組み立てが完了しました。

## 次のステップ

1. **使い方の学習**

   - [使い方ガイド](/dya-dash-keyboard/feature-guide/featureguide/)を参考に BLE のセットアップやキーマップのカスタマイズを行ってください

2. **カスタマイズ**
   - DYA Dash の ZMK ソースコードは [cormoran/zmk-keyboard-dya-dash](https://github.com/cormoran/zmk-keyboard-dya-dash) で公開しています。
   - キーマッピングのカスタマイズのほか、プログラミングが得意な方は、ファームウェアの改善にも挑戦してみてください。
   - ライブラリの改善やデフォルト設定の改善案があれば、リポジトリにプルリクエストを作成していただけると非常に嬉しいです

## 最後に

このビルドガイドは DYA Dash を使って書かれました。

普通の Row staggered キーボードと併用しても混乱が少なく、慣れていない状態でも大きなストレスなく使える携帯用キーボードに仕上がったのではないかと思っています。

作者は[DYA](https://github.com/cormoran/dya-keyboard)キーボード推しなので、DYA Dash を使うのは外出時が中心になりそうです。

楽しいキーボードライフをお過ごしください！

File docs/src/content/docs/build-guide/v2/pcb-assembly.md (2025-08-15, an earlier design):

---
title: 基板の組み立て
description: 基板の切り離しからはんだ付け、動作確認まで
sidebar:
  order: 3
---

基板の切り離しから始めて、はんだ付けと動作確認を行います。

## 注意点

- **XIAO と電池端子の取り付け**：難易度が高い作業なので、慎重に進めてください
- **片側ずつの組み立てる**：失敗時のダメージを減らすため、片側を完成させてから次に進むことをお勧めします

## 1. 基板の切り離し

最初の状態（裏面）

### 1.1 左右・トラックボール基板の分離

接続されている基板をニッパーで切り離します。

1. 下の矢印で示している、小さなドリル穴で接続されている部分（14 箇所）を切断します
   - 手で簡単に折れると思います。必要に応じてニッパーを使ってください。
   - **注意**：トラックボール基板は切断箇所ギリギリまで配線が通っているため、配線を傷つけないよう慎重に作業してください
2. バリが出た場合は、切断面をニッパーややすりで整えます
   - きれいに整えようとしすぎると基板の配線を破壊してしまう危険があるので、後でケースと干渉した場合に整える程度で大丈夫です。

切断箇所

切断後

### 1.2 トラックボールをつける部分の分離

トラックボールを取り付ける側の基板のみ、下中央部分を切り離します。

:::danger[注意]
**トラックボールを付けない側は切り離さないでください**
:::

1. （**右トラックボールの場合**）下の図で四角く囲った部分をカッターで深く傷を付けます
   - V2 基板には切る部分に白線と説明が書かれています。
2. 意を決して折ります。切り取った基板は不要なので廃棄してください
3. バリが出た場合はニッパーで整えます

以下は右手にトラックボールを付ける場合の例です。

左手トラックボールの場合は左手基板側を、両手トラックボールの場合は両方を切断してください。

右手基板の切断箇所

切断後の右手基板（表面）

## 2. 左手基板の半田付け

以下の例では、右トラックボールの場合の左手基板を解説します。

右手は次の章で差分のみ説明します。失敗リスクを下げるため、片側を完成させてから次に進むことをお勧めします。

左手トラックボール、両手トラックボールもスイッチソケットの半田付け箇所が増減する以外手順は同じです。

### ステップ 1：スイッチソケットの取り付け

付属の Kailh Choc v2 ソケットを基板にはんだ付けします。

まずいくつかのソケットを基板に並べてまとめてはんだ付けしていくと効率よく付けられます。

**注意点：**

- Kailh Choc v2 ソケットには[方向があります](https://scrapbox.io/self-made-kbds-ja/Kailh_Choc_%E3%82%BD%E3%82%B1%E3%83%83%E3%83%88%E3%81%AE%E6%96%B9%E5%90%91%E3%81%AB%E3%81%A4%E3%81%84%E3%81%A6)。
  黒い樹脂部の爪のような出っ張りが中心の穴側に来るようにしてください。
  - もし間違っても大きな問題はないとは思います。キースイッチがつけ外ししづらくなるかも？しれないです。
  - もし初めてで心配な場合は、まず１つ半田付けしてみて、表側からキースイッチを取り付けられるか確認してから全て取り付けると良いです。
- 実装済み部品との距離が近い箇所があります
  - 実装済み部品に触れたり熱を加えすぎると、部品が外れる可能性があります
  - 周りに部品が少ない箇所から始めることをお勧めします

| スイッチソケット取り付け途中 | 半田付け完了後 |
| --- | --- |
| スイッチソケット取り付け中 | スイッチソケット取り付け完了 |

### ステップ 2：XIAO の取り付け

:::danger

この作業は難易度が高く、やり直しは非常に困難です。よく読んでから作業してください。

:::

#### XIAO の左右パッドのはんだ付け

XIAO には左右の穴が空いたパッドと、裏側に表面実装パッドがあります。
まずは位置合わせをして左右のパッドをはんだ付けします。

1. **基板側のバリ取り**

   - XIAO 取り付け端子部分のバリをニッパーで切って整えます
   - **注意**：バリは引っ張らないでください。基板の面と裏を繋ぐ部分が剥がれると回路が動作しません

2. **位置合わせ**

   - XIAO を基板の裏側（部品が付いた側）に置きます
   - 基板外側のピンに XIAO 付属のピンヘッダを差して XIAO の位置を調整します（ピンヘッダは半田付けしません。位置調整の治具として使います。）

3. **内側パッドのはんだ付け**

   - XIAO がずれないよう注意しながら、基板内側（ピンヘッダをつけていない側）のパッドをはんだ付けします
   - 基板側パッドが見えない 2 箇所ははんだ付け不要です（次のステップで裏から付けます）

4. **外側パッドのはんだ付け**

   - ピンヘッダを取り外して、裏から基板外側のパッドをはんだ付けします。
   - XIAO と基板がしっかり接続されていることを横から確認してください

| バリ取り前 | バリ取り後 |
| --- | --- |
| バリ取り前 | バリ取り後 |

| XIAO の位置合わせ | 内側のパッドを半田付け |
| --- | --- |
| XIAO設置 | はんだ付け |

| 裏返して外側のパッドを半田付け | 外側のパッドをはんだ付け後に横から見た図 |
| --- | --- |
| 表面はんだ付け はんだ付け詳細 | 完了状態 |

#### XIAO の表面実装パッドのはんだ付け

基板表面から見て、以下の写真で矢印が示す 5 箇所をはんだ付けします。

**注意点：**

- 基板側にパッドがない右上の XIAO パッド（矢印なし）と上 4 つの穴ははんだ付け不要
- ある程度しっかりと熱を加えないと XIAO のパッドにはんだが付きません。熱を加えすぎると XIAO の表側の部品が外れたりするので加えすぎてもだめです。
- 隣り合うパッドをショートさせないよう注意してください
- **ショートした状態で電源を入れてはいけません**（電源のプラス・マイナスがショートして回路破損や電池発熱の原因）

ショートした場合ははんだ吸い取り線が必要です。どうしてもうまくいかない場合は、[こちらの方法](https://x.com/NetShini/status/1907390264152613021)も参考になります。

表面実装パッド

#### 簡易動作確認

基板が正常に動くか簡易チェックします。最初のステップで XIAO にファームウェアを書き込み済みである必要があります。
もしまだファームウェアを書き込んでいない場合は今書き込んでください。基板にはんだ付けしたまま書き込んで大丈夫です。

- **XIAO の** USB 端子を PC と接続します (基板に別の USB 端子がありますがこれは左右給電/通信用です)
- 正常に動作していれば自動的に基板の LED がアニメーション付きで光ります（XIAO の LED は光りません）
- LED が光らない場合は、はんだ付けまたはファームウェア書き込みに問題があります
- 確認後、USB ケーブルを外します

### ステップ 3：電池端子の取り付け

:::danger

やり直しは可能ですが難易度が高い作業です。取り付け向き（面・裏、プラス・マイナス）に注意してください。

:::

:::note

梱包時の不手際でマイナス端子の曲げ加工が一部されてない部品が同梱されている場合があります。
[追加事項](/dya-dash-keyboard/build-guide/v2/notes/#電池端子の曲げ加工がされていない場合)のページを参照して、同梱のマイナス端子が曲げ加工されたものかご確認ください。

:::

1. **治具の準備**

   1. 付属のブロック治具 3 つを用意します
   1. 基板を裏側を上にしてブロックの上に置きます。
   1. 基板の穴にブロックの突起がはまるようにします
      - 下の写真を参考にして、ブロックは電池端子から遠く、基板がガタガタせずに安定する場所に配置してください
      - **注意:** ブロックにはんだ付けの熱が伝わってしまうとブロックが溶けます

2. **電池端子をはめる**

   - 基板の電源スイッチ側（外側）にマイナス端子（バネ付き）を上（基板の裏側）から設置します。
     - 端子の細い部分を基板の穴にはめるように設置します。
   - もう一方の側（基板の内側）にプラス端子を設置します。
   - 基板に+-表記があるので参考にしてください。

3. **電池端子をはんだ付けする**
   - 端子が基板に垂直な状態を保ちながら、端子の細い部分（基板の穴に通した部分）をはんだ付けします
   - **注意:** はんだ付け直後の電池端子は非常に熱いので素手で触らないでください
   - 微調整する場合は、はんだを溶かしながらピンセットやペンチを使用してください

治具 基板設置 基板設置2

端子設置 はんだ付け完了 裏面確認

#### ケースとの干渉チェック

電池端子がケースと干渉しないかを確かめます。干渉する場合はハンダづけを少しやり直して調整します。

1. トップケースとバッテリートップカバーを用意します
   - 左（トラックボールなし）用はカバーに凹みがない方です
2. バッテリートップカバーをトップケースにはめます
3. トップケースに基板をまっすぐはめ込みます
   - トップケースと基板がピッタリくっつくか確認します

干渉チェック1 干渉チェック2 干渉チェック3

#### 簡易動作確認

電池で動作するかを確認します。

1. 単 4 電池を取り付けます
2. 電池のマイナス端子付近の電源スイッチをオンにします
   - 下側にスライドするとオンになります

正常に動作していれば、LED が光ります。バッテリーモードとして動くため、先ほど PC と接続した時とは少し違う光り方をして数秒後に LED が消えます。

LED が光らない場合は、XIAO の電池関連端子のはんだ付けに問題があるので XIAO の取り付けに戻ってはんだ付けを再確認してください。

### ステップ 4：設定ボタンの取り付け

左右両方に２個ずつついている設定ボタンを取り付けます。

1. 基板の表面を上にします
2. LED の真下のパッドの片側（図では下側）にはんだを軽く盛ります
3. ボタンの片側端子の半田付け
   - ピンセットやペンチで設定ボタンを保持しながら、2 で盛ったはんだを溶かしてボタンの片側端子をはんだ付けします
4. もう一つのボタンも同様に取り付けます
5. 残り端子のはんだ付け
   - 2 つのボタンの反対側端子をはんだ付けします
   - **注意**：近くの LED IC は熱に弱いため、長時間熱を加えすぎないでください

| 設定ボタンをつける箇所 | 下側のパッド２つに予備ハンダ  |
| --- | --- |
|  |  |

| 予備ハンダに設定ボタンの片側をつける | 完成図 |
| --- | --- |
| 片側はんだ付け | 完了 |

### 左側基板完成！

お疲れ様でした。

## 右手基板の半田付け

基本的に左手と同様の手順ですが、以下の２点が異なります。

**電源端子**

- 左右で鏡写しにしたような向きになります。
- 左右どちらも電源スイッチに近い側がマイナスです
- 基板に+-表記があるので確認しながら作業してください。

**矢印キーの取り付け（矢印キーありモデルのみ）**

右手には矢印キーが付きます。以下の手順ではんだ付けしてください。

1. スイッチ４つを表側から基板にはめ込みます。
2. 基板の裏側でスイッチの足を曲げて、スイッチを基板に水平に密着させます。
3. スイッチが基板にしっかりと密着していることを確かめながら、基板の裏から足をはんだ付けします。
   - **注意:** スイッチが傾いたり浮きすぎるとトッププレートに干渉します
   - ケースに遊びがほとんどないため、ケース組み立て時に再度調整が必要になるかもしれません。

:::note

V2 基板では下矢印キーが写真と比べて少しだけ下に出っ張った配置になります

:::

| 表から見た図 | 裏のはんだ付けする部分 |
| --- | --- |
| 十字キー取り付け | 裏面はんだ付け |

## トラックボール基板の半田付け

:::danger

IC の取り付け向きに注意してください。逆向きに付けると修復困難です。

:::

左右で同じ基板を使うので手順は左右共通です。
両側トラックボールの場合は以下のものを２個作ってください。

**準備するもの：**

- トラックボール基板（2 枚付属のうち 1 枚を使用、もう 1 枚は両側トラックボールの場合のみ使います）
- PMW3610 トラックボールセンサー IC
- トラックボールセンサー用レンズ

**手順：**

1. **IC を基板にはめる**

   - IC に一度レンズを取り付けます。
   - 写真を参考に、IC の足を基板にはめ込みます。
   - IC からレンズを外します。
     - **注意:** レンズは熱で溶けるので、レンズをつけたままはんだ付けしないでください。

1. **IC の半田付け**

   - IC が基板に対して平行になるように注意してください
   - 端のピンを最初にはんだ付けすると IC が固定されて作業しやすくなります
   - **注意:**
     - レンズは熱で溶けるので、レンズをつけたままはんだ付けしないでください。
     - 長時間はんだごてを当てると IC 破損の可能性があるので注意してください

1. **レンズの取り付け**

   - IC に付いていた茶透明な**保護フィルム２つを剥がします**
     - これを忘れるとトラックボールの感度が悪くなります。
   - レンズをセットします

1. **レンズ足の処理**
   - IC の表側に出っ張っているレンズの足を処理します
   - このままではケースと干渉するため、以下のいずれかの方法で処理してください
     - はんだごてで熱を加えて潰すように溶かす（レンズが外れにくくなる）
     - ニッパーで切断（ケース干渉を確実に防げる。作者はこの方法でやっています）
   - 一番最後の写真を参考にしてください。

使用パーツ 向き確認1 向き確認2

レンズを外してはんだ付け 保護シール剥がし レンズ取り付け レンズ足処理

## 左右基板の動作確認

左右両方の電源を入れて PC とペアリングし、キーボードとして動作するか確認します。

1. 左右の基板に電池をつけます。電池がない場合は USB で接続しても良いです。
1. （電池をつけた場合は）左右の電源スイッチを ON にします
1. LED 表示されることを確認
   - 電源を入れると LED が光り、バッテリー残量を表示後、BLE 接続状態を表示します
   - [解説 YouTube 動画](https://youtu.be/y6X2OnoMX-M)も参考にしてください
1. PC とペアリング
   - 電源を入れると右手基板が自動的にペアリングモードに入ります。Bluetooth 機器で新しいデバイスを探すと、DYA Dash というデバイスが見つかるのでペアリングしてください。
   - なお、左右の基板は電源を入れた際に自動的にペアリングされます。
1. キー入力を確認
   - 基板のスイッチソケットにいくつかスイッチをつけて押してみます
   - 対応する文字が入力されるはずです

## トラックボールの動作確認

次に、トラックボール基板を接続してトラックボールモジュールが動作するか確認します。

1. 電池や USB 接続を外して電源を切ります。
1. 下の図を参考に FFC ケーブルでトラックボールをつける側の基板とトラックボール基板を FFC ケーブルで接続します。
   - FFC ケーブルは繊細なので扱いに注意してください。
   - ケースの組み立て説明にもいくつか写真があるので、わからない場合はケースの組み立ての章も読んでみてください。
1. 電池や USB 接続で電源を入れます
1. PC とペアリング or USB モードで接続している状態でトラックボールモジュールのレンズの 1~2mm 上で指を水平に動かしてみます
1. マウスが動いたら動作確認成功です。
1. 電源を切った後、FFC ケーブルを外してください

| FFC 端子の黒い部分が縦の状態で FFC ケーブルを奥まで差し込む | 黒い部分を倒してロックする |
| --- | --- |
| センサーとケーブル1 | センサーとケーブル2 |

## トラブルシューティング

**LED が光らず、ペアリングもできない場合：**

- XIAO と基板のはんだ付けまたはファームウェア書き込みに問題があります
- 電源をオフにして XIAO を PC と接続してください（PC 電源で動作確認）
- PC から電源供給でペアリングできる場合は、はんだ付けの問題です

**ペアリングできるが LED が光らない場合：**

- XIAO と LED の間のはんだ付けに問題があります
- XIAO の裏面パッドのはんだ付けを見直してください

**LED が光るがペアリングできない場合：**

- 左右に書き込むファームウェアを逆にしている可能性があります
- 両方に左側用ファームウェアを書き込んでいる可能性があります
- XIAO を PC に接続し、リセットボタンをダブルクリックしてファームウェアを書き込み直してください

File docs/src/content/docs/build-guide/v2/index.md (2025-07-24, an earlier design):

---
title: 組み立ての流れ
description: DYA Dash v2.0の組み立てガイドです
sidebar:
  order: 0
---

このページは [Booth](https://cormoran707.booth.pm/items/6913095) で配布中の DYA Dash v2.0 向けの組み立てガイドです。

:::caution
一部の画像は v1.0 試作版のものを使用しているため、実際の同梱物と異なる場合があります。
:::

## 更新履歴

| 日付 | 内容 |
| --- | --- |
| 2025/06/15 | v2.0 向けビルドガイドを仮公開 |
| 2025/06/17 | v1.0 向けの内容を v2.0 向けに書き換え |
| 2025/06/21 | ガイドを Web ページに変換、内容をわかりやすく改善 |

## 組み立ての流れ

1. **[事前準備](/dya-dash-keyboard/build-guide/v2/preparation)** - 必要な部品と工具の確認
2. **[ファームウェア](/dya-dash-keyboard/build-guide/v2/firmware)** - XIAO へのファームウェア書き込み
3. **[基板組み立て](/dya-dash-keyboard/build-guide/v2/pcb-assembly)** - 基板のはんだ付けと動作確認
4. **[ケース組み立て](/dya-dash-keyboard/build-guide/v2/case-assembly)** - ケースの組み立てと完成

## 完成イメージ

完成した基板（裏面）

完成した基板（表面）

完成品

## 困ったときは

- 部品が不足している場合は、購入プラットフォームのメッセージ機能でお早めにご連絡ください
- 組み立てに失敗した場合や、なぜかうまく動かない場合も可能な限りサポートしますのでお気軽にご相談ください。

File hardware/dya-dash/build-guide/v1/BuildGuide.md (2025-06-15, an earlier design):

#  DYA Dash v1.0 (試作版) ビルドガイド

https://cormoran707.booth.pm/items/6913095 で過去に配布した"試作バージョン１"のビルドガイドです。

> [!CAUTION]
> このビルドガイドは過去に配布したバージョン向けのものです。最新バージョンとは異なる部分があります。

## 更新履歴

| 日付 | 内容 |
| --- | --- |
| 2025/05/12 | ビルドガイドを公開 |
| 2025/05/15 | 内容を推敲、画像を少し追加 |

## 別途購入が必要な部品

- XIAO nrf52840 x2 (試作 V1 ではキットに付属)
  - 基板に直接はんだ付けします
- Kailh Choc v2 ロープロファイルキースイッチ 43 個(片側トラックボールの場合)
  - Kailh Lofree Low-profile POM 系のピンが２ピンのものが使えます
  - ３ピンのものはピンを切れば使えるかも？持ってないのでわかりません
  - トッププレートの厚みは 2.0mm です
  - Deep sea silent mini, Lofree Ghost, Kailh White Rain Switch ではいい感じに使えました
- キーキャップ一式
  - 1U 39 個
  - 1.5U 2 個
  - 1.25U 2 個 (1U でも一応 OK)
  - [YMDK 116](https://ja.aliexpress.com/item/1005006981216357.html) と [THT low profile](https://talpkeyboard.net/items/66795277401c310b1f80e83f)(1.25U は存在しない)が使えることは確認しています
  - トラックボールの真横のキーキャップが親指と干渉しがちなので、より小さなキーキャップを使った方が快適と思われます
- 25mm トラックボール用ボール
  - [エレコムの赤いボール](https://www.amazon.co.jp/%E3%82%A8%E3%83%AC%E3%82%B3%E3%83%A0-%E3%83%88%E3%83%A9%E3%83%83%E3%82%AF%E3%83%9C%E3%83%BC%E3%83%AB%E7%94%A8%E4%BA%A4%E6%8F%9B%E3%83%9C%E3%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)がおすすめです。
  - [ペリックスの深い赤](https://www.amazon.co.jp/Perixx-%E3%83%9A%E3%83%AA%E3%83%83%E3%82%AF%E3%82%B9-PERIPRO-305GRD-%E4%BA%A4%E6%8F%9B%E7%94%A8%E3%83%88%E3%83%A9%E3%83%83%E3%82%AF%E3%83%9C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)は感度が悪く微妙でした。（ケース設計の問題かも）
  - X にいる染色職人の方々が作っているボールでも使えるはずですが、色によって感度が変わります
- 単４電池 x2
  - ファームウェアのバッテリー残量はニッケル水素電池向けに調整されています
  - アルカリ乾電池等も使えると思われますが未検証です
- USB ケーブル
  - データ通信に対応した Type C ケーブル（PC 接続用、ファームウェア書き込み用）
  - （現在のファームウェアでは未対応/未検証）データ通信に対応した Type C to C ケーブル（左右接続用）
- 適当なテープ
  - FFC ケーブルをケースに固定するために使います

## 必要な工具

- はんだ、はんだごて
  - 温度調整機能付きのハンダゴテがおすすめです
  - [C 型のコテ先](https://lang-ship.com/blog/work/900m/#toc19)をおすすめしておきます
  - はんだ吸い取り線もあると、失敗した時のリカバリーに非常に役立ちます。
- ニッパー
- プラスドライバー
  - ２種類の M2 ネジが付属しています
  - それぞれプラスドライバの径が違うので精密ネジ用と普通ネジ用の２種類が必要かもしれません (TODO: ドライバのサイズを調べる)

## キットに含まれる部品

- 回路基板（左、右、トラックボール基板 x2 が接続されたもの、厚み 1.2mm）
  - このガイドではトラックボール基板１つは使いません
- 3D プリント製ケース　計５パーツ（左ボトム、右ボトム、左トップ、右トップ、右用トラックボールホルダー）
  - トラックボールホルダーにはセラミックボール x3 が取り付け済みです
- 3D プリント製ボタン
  - 設定ボタン x2
  - 矢印キーボタン x4
  - 電源スイッチカバー x2
- 電子部品
  - 設定ボタン用タクトスイッチ x2
  - 電源用スライドスイッチ x2
  - 矢印キー用やわらかいタクトスイッチ x4
  - PMW3610 トラックボールセンサー x1
  - トラックボールセンサー用レンズ x1
  - FFC ケーブル x1
  - 電池ケース端子
    - プラス極 x2
    - マイナス極 x2
  - Kailh Choc v2 ホットスワップソケット x43
    - 予備で少し多めに入れておく予定です。
  - 7pin ピンヘッダ x4(XIAO 取り付け用)
    - XIAO を買ったらついてくるかもしれませんが余っているので念のために入れています
- ねじ
  - M2 12mm x4 (タッチセンサー用)
  - M2 5mm x15 (トップ/ボトムケース固定用)
  - M2 4mm x3 (トラックボールケース固定用)
- 滑り止め x8
- XIAO と 7pin ピンヘッダを半田付けするための 3D プリント製補助具 x2
- ネオジム磁石 x6

| 梱包された状態 | 回路基板以外のすべての部品 |
| --- | --- |
|  |  |

## 特別な注意点

- FFC ケーブルの面裏に注意、FFC ケーブルを丁寧に取り扱うこと。
- ネジを強く締めない。3D プリントケースの穴が簡単に潰れます。
- XIAO の取り付け、電池端子の取り付けは少し難しいので覚悟してください

## 未解決の不具合/機能

2025/05/11 現在

- Deep sleep から復帰後にトラックボールが動作しません　手動で電源を一度オンオフする必要があります
  - ファームウェアの改善で解決できる可能性がありますが、回路設計上の問題で解決できない可能性があります
  - 最悪 Deep sleep に入るまでの時間を調整したり、deep sleep に入らないようにすることで回避は可能です
- 左右有線通信のための USB ポートがありますがファームウェアには未実装です。
  - 現在 ZMK 本体で開発中の機能に対応させる予定ですが、ピン数を減らすために少し挑戦的な回路設計になっており、思い通りに動くかわかりません。
  - 最悪でも左右給電用途としては使えるはず？
- ファームウェアのどこかにバグがありそう
  - たまに LED が消えずについたままになったりするのを観測しています
  - これはがんばって改善します...

## 組み立て手順

### 基板の最終状態

| 左手を裏から見た写真 | 右手を裏側から見た写真 |
| --- | --- |
|  |  |

## 1. ファームウェアの書き込み

1. XIAO nrf52840 を２つ用意します。
2. [リリースページ](https://github.com/cormoran/dya-dash-keyboard/releases) から `zmk_dya_dash_left.uf2` と `zmk_dya_dash_right_studio.uf2` をダウンロードします
3. １つ目の XIAO nrf52840 を USB で PC と接続して、リセットボタンを素早く２回押します
   - [こちらのサイトなどが参考になります](https://qiita.com/KentaHarada/items/3e1612116ec45462a837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)
4. PC に `XIAO-SENSE` という名前で USB メモリのようなデバイスが接続されるので、`zmk_dya_dash_left.uf2` をそこにドラッグ&ドロップします
5. `XIAO-SENSE` が自動で切断されて ZMK ファームウェアが動き始めます
6. 同様にしてもう一つの XIAO に `zmk_dya_dash_right.uf2` を書き込みます。

どちらに左右のファームを書き込んだか覚えておいてください。

Step4 では左のファーム（`zmk_dya_dash_left.uf2`）を書き込んだ XIAO を左手側に、右のファームを書き込んだものを右側の基板に取り付けます。

もし左右がわからなくなった場合は XIAO を半田付けした後でもう一度上のステップを行なってファームを書き込んでください。
プログラムは左右で役割が異なるため、逆につけていると入力されるキーなどが逆転します。電子回路的には左右で同じ構成なので、間違えて左右逆に取り付けても回路は壊れないです。

キーボードを USB 接続で使う際は、右側の XIAO のポートを PC と接続します（[FeatureGuide](./FeatureGuide.md)参照）

## 2. 基板の切り離し

### 2.1 左右/トラックボール基板の切り離し

繋がっている基板をニッパー等で切り離します。

下の画像で矢印で示されている、小さなドリル穴で接続されている部分を切断してください。
**トラックボール基板は切断箇所ぎりぎりまで配線が通っています。** 配線を傷つけないように注意してください。

バリが出た場合は切断面をニッパーで整えます。

### 2.2 トラックボールをつける部分の基板の切り離し

**右側**基板（部品が付いている側を裏側にした時に右手にあたる方）の下の部分の基板を切り離します。
**左手側は切り離さない**でそのままにします。

繋がっている部分をカッターなどで傷つけて、ある程度深くまで傷つけられたら、意を決して折ります。
切り取った基板は使わないので捨ててください。
バリが出た場合はニッパーで整えます。

| 最初の状態 | 2.1 小さなドリル穴で繋がってる部分を切る | 2.2 右手基板のトラックボール部分を切る | 右手を表から見た図  |
| --- | --- | --- | --- |
| 以下は**裏面**を上にした状態です。　 | 下の矢印部分１４箇所です。  | 下の枠で囲った部分です。**右手基板のみを切ってください！！**  |  |

## 3. はんだづけ

### 3.1 キーボード基板

以下の部品を順にはんだ付けしていきます。
説明では左手を中心に解説し、右手は差分だけを解説します。間違った時のダメージを減らすために片側を先に組み立てると良いです。

1. スイッチソケット
2. ピンソケットと XIAO
3. 電源スイッチ
4. 電池端子
5. 設定ボタン用タクトスイッチ、十字キー用タクトスイッチ

#### 左手基板の半田付け

##### 1. スイッチソケットを半田付けします。

**kailh choc v2 ソケットには[方向があります](https://scrapbox.io/self-made-kbds-ja/Kailh_Choc_%E3%82%BD%E3%82%B1%E3%83%83%E3%83%88%E3%81%AE%E6%96%B9%E5%90%91%E3%81%AB%E3%81%A4%E3%81%84%E3%81%A6)**。爪のような出っ張りが中心の穴側に来るようにしてはんだ付けしてください。（方向を間違ってもスイッチを差しづらくなるだけで、大きな問題なく使えるとは思います。）

| 最初の状態 | 左手にスイッチソケットを載せた状態 | スイッチソケットを半田付けした状態 |
| --- | --- | --- |
|  |  |  （写真ではすでに XIAO が乗ってますが次のステップで乗せます） |

##### 2.1 XIAO を半田付けします。

難しいのでよく読んでください。（設計を微妙にミスしてピンヘッダを使う方法にしています。）
やり直しは非常に困難です。

1.  XIAO を図のように基板の裏側（部品がついた側）に乗せます。
2.  XIAO の側からピンヘッダの長い側を挿します。この時、ピンヘッダと同じパックに入っている白い治具を図のようにピンヘッダと XIAO の間に挟みます。これで、表側に少しだけピンの頭が出るような状態になるはずです。XAIO は基板と密着している状態です。
3.  表側（電子部品がついてない側）の、白い治具をつけていない側からピンソケットを半田付けします。
    **白い治具は熱で溶けます** ２ピンくらいつけたら治具を外して、残りのピンをはんだ付けします。
    半田付けの際は、ハンダを盛りすぎないようにしてください。表に飛び出た部分が大きいとトッププレートに干渉します。
4.  XIAO の逆サイドも同様にしてピンを半田付けします。表から見ると写真のような状態になります
5.  基板を裏返して、XIAO を基板にしっかり密着させた状態で XIAO とピンヘッダをはんだ付けします。
6.  ピンヘッダの XIAO 側に飛び出た部分をニッパー等でカットします。この時、XIAO の金属シールドよりもピンヘッダが低くなるようにカットしてください。ピンヘッダが金属シールドより高く飛び出ているとボトムケースと干渉します。

| 1.XIAO を基板に乗せた状態 | 2.XIAO にピンヘッダを指して、治具をつけた状態 | 4.表面をはんだ付けした状態 | 6.XIAO のパッドをはんだ付けして、ピンヘッダを切った状態 |
| --- | --- | --- | --- |
|  |  |  |  |

##### 2.2. XIAO の表面実装パッドを半田付けします。

基板の表面から見て、下の写真で矢印で示した３箇所を半田付けします。
基板側にパッドがない一番右下の XIAO のパッド（矢印で示していない部分）は半田付け不要です。

ある程度しっかりと熱を加えながらハンダをつけないと XIAO のパッドにハンダがつかないです。
隣り合うパッドは２つがお互いにショートしないように気をつけてください。ショートしてしまった場合ははんだ吸い取り線が必要と思われます。

**※ショートした状態で電源を入れてみてはいけません。電源のプラスとマイナスがショートした状態になって回路が壊れたり、電池が発熱したりします。**

どうしてもうまくいかない場合は、こんな方法でつけている人もいるようです https://x.com/NetShini/status/1907390264152613021 僕は普通にはんだづけしています。

| ３箇所を半田付け（下の写真では左上をまだ半田付けしていません） |
| -------------------------------------------------------------- |
|                                           |

##### 3. 次に電源スイッチをつけます

基板裏側からスイッチをつけて表側ではんだ付けします。　半田付けしたら表側の出っ張りができるだけないようにピンを切って処理します。

| スイッチをつける場所  | スイッチを挿した状態  | 表側を向けた状態 | 半田付けした状態 |
| --- | --- | --- | --- |
|  |  |  |  |

##### 4.1 電源端子をつけます

難易度が高いです　**取り付け向きにも注意してください**。

**バネがついたマイナス極端子**を基板外側（**電源スイッチの側**）に半田付けします。
図のようにまずは基板表面のみはんだ付けします。（次のステップで位置が問題ないことを確認してから追加で半田付けします。）
この時、端子の両サイドについた２つのでっぱりが、ちょうど基板の厚みの中心あたりに来ることを確認して半田付けしてください。高さがずれている場合は端子を少し曲げて微調整してください。位置がズレると上下のケースと干渉します。

| マイナス端子を基板に乗せた状態 | 端子のでっぱりがちょうど基板の厚みの真ん中あたりにくる | 表面からはんだづけ |
| --- | --- | --- |
|  |  |  |

##### 4.2 プラスの電源端子をつけます

要領はマイナス端子と同じですが、うまく固定できなくて難しいかもしれません。

| プラス端子を表面から半田付け | でっぱり部分が基板の厚みの真ん中あたりに来るように |
| --- | --- |
|  |  |

##### 4.3 ボトムケースとの干渉チェック

両方取り付けたら一度ボトムケースに入れてみてください。入れた時に電池端子が干渉しない（基板がボトムケースの高さより高く出っ張らない）ことを確認してください

|                        |
| ---------------------- |
|  |

##### 4.4 トップケースとの干渉チェック

トップケースにも一度はめこんでみてください。電池端子部分は少し無理やりはめ込む必要があります。**が、力を入れるとカバー部分が割れる可能性があります。** 3D プリントの方法に少し問題があるようなので現在設計を再検討中です。
もし割れてしまった場合は購入したプラットフォームで相談もらえれば改善後のバージョンを再送します。公開中の 3D データも更新予定です。

ぴったりはめ込んだ時にトップケースと基板の隙間がほぼなくなる状態になることを確認してください。

|                        |
| ---------------------- |
|  |

##### 4.5 追加のはんだ付け

電源端子の位置が問題ないことを確かめられたら、強度を上げるために追加ではんだ付けします

| | |
| --- | --- |
|  |  |

##### 5. 設定ボタンを半田付けします

表面から設定ボタンを取り付けて、裏面ではんだ付けします。
しっかりと押し込んで固定した状態で半田付けしてください。

| 設定ボタンを取り付け | 裏側のピンを曲げて固定 | 半田付け |
| --- | --- | --- |
|  |  |  |

##### 簡易動作確認

ここまでできたら、電源端子の ± が正しい方向になっているかもう一度確認してください。
正しいと確信できたら、左右に電池を取り付けて電源を入れてみてください。
電源は下にスライドするとオンになります。

電源を入れた際に LED が光ってバッテリー残量を表示後、BLE 接続状態を表示します。
（左は黄色のアニメーション、右は一つ目の LED が黄色く点滅すると思います。）

LED が光らない場合は何かがおかしいです。

#### 右手の説明

基本は左手と同じようにはんだ付けしていきます。違う部分と注意点だけを解説します。

##### 電源端子

**電源端子の向きに注意してください。** 左手をちょうど鏡に写したようになる状態（マイナス端子は常に電源スイッチの側）が正しいです。

|                           |
| ------------------------- |
|  |

##### 十字キー

右は設定ボタンの代わりに十字キーがつきます。以下のような雰囲気で半田付けします。スイッチが基板にしっかりと並行に密着した状態で半田付けします。傾いたり浮きすぎているとトッププレートに干渉します。

| 十字キーの部分にスイッチを取り付け | 裏側から半田付け |
| --- | --- |
|  |  |

### 3.2 トラックボール基板

1. キット同梱の以下の３つのパーツを用意してください
   基板は２つ付属していますが、このガイドでは１つしか使いません。２つの基板は両方同じ回路なのでどちらを使っても良いです。残りの一個はおまけです。

2. IC を以下のような方向で基板にはんだ付けします。 IC が基板に対して平行になるようにしてください。半田付け前にレンズがセットできるか確認することをお勧めします。 レンズは熱で溶けるので、半田付けはレンズを外した状態で行ってください。
   端のピンをまずはんだ付けすると IC が固定されて作業しやすくなります。
   長時間はんだごてを当てると IC が破損する可能性があるので注意してください。

3. IC を取り付けたら、IC についていた透明な保護フィルムを剥がしてレンズをセットします

4. 最後に IC の表側に出っ張っているレンズの足を処理します。
   このままではケースと干渉するので、出っ張りをニッパーで切断するか、ハンダゴテで熱を加えて潰すように溶かしてください。
   レンズが外れないように溶かすのが推奨されている方法のようですが、作者はニッパーで切断しています。

| 使うパーツ | 向き | 向き | レンズを外して半田付けします |
| --- | --- | --- | --- |
|  |  |  |  |

| 保護シールを剥がします | レンズを取り付けます | レンズの足を処理します |
| --- | --- | --- |
|  |  |  |

### 3.3 タッチセンサー端子の取り付け

はんだ付けは不要です

基板の裏から M2 12mm ネジを差し込んでタッチセンサーボタンをねじ止めします
安定して通電するようにある程度しっかりと止める必要がありますが、強く締めすぎるとネジが基盤パターンをえぐるように破壊してしまいます。適度な強さで締めてください。
タッチセンサーボタンの方向をトッププレートの穴に入るように整えます。

| | |
| --- | --- |
|  |  |

## 5. 動作確認

左右に両方に電池を取り付けて電源を入れてみてください。
電源は下にスライドするとオンになります。

電源を入れた際に LED が光ってバッテリー残量を表示後、BLE 接続状態を表示します。[解説 Youtube 動画](https://youtu.be/y6X2OnoMX-M)を参照してください。

左右は自動的にペアリングするはずです。

この状態で Bluetooth 機器（PC or スマホ）からペアリングすることができます。

ペアリングできたら、基板のスイッチソケットにいくつかスイッチを挿して押してみてください。対応する文字が入力されるはずです。

- LED が光らずペアリングもできない場合：XIAO と基板のはんだ付けがうまくいっていないか、プログラムがうまく書き込めていません。
  - 電源をオフにして XIAO を PC と繋いでみてください。PC から電源が供給されます。もしペアリングできるようになった場合は半田付けの問題です。
- ペアリングできるが LED が光らない場合：XIAO と LED の間のはんだ付けがうまくいっていないようです。XIAO の裏面のパッドの半田付けを見直してください。
- LED が光るが、ペアリングできない場合：左右に書き込むファームウェアを逆にしているか、両方に左側用ファームウェアを書き込んでいる可能性があります。XAIO を PC に接続して、リセットボタンをダブルクリックしてファームウェアを書き込み直してみてください。

## 6. ケースの組み立て

基板、トッププレート、キースイッチを組み立てます

### 左側

1. トッププレートに設定ボタン x2 をはめ込みます
2. トッププレートを基板にはめ込みます
3. ねじと干渉しない部分のキースイッチを取り付けます
   - スイッチを取り付ける際はできるだけソケットを裏から押さえながら取り付けてください。ソケットが基板から剥がれる悲しい事故が防げます。
   - スイッチの向きに注意してください。一部のソケットは向きが違います。
   - スイッチの端子が曲がっていないか確認して、端子が確実にソケットに入ることを確認しながら取り付けてください。うまく挿さっていない状態で無理に押し込むと端子が曲がってスイッチが使えなくなったり、ソケットが基板のパターンごと外れてキーボードが使えなくなります。
4. （写真がない）ボトムケースの３つの穴の部分にネオジム磁石を入れます。向きは右側で調整するので適当で良いです。
5. （写真がない）**電源ボタンにカバーを取り付けます** （忘れやすいので注意。あとで忘れたことに気づいたらネジを外してから取り付けてください。）
6. トッププレートと基板をボトムプレートにはめ込んでねじ止めします。
   - USB ポート部分から差し込むようにはめ込んでください。
   - 全てのネジを閉める必要はありません　動かない場合に取り外すことも考えて４隅４〜５個のねじを適宜つけてください。
   - トッププレートとボトムプレートに微妙に隙間ができるかもしれませんが、現状では仕様です。
7. 残りのスイッチを取り付けます。スイッチの向きがソケットと合っていること、端子が曲がっていないことを確かめて優しく取り付けてください。
8. ボトムケースの裏側に滑り止めシールを取り付けます
   - 滑り止めにちょうど合いそうなシルエットがついているのでそれに合わせて貼ってください。
   - 滑り止めに貼られた保護フィルムを剥がします。
   - 滑り止めは市販のちょっと良さげなやつ(?) https://sss-create.com/collections/griplus を使っています

| | | | |
| --- | --- | --- | --- |
|  |  |  |  |

| | | | |
| --- | --- | --- | --- |
|  |  |  |  |

### 右側

トラックボールをつける部分が難しいです。

1. トッププレートに矢印キーボタン x4 をはめ込みます
   - 矢印キーボタンには一面だけ横方向への出っ張りが小さい面があります。下の写真のような向きではめ込んでください。
2. トッププレートを基板にはめ込みます
3. ねじと干渉しない部分のキースイッチを取り付けます
4. （写真がない）**電源ボタンのカバーを取り付けます** （忘れやすいので注意。あとで忘れたことに気づいたらネジを外してから取り付けてください。）
5. トラックボール基板に FFC ケーブルを取り付けます。
   - 基板側の端子の黒い部分が立った状態でケーブルを差し込みます。
   - ケーブルは青い樹脂がついた側が基盤と逆側で、金属端子が剥き出しの側が基板とくっつく向きが正しい向きです。
   - 奥まで差し込めたら、黒い端子を奥の方に倒してケーブルを固定します。
   - 固定はあまり強くないので、以降のステップで引っ張らないように注意してください。
6. トラックボール基板をトラックボールケースにはめ込みます
   - 少しきついですが基板を壊さないように注意しながら少し力を入れてはめ込みます
   - **はめ込み方にコツがあるので下の写真で細かいステップを解説しています。**
7. トラックボールケースとボトムケースを黒い M2 ねじ x3 でねじ止めします。
8. FFC ケーブルをボトムケースにテープで固定します。基板と上手く干渉しないようにケーブルを収めた状態で固定してください。
9. 左手キーボードを右手の裏側に合わせるように置いて、右手のボトムケースにネオジム磁石３個をセットします。
   - 左手側の磁力で磁石が引きつけ合う方向にセットされるはずです。
10. キーボード基板に FFC ケーブルを取り付けます
    - 少し難しいと思いますが、FFC ケーブルを引っ張らないように気をつけながら作業してください。
11. FFC ケーブルをうまく取り回しながらキーボード基板をボトムケースにはめ込みます
12. ねじ止めします　ここでも全てのネジを止める必要はありません。
13. 残りのスイッチを取り付けます
14. ボトムケースの裏側に滑り止めシールを取り付けます

| 1. 矢印ボタンの方向 |
| ------------------- |
|   |

| 5 トラックボール基板に FFC ケーブルをつける | 6.1 図示した下側の角から先にケースに入れる | 6.2 もう一方の下側の角をはめる | 6.3 上から水平に押し込む |
| --- | --- | --- | --- |
|  |  |  |  |

| 6.4 図示した奥の角を押し込む | 6.5 奥方向へ横に押し込む | 7 ボトムケースにセット | ねじどめ |
| --- | --- | --- | --- |
|  |  |  |  |

| ３箇所ねじ止めした状態 | FFC ケーブルをうまく取り回す | テープで止める | 左手の裏側の上に右手ケースを乗せてボトムケースに磁石取り付け+右手基板を FFC ケーブルに接続 |
| --- | --- | --- | --- |
|  |  |  |  |

| トラックボールケースとトッププレートが干渉している状態 | 無理やり押し込みます |
| --- | --- |
|  |   |

## 完成！

[使い方ガイド](./FeatureGuide.md) を参考にして BLE のセットアップやキーマップのカスタマイズをしてください。
プログラミングが得意な方はファームウェアの改善にも挑戦してみると楽しいです。
ライブラリの改善やデフォルト設定の改善案などがあればこのレポジトリにプルリクエストを作ってもらえるとありがたいです。

## 最後に

このビルドガイドは DYA Dash を使って書かれました。

普通の Row staggered キーボードと併用しても混乱が少なく、慣れていない状態でも大きなストレスなく使えるキーボードに仕上がったのではないかと思っています。

と言いつつ、作者は [DYA](https://github.com/cormoran/dya-keyboard)キーボード推しなので DYA Dash を使うのは外出時が中心になりそうです。

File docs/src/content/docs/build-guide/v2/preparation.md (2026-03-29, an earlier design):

---
title: 事前準備
description: 必要な部品と工具の確認
sidebar:
  order: 1
---

組み立てを始める前に、必要な部品と工具を確認します。

## キット同梱部品の確認

### 片側トラックボールの場合

3D プリント製パーツは非常に小さく種類もたくさんあります。
組み立て前に全てのパーツが入っているか確認お願いします。

パーツが足りなさそうな時はできるだけ早く対応するので購入したプラットフォームのメッセージ機能で連絡ください。

2025/08 以降は以下のように部品を分けてパッキングしています。それ以前はパッキング方法が異なります。

なお、画像にはパッキング状態と取り出した状態を両方載せています。２セット入っているわけではありません。

| パック | 内容物 | 画像 |
| --- | --- | --- |
| 基板&ケースパック | <ul><li>回路基板(厚み 1.2mm)</li><li>トップケース左右</li><li>ボトムケース左右</li><ul> |  |
| トラックボールケースパック | <ul><li>トラックボールケース x1</li><li>セラミックボール x3（取り付け済み）</li><li>センサー位置調整版２種類(**2025/08/10 以降**)</li></ul> |  <br>一番右側の部品にセラミック球が取り付けてあります |
| 部品パック１ | <ul><li>設定ボタン x4</li><li>タッチセンサーカバー x4</li><li>エンブレムプレート x2</li><li>電源スイッチカバー x2</li></ul> |  |
| 部品パック２ | <ul><li>電池カバー上 x2（左用と右用）</li><li>電池カバー下 x2</li><li>設定ボタンカバー x2</li><li>組立時に使う治具</li></ul> |  |
| 電子部品パック | <ul><li>設定ボタン用タクトスイッチ x4</li><li>電池ケース端子２組（プラス極 x2 マイナス極 x2）</li></ul> |  |
| トラックボールセンサーパック | <ul><li>PMW3610 トラックボールセンサー x1</li><li>トラックボールセンサー用レンズ x1</li></ul> |  |
| ネジパック | <ul><li>ケース固定用 M2 4mm x8</li><li>トラックボールケース固定用 M2 4mm x2</li><li>タッチセンサー用 M2 12mm x4</li></ul><br>※配布時期によって種類と個数が少し変わります。<br>※少し多めに入っていたり、予備のセラミック球がおまけで入っていることがあります。 |  |
| 磁石パック | <ul><li>ネオジム磁石 x8</li></ul> |  |
| その他 | <ul><li>6pin FFC ケーブル x2（１つは予備）</li><li>Kailh Choc v2 ホットスワップソケット x50</li><li>滑り止めゴム x8</li></ul> |  |
| 矢印キーありモデルのみ：<br>矢印キーパック | <ul><li>柔らかいタクトスイッチ x4</li><li>矢印キーカバー</li><li>矢印キー用ボタン x4</li></ul> | 準備中... |

### 両側トラックボールの場合

片側トラックボールの場合に加えて

- 25mm トラックボールホルダーが両側分入っています
- FFC ケーブルが両側分（２つ）になります
- トラックボールホルダー固定用ネジが +2 個、合計 4 個つきます
- (別料金でご購入いただいた場合) PMW3610 センサーとレンズ

:::danger[トラックボールホルダーのセラミック支持球]

取り付けているセラミック支持球（2mm ベアリングボール）は圧入してるだけのため、圧入が甘いと外れてしまう可能性があります。

作者が使っている分は今のところ外れたことがありませんが、外れた場合は再度圧入するか、接着剤を付けた上で圧入してください。

外れた場合は今後の改善のためにご報告いただけると幸いです。

:::

## 別途購入が必要な部品

キット以外に、以下の部品をご自身で準備していただく必要があります。

### 片側トラックボールの場合

1. XIAO nrf52840 x2
   - 姉妹品の XIAO nrf52840 plus は使用できません。
   - 姉妹品の XIAO nrf52840 Sense は利用できる可能性がありますが、動作未検証です。
1. Kailh Choc v2 ロープロファイルキースイッチ 43 個
   - Kailh Lofree Low-profile POM 系のピンが２ピンのものが使えます
   - ３ピンのものはピンを切れば使えるかも？持ってないのでわかりません
   - トッププレートの厚みは 2.0mm です
   - Deep sea silent mini, Lofree Ghost, Kailh White Rain Switch ではいい感じに使えました
1. ロープロファイル向けキーキャップ一式
   - 1U 39 個
   - 1.5U 2 個
   - 1.25U 2 個 (1U でも一応 OK)
   - [YMDK 116](https://ja.aliexpress.com/item/1005006981216357.html) と [THT low profile](https://talpkeyboard.net/items/66795277401c310b1f80e83f)(1.25U は存在しない)が使えることは確認しています
1. 25mm トラックボール用ボール
   - [エレコムの赤いボール](https://www.amazon.co.jp/%E3%82%A8%E3%83%AC%E3%82%B3%E3%83%A0-%E3%83%88%E3%83%A9%E3%83%83%E3%82%AF%E3%83%9C%E3%83%BC%E3%83%AB%E7%94%A8%E4%BA%A4%E6%8F%9B%E3%83%9C%E3%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)がおすすめです。
   - [ペリックスの深い赤](https://www.amazon.co.jp/Perixx-%E3%83%9A%E3%83%AA%E3%83%83%E3%82%AF%E3%82%B9-PERIPRO-305GRD-%E4%BA%A4%E6%8F%9B%E7%94%A8%E3%83%88%E3%83%A9%E3%83%83%E3%82%AF%E3%83%9C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)~~は感度が悪く微妙でした。（ケース設計の問題かも）~~ -> 2025/08/10 以降発送分から改良されました
   - ~~X にいる染色職人の方々が作っているボールでも使えるはずですが、色によって感度が変わります~~
   - ~~試したところこちらも感度が悪く動作しないようです。そのためエレコムの赤玉をお勧めします。現在改良可能か実験中です。~~
   - 2025/08/10 以降発送分からエレコム赤玉と染色された POM 球両方に対応できるように改良しました。
   - フロストアクリル球（紫）でも動作しました
1. 単４電池 x2
   - ファームウェアのバッテリー残量表示はニッケル水素電池向けに調整されています
   - アルカリ乾電池等も使えるはずですが、残量表示が実際の残量と対応しないと思います。今後ファームウェアアップデートで対応できるようにするつもりです。
1. USB ケーブル
   - データ通信に対応した Type C ケーブル（PC 接続用、ファームウェア書き込み用）
   - （現在のファームウェアでは未対応/未検証）データ通信に対応した Type C to C ケーブル（左右接続用）
1. FFC をケースに固定するための適当なテープ
1. (オプション)磁石をケースに固定するための適当な接着剤
   - 作者は接着剤無しで使用していますが、組み立て時に磁石がホルダーから外れてしまうと回路がショートする可能性があります。
   - 接着剤でケースに固定してしまう方が安全です。

:::tip[キースイッチの選び方]

- 現在のケースは打鍵感を十分に考慮した設計にはなっていないため、Lofree 系のリニアスイッチはポテンシャルが活かせていない気がしています。
- 外出先での使用も考慮して Deep sea silent mini のようなサイレント系スイッチを使用するのが良いと思います。

:::

:::tip[キーキャップの種類]

- ロープロファイル対応でないキーキャップを使用すると、トッププレートと干渉してキーを最後まで押し込めないことがあります。
- トラックボールの真横のキーキャップは親指と干渉しやすいため、この部分だけ狭ピッチ向けの小さめのキーキャップを使用すると快適です。
  - 作者は [Kotori](https://shakupan.booth.pm/items/6781056) と思われるコンベックスキーを使っています。（別商品を買ったおまけにいただいたもののため正体不明）
  - [Junana MX 1U 凸形](https://decentkeyboards.booth.pm/items/5551877)も良さそうですが未検証です

:::

### 両側トラックボールの場合

- キースイッチが 41 個（−2 個）になります
- キーキャップは 1.25U が不要になります
- **PMW3610 センサーが追加で１つ必要です**
  - 別料金で同梱可能です。ご相談ください。

## 必要な工具

- はんだ、はんだごて
  - 温度調整機能付きのハンダゴテがおすすめです
  - [C 型のコテ先](https://lang-ship.com/blog/work/900m/#toc19)をおすすめしておきます
- はんだ吸い取り線
  - 失敗した時のリカバリーに非常に役立ちます。
  - 特に、XIAO nRF52840 の背面パッドがブリッジした場合のリカバリーには必須です。
- ニッパー
- ピンセット or 先の細いペンチのようなもの
  - 表面実装のスイッチを取り付けるときに必要です。
- プラスドライバー（0 番と 1 番サイズ）
  - 商品には複数種類の M2 ネジが付属しています
  - 少しネジ穴の大きい方（e.g. タッチセンサー用ネジ）には 1 番サイズが適合します
  - ネジ穴の小さい方には 0 番サイズが必要です
  - ケースネジは配布時期によって対応するドライバーのサイズが違う場合があります。 タッチセンサー用ネジ以外は 0 番サイズの場合が多いです
  - 参考に、作者は[こちらの電動精密ドライバー](https://www.amazon.co.jp/dp/B0F1T7MWZJ)を使用しています

## Q&A

- Q: 組み立て時にパーツが壊れてしまったり、パーツを無くしてしまった場合はどうすれば良いですか？
  - 購入したサイトのメッセージ機能でご相談ください。状況を確認の上、保守部品の販売等の対応をいたします。
- Q: 3D プリントケースに傷や色の違う部分がありますが不良ですか？
  - 基本的には仕様となりますが、気になる場合はお問い合わせください。
  - 特に、黒ケースはプリント底面に前の印刷の跡や擦ったような跡が付いていることがありますがこちらも仕様となります。
    - ヒートガンやライターで熱を加えると消える場合が多いです。ケースは熱で溶けるため細心の注意が必要ですが、3D プリント品にお詳しい方は自己責任でお試しください。
    - 商品はヒートガンで処理した上で一定以上の品質のもののみを選別するようにはしています。
  - ケースの薄い部分は 3D プリント性質の関係でキズのように見える段差等ができている部分があります。こちらも仕様となりますが、強度不足で破損した場合等はご連絡ください。
- Q: 組み立ての一部のステップがうまくできません
  - 購入したサイトのメッセージ機能でご相談いただければコツなどをアドバイスいたします。
  - どうしてもうまくいかない場合でも、状況に応じて可能な範囲で柔軟に対応策をご提案いたしますので一度ご相談ください。ただし、対応できる内容は時期や状況によって毎回変わることがありますのでご了承ください。
- Q: 組み立ての代行はしていますか？
  - していません。トラブル対応の負担を軽減するために、自らはんだ付けや組み立てをする時間と技術力がある方を主な対象として販売しています。
  - 他の方が行っている組み立ての代行サービスに組み立てを依頼することは明確には禁止はしていませんが、代行によるトラブルが多い場合やサポートに難しさを感じる場合は通常よりもサポート品質を下げる場合がありますのでご了承ください。

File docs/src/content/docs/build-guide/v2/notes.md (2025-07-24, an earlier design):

---
title: 補足
description: さまざまな補足
sidebar:
  order: 999
---

## 電池端子の曲げ加工がされていない場合

電池のマイナス端子パーツは、通常以下の画像のように上下両方が曲がった状態で同梱しています。

梱包時の不手際により半田付けしない側を曲げ忘れたまま同梱したロットがあるため、曲がっていない場合の対応方法を解説します。

なお、プラス端子は片側のみ曲がっているのが正しい状態です。マイナス端子のように追加で曲げてもらう必要はありません。

| | | | |
| --- | --- | --- | --- |
|  |  |  |  |

### まだ半田付けしていない場合

以下の図のようにバネギリギリの部分を先の細いラジオペンチで曲げてください。

曲げる際は一度で曲げ切ってください。曲げ具合が甘い時に一度元に戻してしまうと金属疲労で端子が折れてバネが外れてしまいます。

端子が折れたり、うまくいかなかった場合は交換対応しますのでご連絡ください。

| 1. バネを下に寄せる | | 2.バネギリギリの位置で曲げる | |
| --- | --- | --- | --- |
|  |  |  |  |

### 半田付けした場合

お手持ちのペンチの形状によりますが、はんだ付けしたままでは安定して曲げるのが難しいため一度パーツを外してもらう必要があります。

図のように基板をペンチ等で少し浮かせた状態で表側から端子のはんだ付けした部分にはんだごてを当ててもらうと重力で外れると思います。



無理に力を入れて引っ張ると基板の金属パッドが剥がれる可能性があるのでご注意ください。

加熱中はパーツが非常に暑くなるので直接手で触れないようにご注意ください。

取り外せたら、**パーツが冷めるのを待ってから**、半田付けしていない場合と同様に曲げてください。

再度つける際はパーツを指す穴が半田で埋まっているかもしれません。はんだ吸い取り線をお持ちの場合は吸い取り線で除去してください。

吸い取り線が無い場合は少し高度な技術が必要ですが、穴を埋めているハンダをハンダゴテで溶かしながら、ペンチで挟んだマイナス端子を差し込むと取り付けられます。

仮取り付け後に、付属の治具で高さを合わせるとケースに干渉なく取り付けられます。

### 作業が不安な場合・うまくいかなかった場合

上記の作業が難しいと感じる場合は、適切に加工した端子をお送りしますので購入したプラットフォームからご相談ください。

また、うまくいかなかった場合やこの作業に伴って基板が破損したと思われる場合は交換対応等できる限り手厚くサポートしますのでご連絡ください。

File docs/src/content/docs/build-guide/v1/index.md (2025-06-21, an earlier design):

---
title: Build Guide V1
description: DYA Dash build guide
---

2025/05 に配布した試作版の余り基板のビルドガイドです。
最新版と少し違う部分があります。

[ガイドはこちらを見てください](https://github.com/cormoran/dya-dash-keyboard/blob/main/hardware/dya-dash/build-guide/v1/BuildGuide.md)

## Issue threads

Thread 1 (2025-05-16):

試作から改善すべき点

cormoran, 2025-05-16:
- [ ] 電源スイッチを >500mA 対応の表面実装に変更
- [ ] LED と設定ボタンの位置を入れ替え
- [ ] トッププレートの電源カバー強度改良
- [ ] トッププレートとボトムプレートの隙間問題改良
- [ ] 電源端子の PCB 改良（半田付けしやすい & 位置調整しやすいように）
- [ ] 左右接続用 USB の位置を内側にしたい（容易ではない）
- [ ] 裏面磁石を強くする
  - 数を増やす？大きい磁石を採用？
- [ ] ネジにインサートナット適用
- [ ] やばそうなアイコン消す
- [ ] ライセンス周り再チェック

cormoran, 2025-06-21:
V2.0

- [ ] FFC をめっちゃ曲げないといけない部分、壊す人が続出しそうなのでなんとかしたい
- [ ] 打鍵感を上げる

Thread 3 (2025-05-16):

zmk module を別レポジトリに分離

cormoran, 2025-05-16:
- [ ] zmk-driver-animation
- [ ] zmk-driver-ext-power-transient
- [ ] zmk-driver-led-stripnize

cormoran, 2025-05-17:
https://github.com/cormoran/zmk-config-dya-dash-template

Closed 2025-05-17.

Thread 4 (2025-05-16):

USB 電源時になぜ PMW3610 が動くのか調査 &  polling で使うようにドライバ修正

cormoran, 2025-05-16:
DYA Dash は USB 電源時に MOTION ピンが切断されて左右通信に使えるようになるはずの回路設計になっているが、今は常に MOTION ピン割り込みで動いている。
USB 電源時もトラックボールが動いているが、なぜ動いているのか謎。本来は動かなくなるはず。

- [ ] 何が起こっているか調査する
- [ ] USB 電源時には periodic polling するようにドライバを改造する

cormoran, 2025-05-25:
実験: input pin を pull-down にすると USB 電源供給時に input は常に low になった (motion -> input pin 方向は遮断できている)

考察:
- input pin を pull-up していると FET off でも input pin -> motion 方向は寄生ダイオードで接続されるので、MOTION が low になった時 input pin も low になる
- マイコン内部の pull-up 抵抗は 10kΩ よりは大きいので、pin 電圧は 1/11 とか（寄生ダイオードによる電圧降下分で0.6Vくらい上がる）になって low 判定になる→ pull-up しておけば USB 電源供給時でも MOTION pin 割り込みで動く
- LR_COM 側から 3.3V 入れた場合、3.3V-MOTION 電圧が、1kΩx2 と (電圧降下0.6V + 1kΩ) に分圧されて電圧が input に入る
  - MOTION LOW なら 約 1.567V らしい (By chat GPT, 正しそう)
  - これは low なので LR_COM 通信は動かない...

修正方針:
- LR_COM 側の抵抗値を減らす or MOTION 側の抵抗値を増やせば MOTION LOW による電圧降下を無効化できそう
- LR_COM 側の抵抗を 100Ω (x2) にすると良さそうだが、ミスってOUTPUT 同士で繋ぐと 16.5mA 流れる
  -  ミスる: 左右が同時に OUTPUT にして HIGH - LOW になる状態
  - nRF52840 だとハイドライブにすると 15mA 流せて、標準だと 0.5mA しか流せない (by ChatGPT)
  - 標準ドライブで大電流流そうとしても短期的なら壊れないらしい（本当か？）ので200Ωでも良さそう？
  - 抵抗を 2kΩ にしたところで 1.65mA > 0.5mA
- Or MOTION 側の抵抗を 10kΩ とかにして、マイコン側で pull-up/down しないようにする？
  - こっちの方が安全そうな雰囲気
  - MOTION はそんなに早くないので遅延も許せそう

左右の通信速度を 1MHz とかにしたい場合は 100Ω くらいまでが推奨らしい (by Chat GPT)

100Ωにしておくか

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

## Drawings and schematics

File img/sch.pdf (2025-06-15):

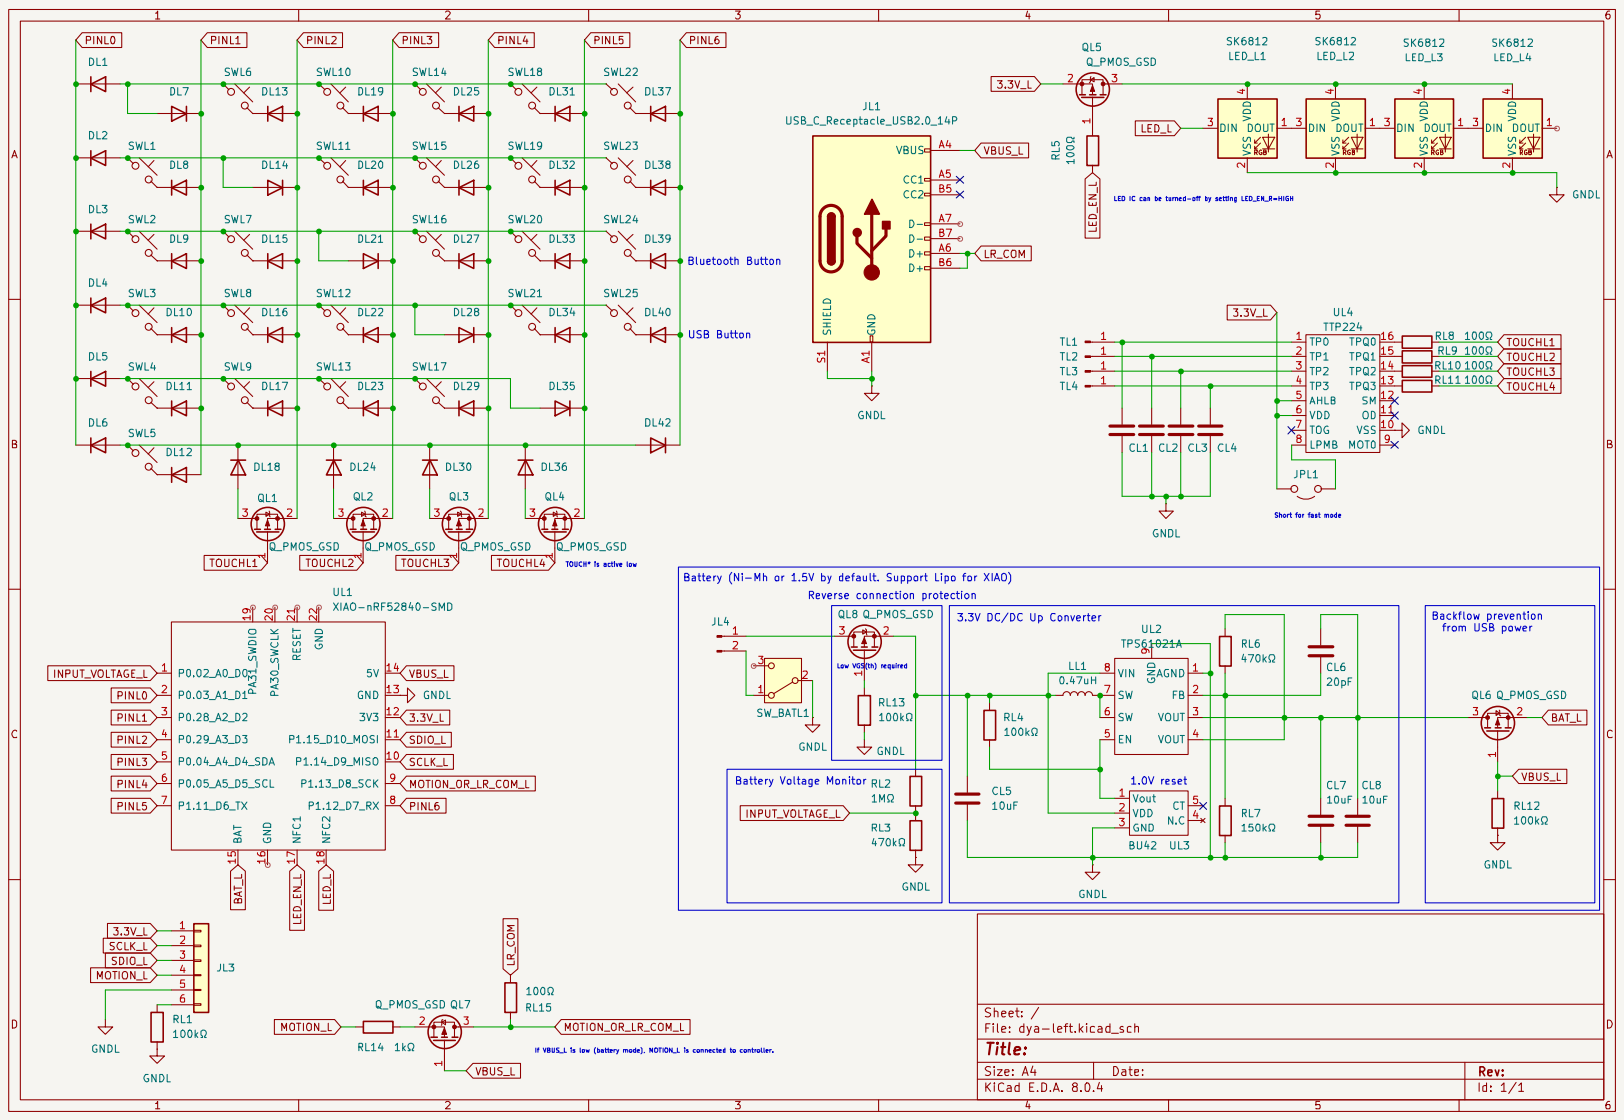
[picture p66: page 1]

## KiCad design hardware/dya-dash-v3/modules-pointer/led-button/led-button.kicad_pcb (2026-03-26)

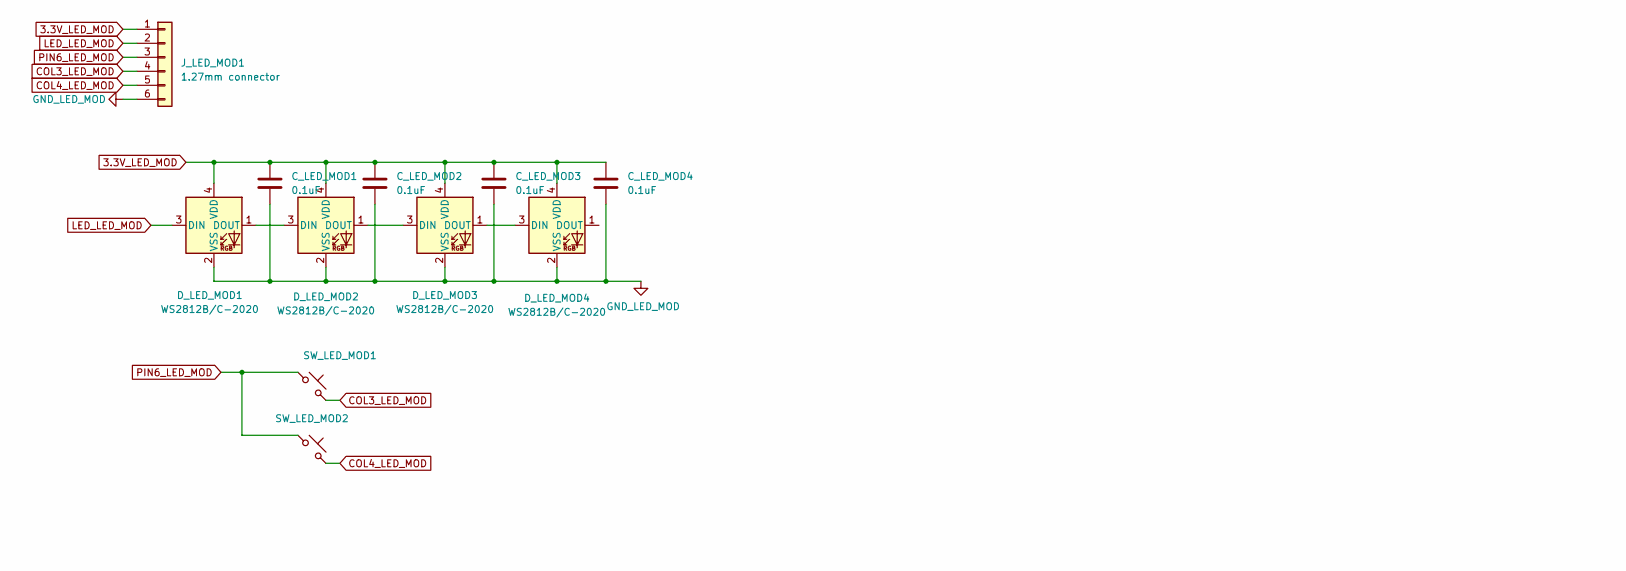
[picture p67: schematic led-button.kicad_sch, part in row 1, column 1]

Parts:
C_LED_MOD1, C_LED_MOD2, C_LED_MOD3, C_LED_MOD4: 0.1uF; C_0402_1005Metric; LCSC C1525
D_LED_MOD1, D_LED_MOD2, D_LED_MOD3, D_LED_MOD4: WS2812B/C-2020; LED_WS2812B-2020_PLCC4_2.0x2.0mm; LCSC C2976072
J_LED_MOD1: 1.27mm connector; PinHeader_1x06_P1.27mm_Vertical
SW_LED_MOD1, SW_LED_MOD2: SW_Push; SW_PUSH_1P1T_6x3.5mm_H4.3_APEM_MJTP1243

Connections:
3.3V_LED_MOD: C_LED_MOD1.1, C_LED_MOD2.1, C_LED_MOD3.1, C_LED_MOD4.1, D_LED_MOD1.4 (VDD), D_LED_MOD2.4 (VDD), D_LED_MOD3.4 (VDD), D_LED_MOD4.4 (VDD), J_LED_MOD1.1
COL3_LED_MOD: J_LED_MOD1.4, SW_LED_MOD1.2
COL4_LED_MOD: J_LED_MOD1.5, SW_LED_MOD2.2
GND_LED_MOD: C_LED_MOD1.2, C_LED_MOD2.2, C_LED_MOD3.2, C_LED_MOD4.2, D_LED_MOD1.2 (VSS), D_LED_MOD2.2 (VSS), D_LED_MOD3.2 (VSS), D_LED_MOD4.2 (VSS), J_LED_MOD1.6
LED_LED_MOD: D_LED_MOD1.3 (DIN), J_LED_MOD1.2
unnamed: D_LED_MOD1.1 (DOUT), D_LED_MOD2.3 (DIN)
unnamed: D_LED_MOD2.1 (DOUT), D_LED_MOD3.3 (DIN)
unnamed: D_LED_MOD3.1 (DOUT), D_LED_MOD4.3 (DIN)
PIN6_LED_MOD: J_LED_MOD1.3, SW_LED_MOD1.1, SW_LED_MOD2.1

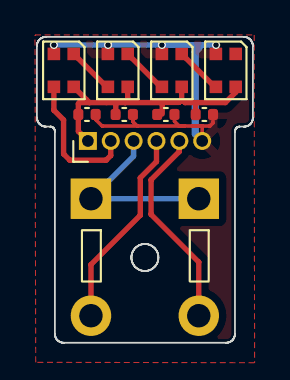
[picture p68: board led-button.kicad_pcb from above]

Board: 2 copper layers, 12.0 x 17.0 mm, 11 parts (0 on the bottom side), 9 nets.

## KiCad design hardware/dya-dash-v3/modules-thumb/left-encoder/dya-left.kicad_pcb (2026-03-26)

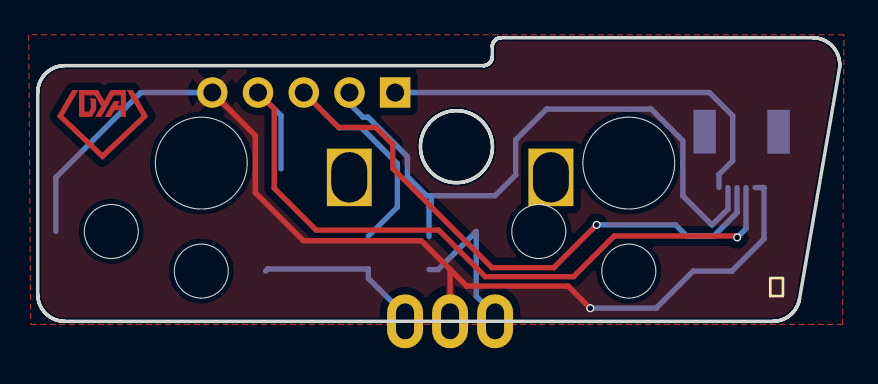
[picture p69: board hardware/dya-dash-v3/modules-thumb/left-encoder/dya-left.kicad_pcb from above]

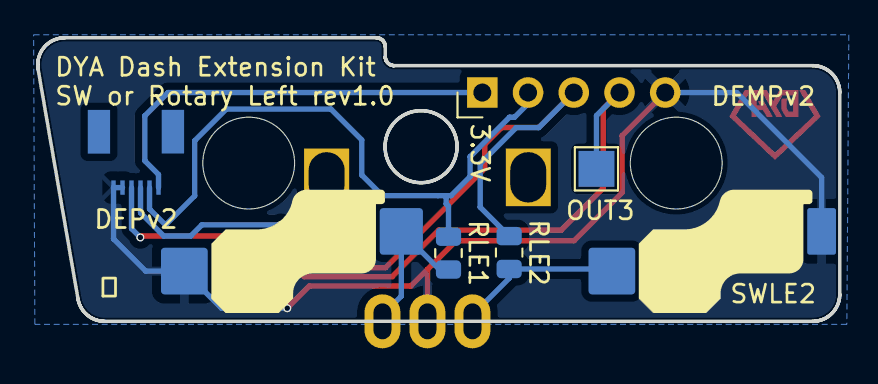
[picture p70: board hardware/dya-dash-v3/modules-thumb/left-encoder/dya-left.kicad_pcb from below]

Board: 2 copper layers, 44.6 x 15.8 mm, 8 parts (7 on the bottom side), 7 nets.

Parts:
JLE1: FFC; JUSHUO-AFH34-S06FIA-1H
JLE2: Magnet Connector; PinHeader_1x05_P2.54mm_Vertical
JLE3: Conn_01x01_Socket; TestPoint_Pad_2.0x2.0mm
RLE1, RLE2: 330Ω; R_0805_2012Metric
SWELE1: RotaryEncoder_Switch; RotaryEncoder_EC12E
SWLE1, SWLE2: SW_Push_45deg; Kailh-PG1353-Hotswap-1U

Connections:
3.3V_L: JLE1.1, JLE2.1
ENC1_LE: RLE1.2, SWELE1.B, SWLE1.1
ENC2_LE: RLE2.2, SWELE1.A, SWLE2.2
GNDLE: JLE1.5, JLE1.6, JLE2.5, SWELE1.C, SWLE1.2, SWLE2.1
OUT1: JLE1.2, JLE2.2, RLE1.1
OUT2: JLE1.3, JLE2.3, RLE2.1
OUT3: JLE1.4, JLE2.4, JLE3.1

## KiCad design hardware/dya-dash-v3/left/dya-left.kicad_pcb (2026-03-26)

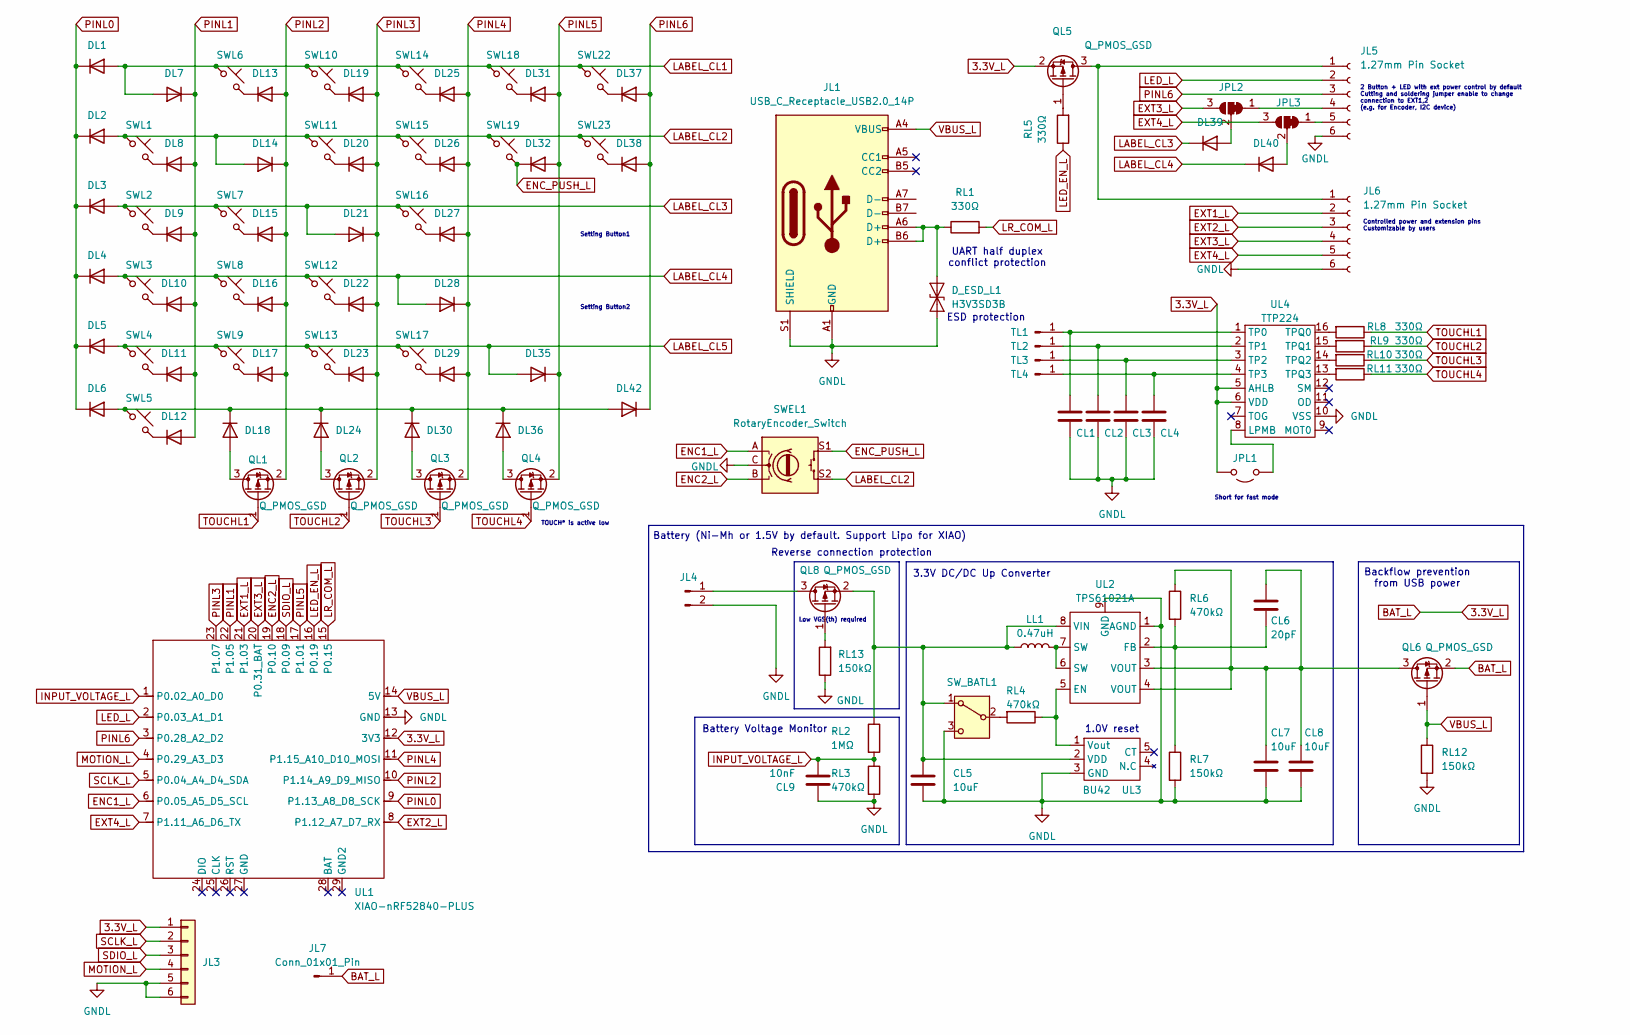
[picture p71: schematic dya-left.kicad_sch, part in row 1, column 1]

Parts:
CL1, CL2, CL3, CL4: C_0805_2012Metric
CL5, CL7, CL8: 10uF; C_0805_2012Metric; LCSC C15850
CL6: 20pF; C_0805_2012Metric; LCSC C1798
CL9: 10nF; C_0805_2012Metric
DL1, DL2, DL3, DL4, DL5, DL6, DL7, DL8, DL9, DL10, DL11, DL12, DL13, DL14, DL15, DL16, DL17, DL18, DL19, DL20, DL21, DL22, DL23, DL24, DL25, DL26, DL27, DL28, DL29, DL30, DL31, DL32, DL35, DL36, DL37, DL38, DL39, DL40, DL42: D; D_SOD-123; LCSC C81598
D_ESD_L1: H3V3SD3B; D_SOD-323; LCSC C20615802
JL1: USB_C_Receptacle_USB2.0_14P; USB_C_ Recessed_ YTC-TC16-31_1.2mm; LCSC C2927296
JL3: Conn_01x04; JUSHUO-AFH34-S06FIA-1H; LCSC C224194
JL4: Conn_01x02_Pin; AAA-battery
JL5, JL6: 1.27mm Pin Socket; PinHeader_1x06_P1.27mm_Vertical
JL7: Conn_01x01_Pin; TestPoint_Pad_1.5x1.5mm
JPL1: Jumper_2_Open; SolderJumper-2_P1.3mm_Open_RoundedPad1.0x1.5mm
JPL2, JPL3: SolderJumper_3_Bridged12; SolderJumper-3_P1.3mm_Bridged12_RoundedPad1.0x1.5mm
LL1: 0.47uH; L_1008_2520Metric; LCSC C519277
QL1, QL2, QL3, QL4, QL5, QL6: Q_PMOS_GSD; SOT-23; LCSC C15127
QL8: Q_PMOS_GSD; SOT-23; LCSC C144153
RL1, RL5, RL8, RL9, RL10, RL11: 330Ω; R_0805_2012Metric; LCSC C17630
RL2: 1MΩ; R_0805_2012Metric; LCSC C17514
RL3, RL4, RL6: 470kΩ; R_0805_2012Metric; LCSC C17709
RL7, RL12, RL13: 150kΩ; R_0805_2012Metric; LCSC C17470
SWEL1: RotaryEncoder_Switch; RotaryEncoder_Alps_EC12E-Switch_Vertical_H20mm
SWL1, SWL2, SWL3, SWL4, SWL5, SWL6, SWL7, SWL8, SWL9, SWL10, SWL11, SWL12, SWL13, SWL14, SWL15, SWL16, SWL17, SWL18, SWL19, SWL22, SWL23: SW_Push_45deg; Kailh-PG1353-Hotswap-1U; LCSC C5333465
SW_BATL1: SW_SPDT; SSSS811101; LCSC C109335
TL1, TL2, TL3, TL4: Conn_01x01_Pin; MountingHole_2.2mm_M2_Pad
UL1: XIAO-nRF52840-PLUS; XIAO_nRF52840_plus
UL2: TPS61021A; WSON-8-1EP_2x2mm_P0.5mm_EP0.9x1.6mm; LCSC C193037
UL3: BU42; BU42XX; LCSC C2066584
UL4: TTP224; SSOP-16_3.9x4.9mm_P0.635mm; LCSC C2890350

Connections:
3.3V_L: JL3.1, JL7.1, JPL1.2 (B), QL5.2 (S), QL6.2 (S), UL1.12 (3V3), UL4.5 (AHLB), UL4.6 (VDD)
ENC1_L: SWEL1.A, UL1.6 (P0.05_A5_D5_SCL)
ENC2_L: SWEL1.B, UL1.19 (P0.10)
ENC_PUSH_L: DL32.1 (K), SWEL1.S1, SWL19.2
EXT1_L: JL6.2, UL1.21 (P1.03)
EXT2_L: JL6.3, UL1.8 (P1.12_A7_D7_RX)
EXT3_L: JL6.4, JPL2.3 (B), UL1.20 (P0.31_BAT)
EXT4_L: JL6.5, JPL3.3 (B), UL1.7 (P1.11_A6_D6_TX)
GNDL: CL1.2, CL2.2, CL3.2, CL4.2, CL5.2, CL7.2, CL8.2, CL9.1, D_ESD_L1.2 (A2), JL1.A1 (GND), JL1.A12 (GND), JL1.B1 (GND), JL1.B12 (GND), JL1.S1 (SHIELD), JL3.5, JL3.6, JL4.2, JL5.6, JL6.6, RL3.2, RL7.2, RL12.2, RL13.1, SWEL1.C, SW_BATL1.3 (C), UL1.13 (GND), UL2.1 (AGND), UL2.9 (GND), UL3.3 (GND), UL4.10 (VSS)
INPUT_VOLTAGE_L: CL9.2, RL2.2, RL3.1, UL1.1 (P0.02_A0_D0)
LABEL_CL1: DL1.2 (A), DL7.2 (A), SWL6.1, SWL10.1, SWL14.1, SWL18.1, SWL22.1
LABEL_CL2: DL2.2 (A), DL14.2 (A), SWEL1.S2, SWL1.1, SWL11.1, SWL15.1, SWL19.1, SWL23.1
LABEL_CL3: DL3.2 (A), DL21.2 (A), DL39.1 (K), SWL2.1, SWL7.1, SWL16.1
LABEL_CL4: DL4.2 (A), DL28.2 (A), DL40.1 (K), SWL3.1, SWL8.1, SWL12.1
LABEL_CL5: DL5.2 (A), DL35.2 (A), SWL4.1, SWL9.1, SWL13.1, SWL17.1
LED_EN_L: RL5.1, UL1.16 (P0.19)
LED_L: JL5.2, UL1.2 (P0.03_A1_D1)
LR_COM_L: RL1.2, UL1.15 (P0.15)
MOTION_L: JL3.4, UL1.4 (P0.29_A3_D3)
unnamed: DL8.1 (K), SWL1.2
unnamed: DL9.1 (K), SWL2.2
unnamed: DL10.1 (K), SWL3.2
unnamed: DL11.1 (K), SWL4.2
unnamed: DL12.1 (K), SWL5.2
unnamed: DL13.1 (K), SWL6.2
unnamed: DL15.1 (K), SWL7.2
unnamed: DL16.1 (K), SWL8.2
unnamed: DL17.1 (K), SWL9.2
unnamed: DL18.2 (A), QL1.3 (D)
unnamed: DL6.2 (A), DL18.1 (K), DL24.1 (K), DL30.1 (K), DL36.1 (K), DL42.2 (A), SWL5.1
unnamed: DL19.1 (K), SWL10.2
unnamed: DL20.1 (K), SWL11.2
unnamed: DL22.1 (K), SWL12.2
unnamed: DL23.1 (K), SWL13.2
unnamed: DL24.2 (A), QL2.3 (D)
unnamed: DL25.1 (K), SWL14.2
unnamed: DL26.1 (K), SWL15.2
unnamed: DL27.1 (K), SWL16.2
unnamed: DL29.1 (K), SWL17.2
unnamed: DL30.2 (A), QL3.3 (D)
unnamed: DL31.1 (K), SWL18.2
unnamed: DL36.2 (A), QL4.3 (D)
unnamed: DL37.1 (K), SWL22.2
unnamed: DL38.1 (K), SWL23.2
unnamed: DL39.2 (A), JPL2.2 (C)
unnamed: DL40.2 (A), JPL3.2 (C)
unnamed: D_ESD_L1.1 (A1), JL1.A6 (D+), JL1.B6 (D+), RL1.1
unnamed: JL4.1, QL8.3 (D)
unnamed: JL5.1, JL6.1, QL5.3 (D)
unnamed: JL5.4, JPL2.1 (A)
unnamed: JL5.5, JPL3.1 (A)
unnamed: JPL1.1 (A), UL4.8 (LPMB)
unnamed: LL1.2, UL2.6 (SW), UL2.7 (SW)
unnamed: QL5.1 (G), RL5.2
unnamed: CL6.1, CL7.1, CL8.1, QL6.3 (D), RL6.1, UL2.3 (VOUT), UL2.4 (VOUT)
unnamed: QL8.1 (G), RL13.2
unnamed: CL5.1, LL1.1, QL8.2 (S), RL2.1, SW_BATL1.1 (A), UL2.8 (VIN), UL3.2 (VDD)
unnamed: RL4.2, SW_BATL1.2 (B)
unnamed: CL1.1, TL1.1, UL4.1 (TP0)
unnamed: CL2.1, TL2.1, UL4.2 (TP1)
unnamed: CL3.1, TL3.1, UL4.3 (TP2)
unnamed: CL4.1, TL4.1, UL4.4 (TP3)
unnamed: RL4.1, UL2.5 (EN), UL3.1 (Vout)
unnamed: CL6.2, RL6.2, RL7.1, UL2.2 (FB)
unnamed: RL8.2, UL4.16 (TPQ0)
unnamed: RL9.2, UL4.15 (TPQ1)
unnamed: RL10.2, UL4.14 (TPQ2)
unnamed: RL11.2, UL4.13 (TPQ3)
PINL0: DL1.1 (K), DL2.1 (K), DL3.1 (K), DL4.1 (K), DL5.1 (K), DL6.1 (K), UL1.9 (P1.13_A8_D8_SCK)
PINL1: DL7.1 (K), DL8.2 (A), DL9.2 (A), DL10.2 (A), DL11.2 (A), DL12.2 (A), UL1.22 (P1.05)
PINL2: DL13.2 (A), DL14.1 (K), DL15.2 (A), DL16.2 (A), DL17.2 (A), QL1.2 (S), UL1.10 (P1.14_A9_D9_MISO)
PINL3: DL19.2 (A), DL20.2 (A), DL21.1 (K), DL22.2 (A), DL23.2 (A), QL2.2 (S), UL1.23 (P1.07)
PINL4: DL25.2 (A), DL26.2 (A), DL27.2 (A), DL28.1 (K), DL29.2 (A), QL3.2 (S), UL1.11 (P1.15_A10_D10_MOSI)
PINL5: DL31.2 (A), DL32.2 (A), DL35.1 (K), QL4.2 (S), UL1.17 (P1.01)
PINL6: DL37.2 (A), DL38.2 (A), DL42.1 (K), JL5.3, UL1.3 (P0.28_A2_D2)
SCLK_L: JL3.2, UL1.5 (P0.04_A4_D4_SDA)
SDIO_L: JL3.3, UL1.18 (P0.09)
TOUCHL1: QL1.1 (G), RL8.1
TOUCHL2: QL2.1 (G), RL9.1
TOUCHL3: QL3.1 (G), RL10.1
TOUCHL4: QL4.1 (G), RL11.1
VBUS_L: JL1.A4 (VBUS), JL1.A9 (VBUS), JL1.B4 (VBUS), JL1.B9 (VBUS), QL6.1 (G), RL12.1, UL1.14 (5V)

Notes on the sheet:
Controlled power and extension pins Customizable by users
Low VGS(th) required
Battery (Ni-Mh or 1.5V by default. Support Lipo for XIAO)
1.0V reset
Short for fast mode
TOUCH* is active low
UART half duplex conflict protection
Reverse connection protection
3.3V DC/DC Up Converter
2 Button + LED with ext power control by default Cutting and soldering jumper enable to change connection to EXT1,2 (e.g. for Encoder, I2C device)
ESD protection
Backflow prevention from USB power
Setting Button1
Battery Voltage Monitor
Setting Button2

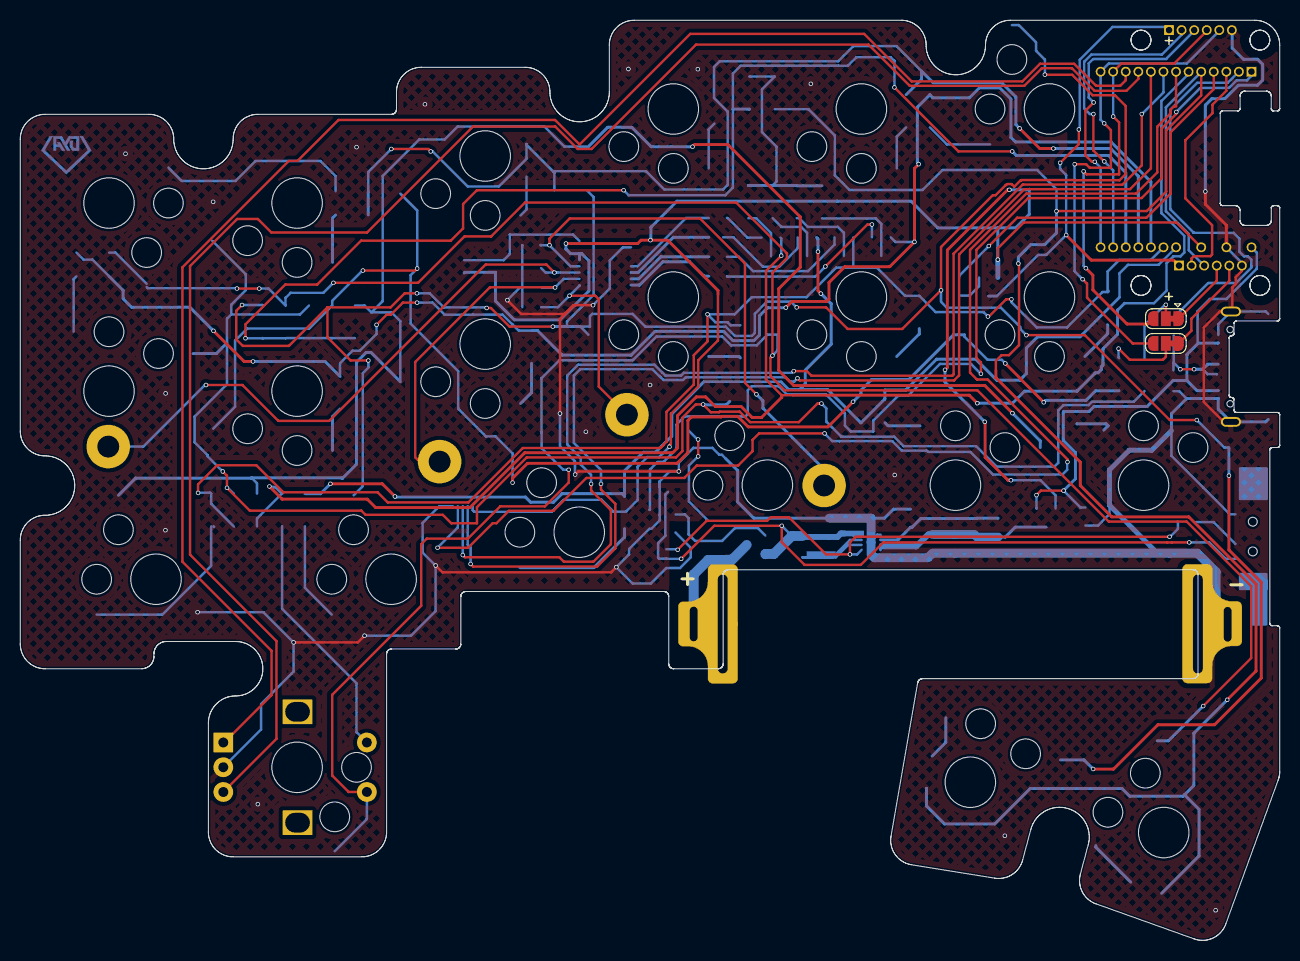
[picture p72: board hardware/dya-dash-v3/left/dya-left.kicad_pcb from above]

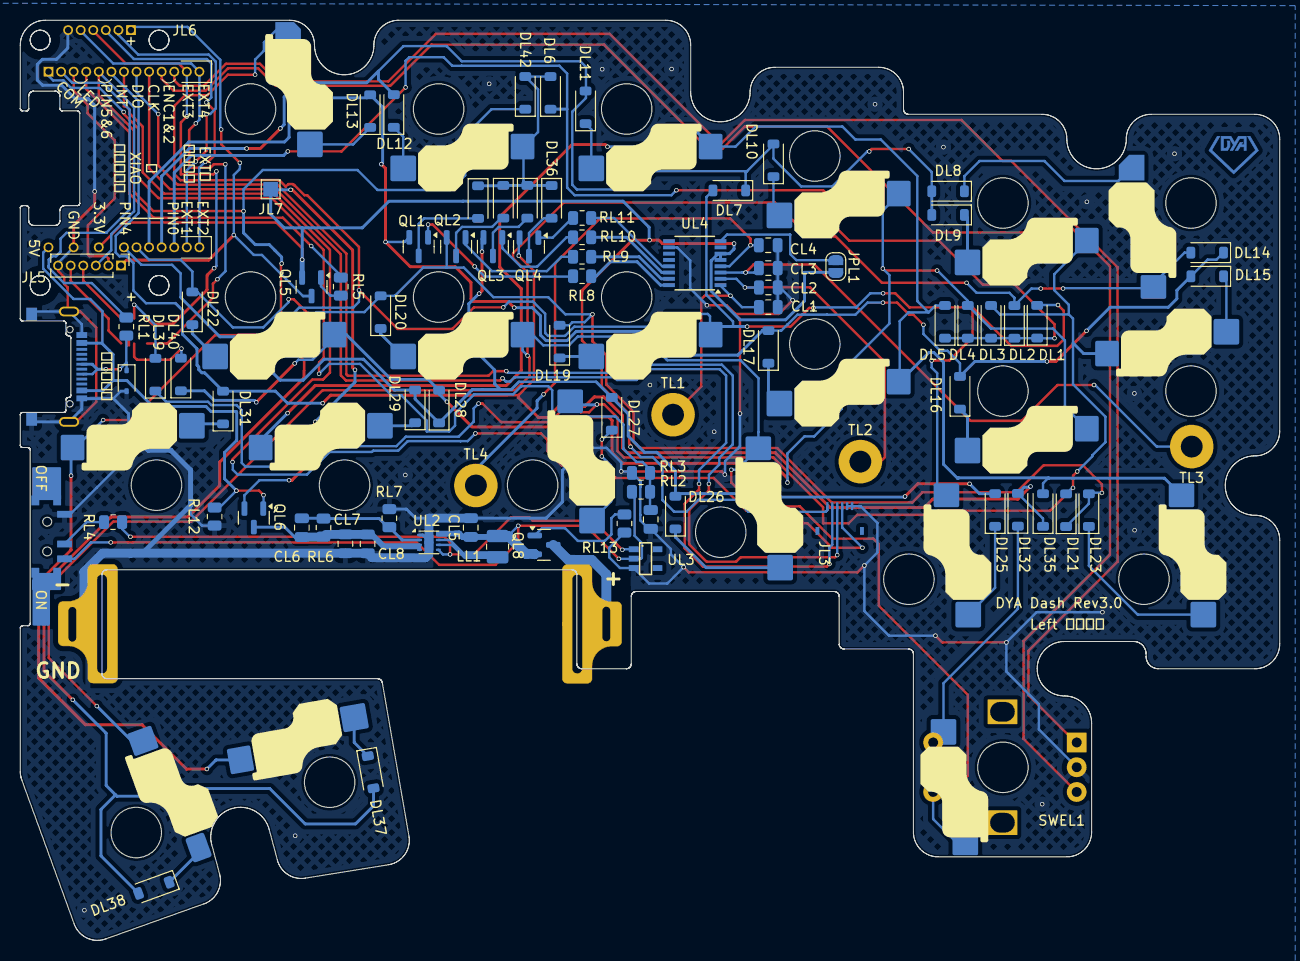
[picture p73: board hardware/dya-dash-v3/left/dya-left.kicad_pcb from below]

Board: 2 copper layers, 127.2 x 92.9 mm, 110 parts (103 on the bottom side), 82 nets.

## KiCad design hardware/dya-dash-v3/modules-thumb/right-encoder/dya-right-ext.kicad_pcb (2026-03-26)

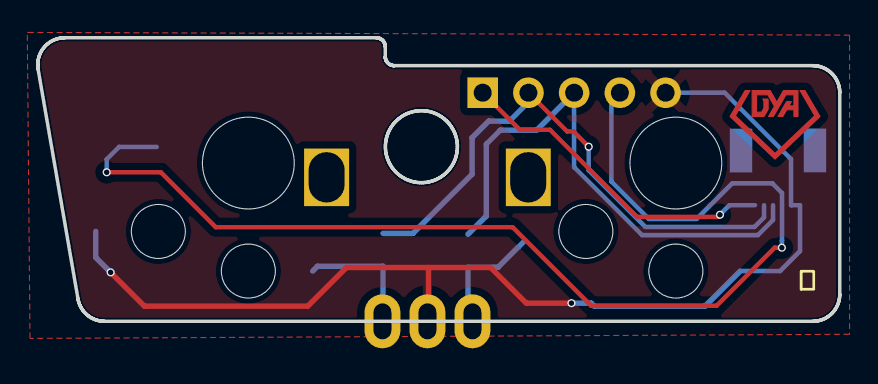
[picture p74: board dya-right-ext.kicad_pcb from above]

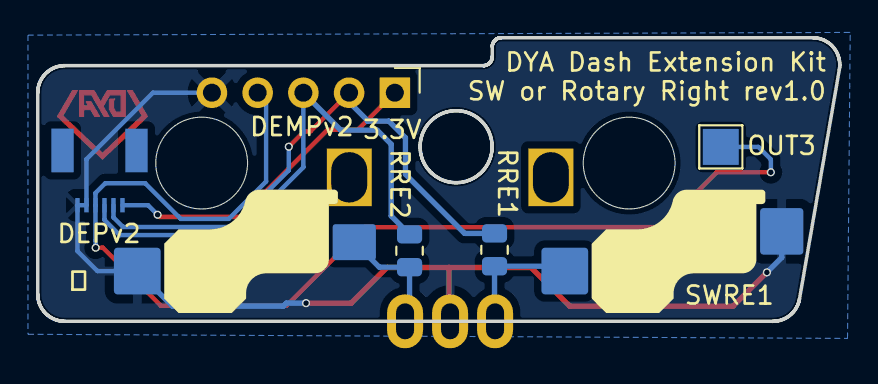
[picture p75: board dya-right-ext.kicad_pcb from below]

Board: 2 copper layers, 44.6 x 15.8 mm, 8 parts (7 on the bottom side), 7 nets.

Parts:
JRE1: FFC; JUSHUO-AFH34-S06FIA-1H
JRE2: Magnet Connector; PinHeader_1x05_P2.54mm_Vertical
JRE3: Conn_01x01_Socket; TestPoint_Pad_2.0x2.0mm
RRE1, RRE2: 330Ω; R_0805_2012Metric
SWERE1: RotaryEncoder_Switch; RotaryEncoder_EC12E
SWRE1, SWRE2: SW_Push_45deg; Kailh-PG1353-Hotswap-1U

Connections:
3.3V_RE: JRE1.1, JRE2.1
ENC1_RE: RRE1.2, SWERE1.A, SWRE1.2
ENC2_RE: RRE2.2, SWERE1.B, SWRE2.1
GNDRE: JRE1.5, JRE1.6, JRE2.5, SWERE1.C, SWRE1.1, SWRE2.2
OUT_RE1: JRE1.2, JRE2.2, RRE1.1
OUT_RE2: JRE1.3, JRE2.3, RRE2.1
OUT_RE3: JRE1.4, JRE2.4, JRE3.1

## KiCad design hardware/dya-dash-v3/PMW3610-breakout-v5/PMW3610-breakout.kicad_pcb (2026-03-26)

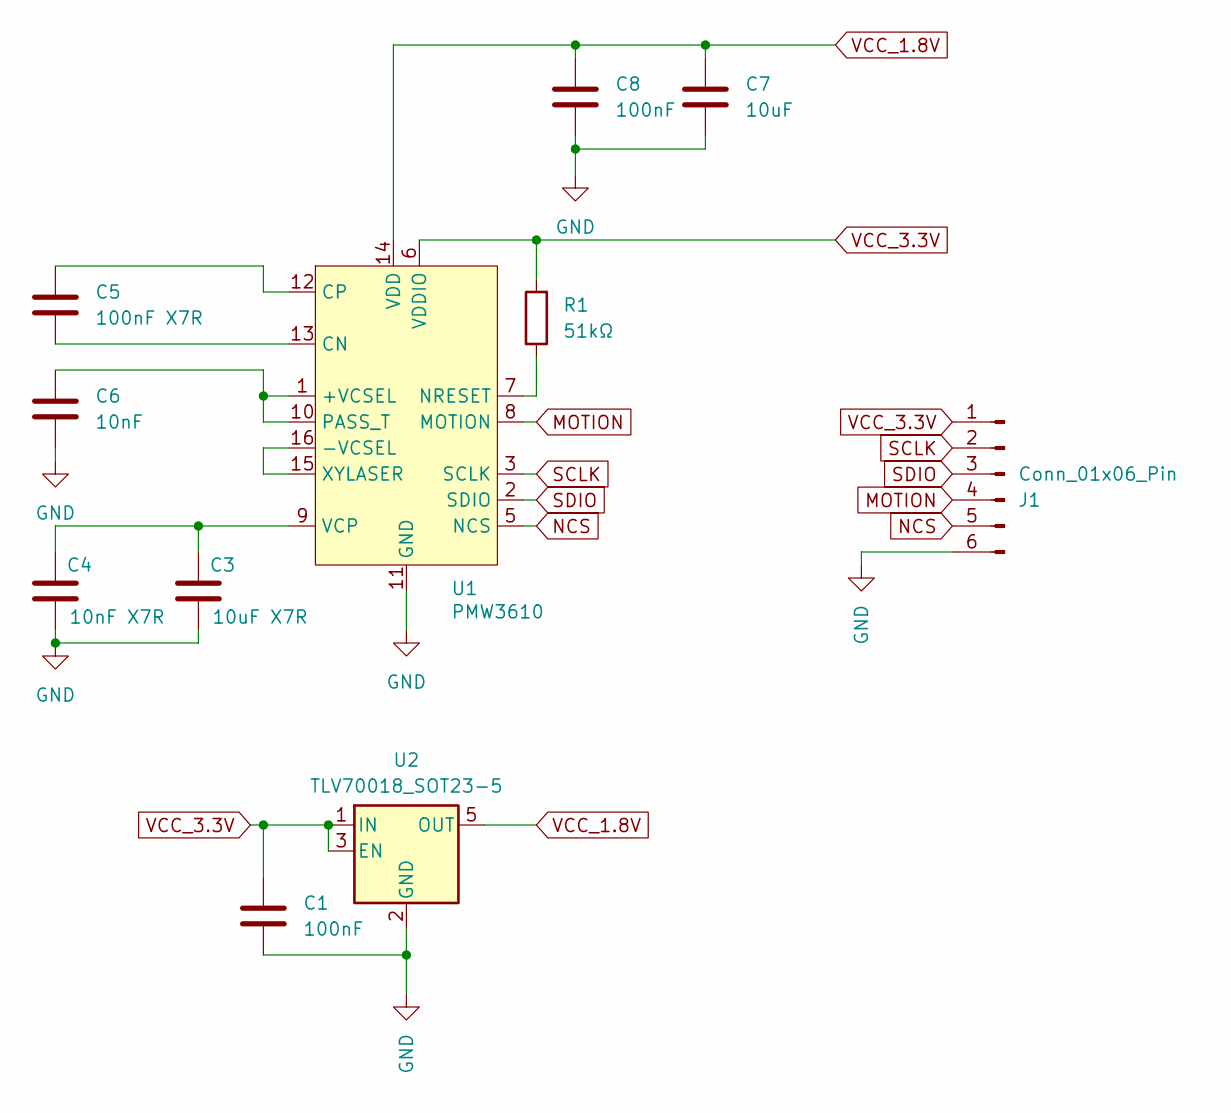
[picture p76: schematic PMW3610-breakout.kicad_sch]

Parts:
C1, C8: 100nF; C_0402_1005Metric; LCSC C1525
C3: 10uF X7R; C_0402_1005Metric; LCSC C15525
C4: 10nF X7R; C_0402_1005Metric; LCSC C15195
C5: 100nF X7R; C_0402_1005Metric; LCSC C1525
C6: 10nF; C_0402_1005Metric; LCSC C15195
C7: 10uF; C_0402_1005Metric; LCSC C15525
J1: Conn_01x06_Pin; JUSHUO-AFH34-S06FIA-1H; LCSC C224194
R1: 51kΩ; R_0402_1005Metric; LCSC C25794
U1: PMW3610; PMW3610DM-SUDU 16Pin
U2: TLV70018_SOT23-5; SOT-23-5; LCSC C79924

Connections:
GND: C1.2, C3.2, C4.2, C6.2, C7.2, C8.2, J1.6, U1.11 (GND), U2.2 (GND)
MOTION: J1.4, U1.8 (MOTION)
NCS: J1.5, U1.5 (NCS)
unnamed: C6.1, U1.1 (+VCSEL), U1.10 (PASS_T)
unnamed: U1.15 (XYLASER), U1.16 (-VCSEL)
unnamed: C5.2, U1.13 (CN)
unnamed: C5.1, U1.12 (CP)
unnamed: R1.1, U1.7 (NRESET)
unnamed: C3.1, C4.1, U1.9 (VCP)
SCLK: J1.2, U1.3 (SCLK)
SDIO: J1.3, U1.2 (SDIO)
VCC_1.8V: C7.1, C8.1, U1.14 (VDD), U2.5 (OUT)
VCC_3.3V: C1.1, J1.1, R1.2, U1.6 (VDDIO), U2.1 (IN), U2.3 (EN)

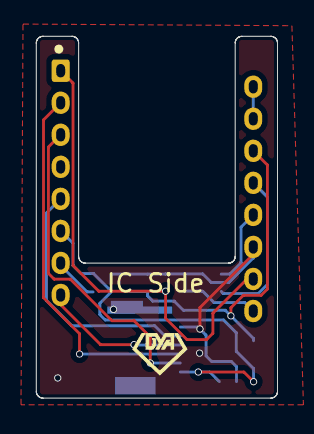
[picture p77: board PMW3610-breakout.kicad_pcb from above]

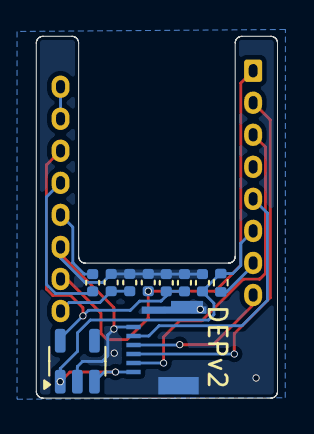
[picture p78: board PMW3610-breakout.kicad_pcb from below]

Board: 2 copper layers, 13.4 x 20.1 mm, 11 parts (10 on the bottom side), 13 nets.

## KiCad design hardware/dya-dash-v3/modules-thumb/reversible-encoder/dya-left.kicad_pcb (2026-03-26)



Board: 2 copper layers, 44.6 x 15.8 mm, 12 parts (6 on the bottom side), 8 nets.

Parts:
J1, J3: FFC; JUSHUO-AFH34-S06FIA-1H
J2: Magnet Connector; PinHeader_1x05_P2.54mm_Vertical
R1, R2, R3, R4, R5, R6: 330Ω; R_0805_2012Metric
SW1, SW2: SW_Push_45deg; SW_Push_1P1T_NO_CK_KSC6xxJ
SWE1: RotaryEncoder_Switch; RotaryEncoder_EC12E

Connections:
3.3V_L: J1.1, J2.1, J3.1
ENC1_LE: R1.2, R5.2, SWE1.B
ENC2_LE: R2.2, R6.2, SWE1.A
GNDLE: J1.5, J1.6, J2.5, J3.5, J3.6, SW1.2, SW2.1, SWE1.C
unnamed: R3.1, R4.1, SW1.1, SW2.2
OUT1: J1.2, J2.2, J3.2, R1.1, R5.1
OUT2: J1.3, J2.3, J3.3, R2.1, R6.1
OUT3: J1.4, J2.4, J3.4, R3.2, R4.2

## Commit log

2025-05-10 Add PCB design
    [PMW3610-breakout.kicad_pcb, PMW3610-breakout.kicad_sch, dya-left.kicad_pcb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]
2025-05-13 Add case data
    [arrow-button.stl, battery-button.stl, bottom.stl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]
2025-05-15 Add warning for damaging top case in build guide
2025-05-16 Remove icon from top plate
    [top-3dp.stl]
2025-05-17 Remove zmk-driver-animation & zmk-driver-ext-power-transient to convert to submodule
2025-05-17 Add zmk-driver-animation & zmk-driver-ext-power-transient as submodule
2025-06-15 Finalize v2
    [dya-left.kicad_sch, dya-panelized.kicad_sch, dya-right.kicad_sch]
2025-06-15 Add case for V2.0
    [Battery.stl, Bottom.stl, LogoPlate.stl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]
2025-06-20 Add warning for FFC cable
2025-06-27 Improve FFC cable related documents and add warning2 for ffc
2025-07-24 Add note about battery pin
2025-08-10 Update about trackball case improvement
2025-08-10 Update case design for V2
    [Battery.stl, Bottom.stl, Case_DualTrackball_NoArrow.stl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]
2025-08-11 Update case build guide for POM ball supported trackball case
2025-08-15 Add guide for switch pad & warning for power switch cover
2025-11-14 Add the latest case model
    [DyaDash.step, Trackball.stl]
2025-11-14 Add missing parts
    [ArrowButton.step, BatterySwitch.stl]
2025-11-16 Add bottom case for left trackball
    [DyaDashBottomCaseLeftTrackball.step]
2026-03-26 Add V3 model and build guide
    [5pin-magnet-fpc.kicad_pcb, 5pin-magnet-fpc.kicad_sch, PMW3610-breakout.kicad_pcb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]
2026-03-29 Update docs for 24mm ball
